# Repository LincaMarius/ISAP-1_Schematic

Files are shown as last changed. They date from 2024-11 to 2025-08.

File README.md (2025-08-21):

# ISAP-1 Computer Schematic
The ISAP-1 computer is the improved version of the SAP-1 computer made by me.

ISAP Computer stands for Improved Simple as Possible Computer

This is the stage of choosing the electronic components used to make the ISAP-1 computer and designing the Schematic.

By: Lincă Marius Gheorghe

https://github.com/LincaMarius

## About the project, brief description
The goal of this project is to create a more efficient version of the SAP (Simple As Possible) computer, but with minimal changes so that the instruction format remains the same.

This project is part of a project made by me:
https://github.com/LincaMarius/ISAP-Computer

where I optimized the SAP-1 computer

## ISAP-1 TTL Computer version 0.1
Version 0.1 of the ISAP-1 computer is based on the original SAP-1 computer schematic.

The structure of the SAP-1 computer and by implication the ISAP-1 computer is:

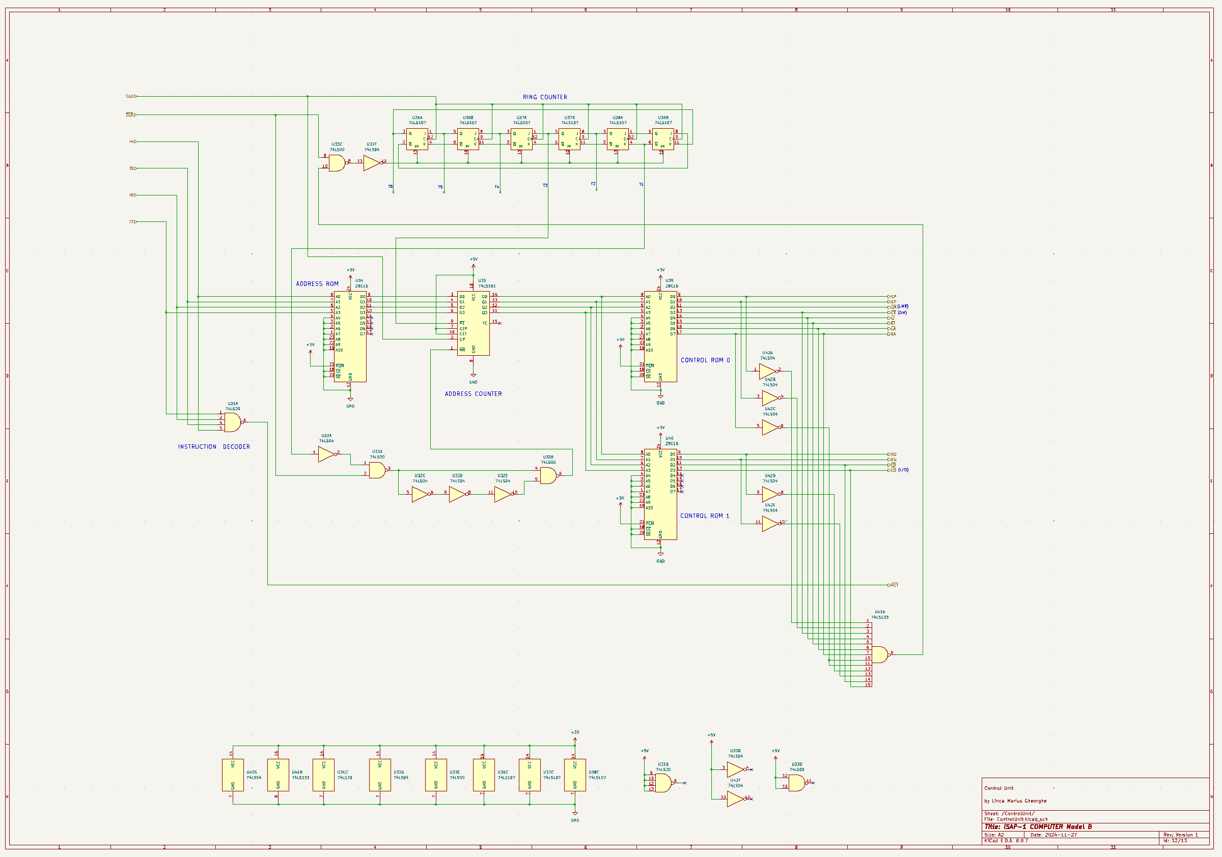
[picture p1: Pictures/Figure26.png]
Figure 26


I want to make the ISAP-1 computer in modular form. So I modified the Structural Diagram like this:

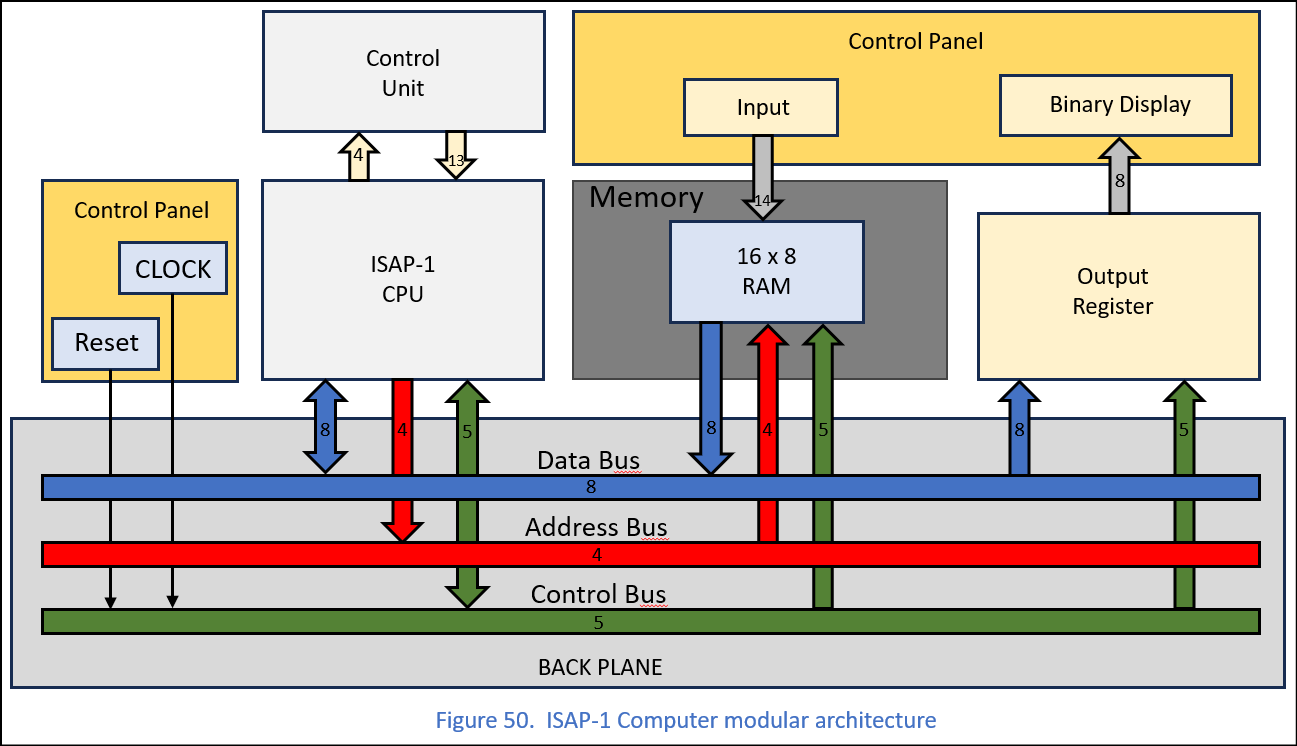
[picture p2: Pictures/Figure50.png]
Figure 50


It turns out that we will have the following modules:
- Reset and Clock
- ISAP-1 CPU
- Control Unit
- RAM Memory
- Output Display
- Back Plane

The SAP-1 computer was designed using 7400 series TTL chips in the LS (Low-Power Schottky) variant. Since version 0.1 of the ISAP-1 computer will be an almost identical copy of the SAP-1 computer, I will still use TTL technology.

I will keep the chip numbering order according to the original schematic of the SAP-1 computer.

### Central Processing Unit Schematic
The first module designed is the Central Processing Unit module.

The original block diagram of the Central Processing Unit of the SAP-1 computer and implicitly of the ISAP-1 computer is:

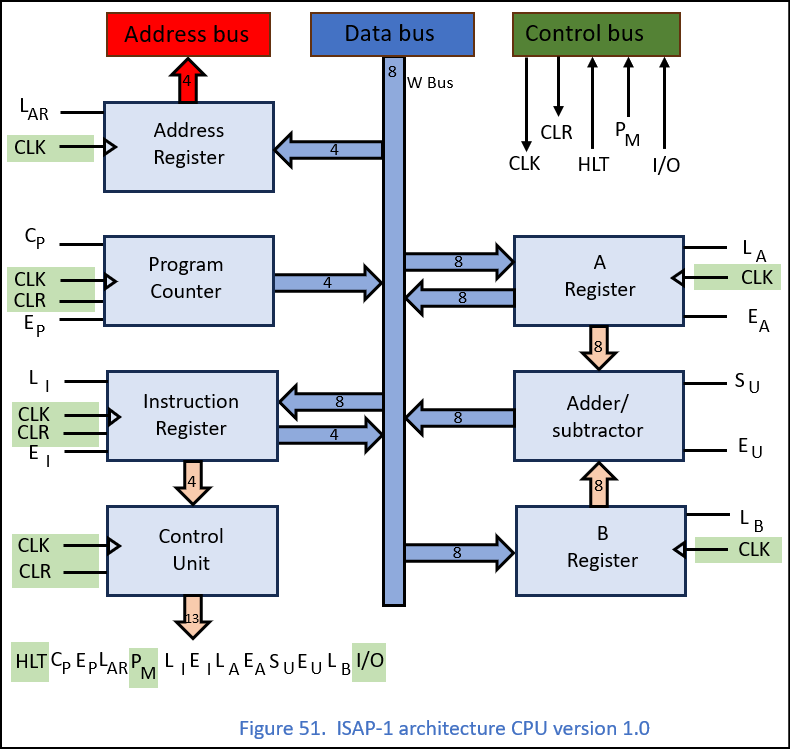
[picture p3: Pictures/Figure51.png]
Figure 51


Initially, I used Altium Designer to design the Schematic and PCB.

But, so that this schematic can be viewed and possibly edited by anyone, I put the version edited with KiCAD on GitHub, because this program is free and can be freely used by anyone.

The implemented schematic will be almost identical to the original one of the SAP-1 Computer.

In the original schematic the chips are labeled C1 to C48. To eliminate confusion with the capacitor notation I have used the chip notation U1 to U49 as is used in modern days.

First I will implement the Central Processing Unit which has the following schematic:

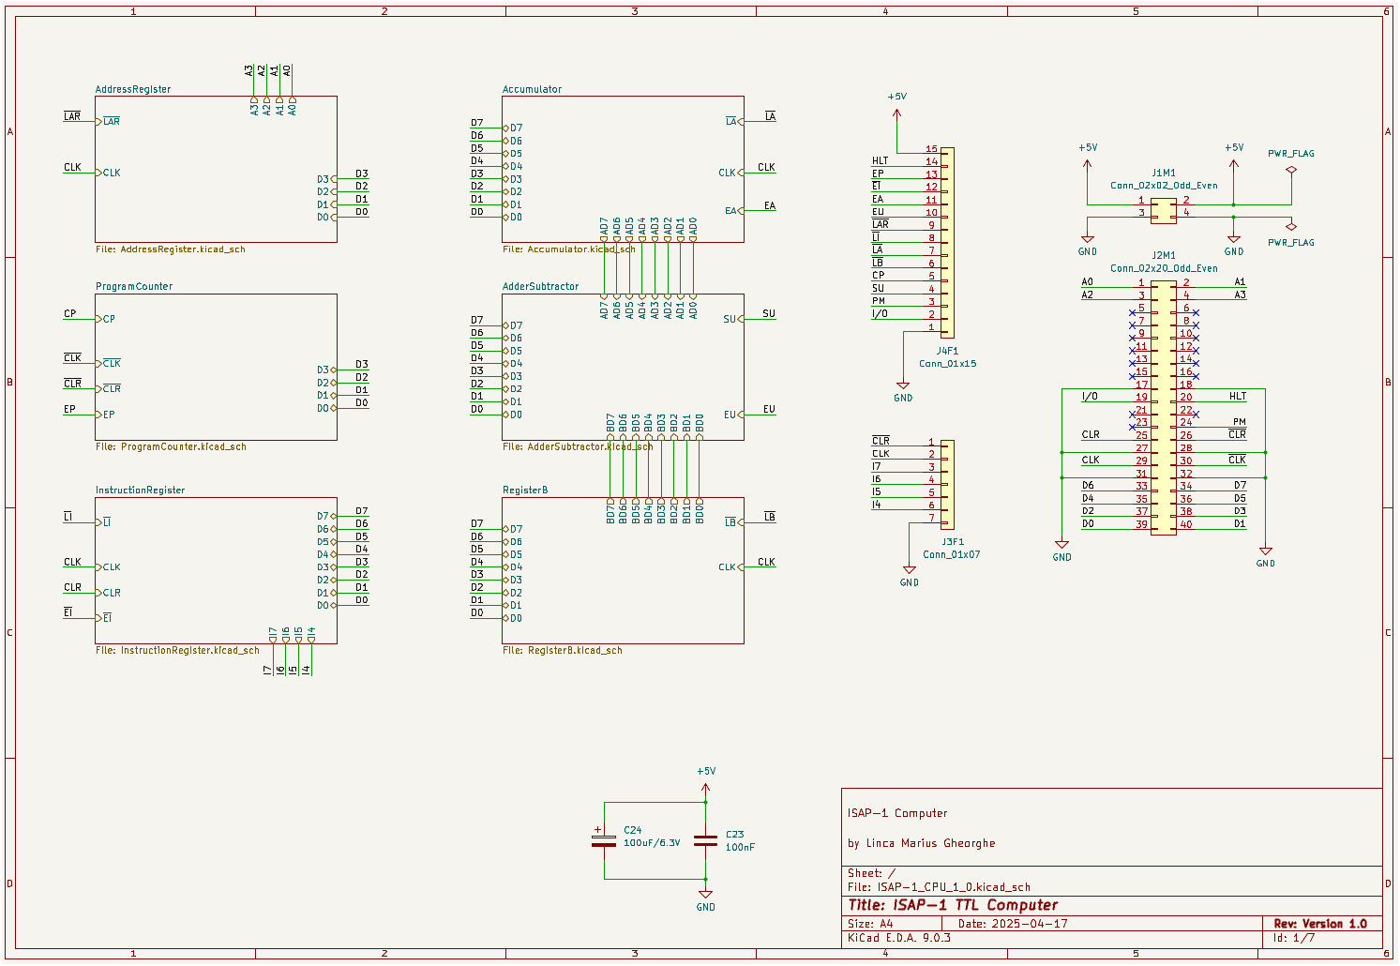
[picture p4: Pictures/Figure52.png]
Figure 52


You can see all the functional blocks in the diagram in figure 51. In addition I added decoupling capacitors for the power supply circuit. We also have the J1M connectors for connecting to the supply voltage given by the Back Plane, the J2M connector for connecting to the three system buses located on the Back Plane. The J3F and J4F connectors are used to allow the Control Block module to be attached to the CPU module.

#### Program Counter Schematic
In the original schematic, the authors used 4 Flip-Flops connected in such a way that they form a Binary Counter. For implementation, two 74LS107 were used for this purpose.

Counting is done when the CP control signal is active and the falling edge of the clock signal appears.

This action occurs for any instruction during [ microstep T2 ](https://github.com/LincaMarius/ISAP-1_Instruction_Set/blob/main/Pictures/Figure3.png).

The Program Counter has its output connected to the Bus, therefore it must be Tri-State. A 74LS126 chip is used for this purpose

The output is active only when the EP control signal is high.

This action occurs for any instruction during [ microstep T1 ](https://github.com/LincaMarius/ISAP-1_Instruction_Set/blob/main/Pictures/Figure3.png).

The Schematic does has no changes from the original one.

The original schematic has no decoupling capacitors for the chips. For the computer's operating speed of 1kHz this may not matter.

I added a 100nF decoupling capacitor for each chip used in order to eliminate high-frequency noise propagation along the power supply path.

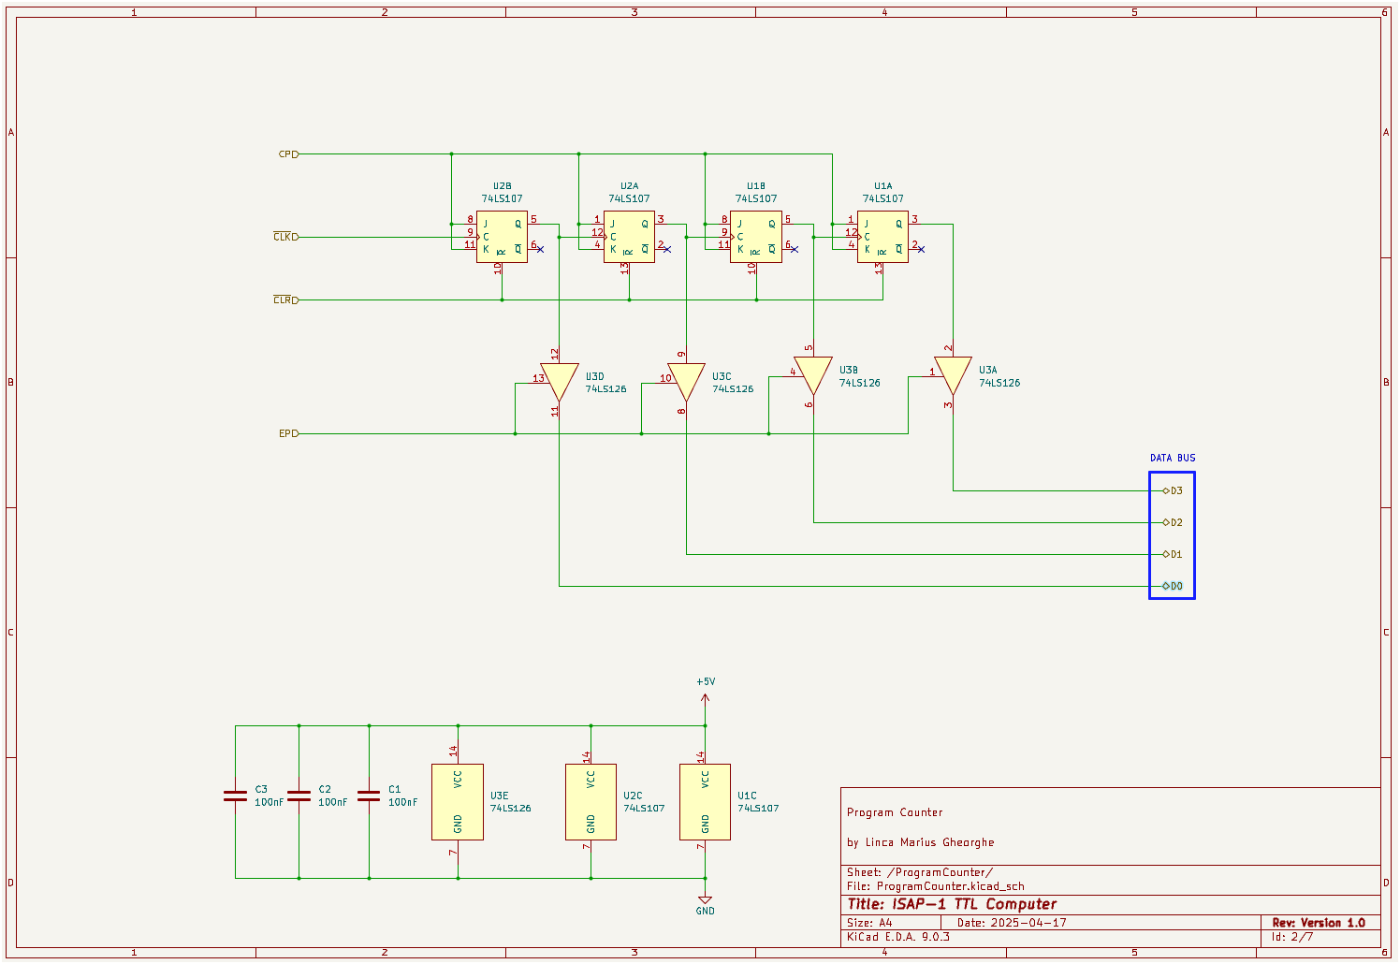
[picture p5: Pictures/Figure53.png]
Figure 53


#### Address Register Schematic
In the original schematic, the authors used a 4-bit register using the 74LS173 chip which has a permanently active output.

Note that the connection of the inputs to the data bus is in reverse order in the original SAP-1 computer schematic, D0 is connected to pin 11, D1 is connected to pin 12, D2 is connected to pin 13 and D4 is connected to pin 14.

The outputs are also connected in the reverse order. The operation of the SAP-1 computer is not affected by this order because the correspondence between inputs and outputs is maintained.

The current schematic has no changes from the original schematic.

I added a 100nF decoupling capacitor to the chip used in order to eliminate high-frequency noise propagation on the power supply path.

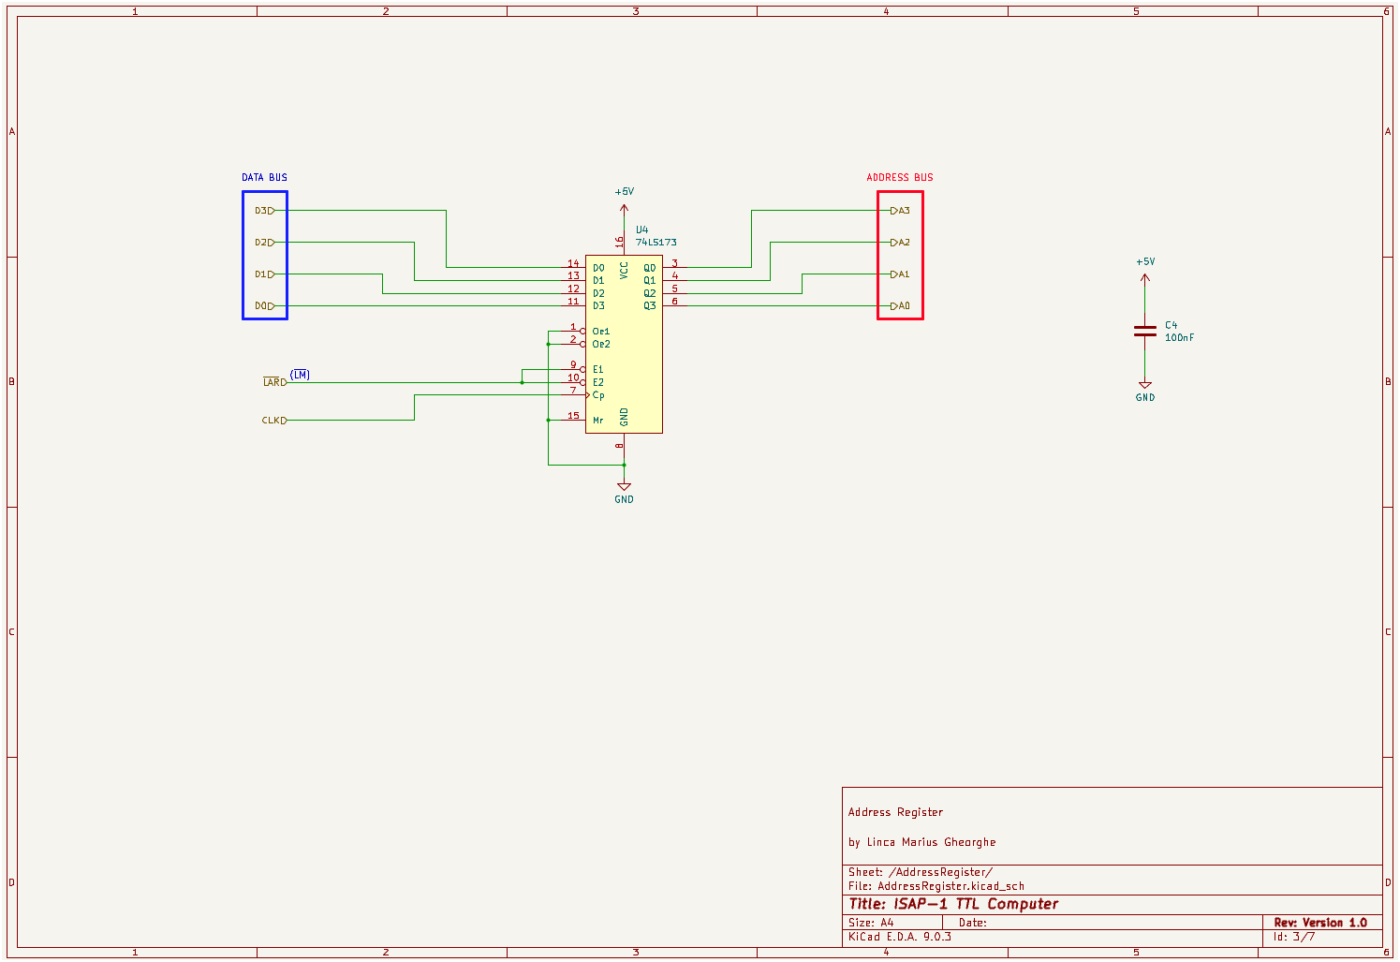
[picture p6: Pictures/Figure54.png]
Figure 54


#### Instruction Register Schematic
The Instruction Register is made using two integrated circuits of the 74LS173 type which is a 4-bit register.

The first chip marked U8 in the diagram stores the upper nibble which represents the binary code of the instruction being executed.

The second chip marked in the diagram U9 stores the lower nibble which represents the parameter for the instruction being executed.

According to the datasheet for the 74LS173 chip, pin 14 is D0 and the corresponding output Q0 is pin 3, pin 13 is D1 and the corresponding output Q1 is pin 4, pin 12 is D2 and the corresponding output Q2 is pin 4, and pin 11 is D3 and the corresponding output Q3 is pin 6.

But in the SAP-1 computer schematic, pin 14 which is D0 and pin 3 which is Q0 are connected to bit 3 of the W Bus, pin 13 which is D1 and pin 4 which is Q1 are connected to bit 2 of the W Bus, pin 12 which is D2 and pin 5 which is Q2 are connected to bit 1 of the W Bus and pin 11 which is D3 and pin 6 which is Q3 are connected to bit 0 of the W Bus.

So, the order of inputs and outputs is reversed. Since the inputs and outputs are also reversed accordingly, the operation of the SAP-1 computer is normal.

The schematic does not present any changes from the original.

I added a 100nF decoupling capacitor for each chip used in order to eliminate high-frequency noise propagation along the power supply path.

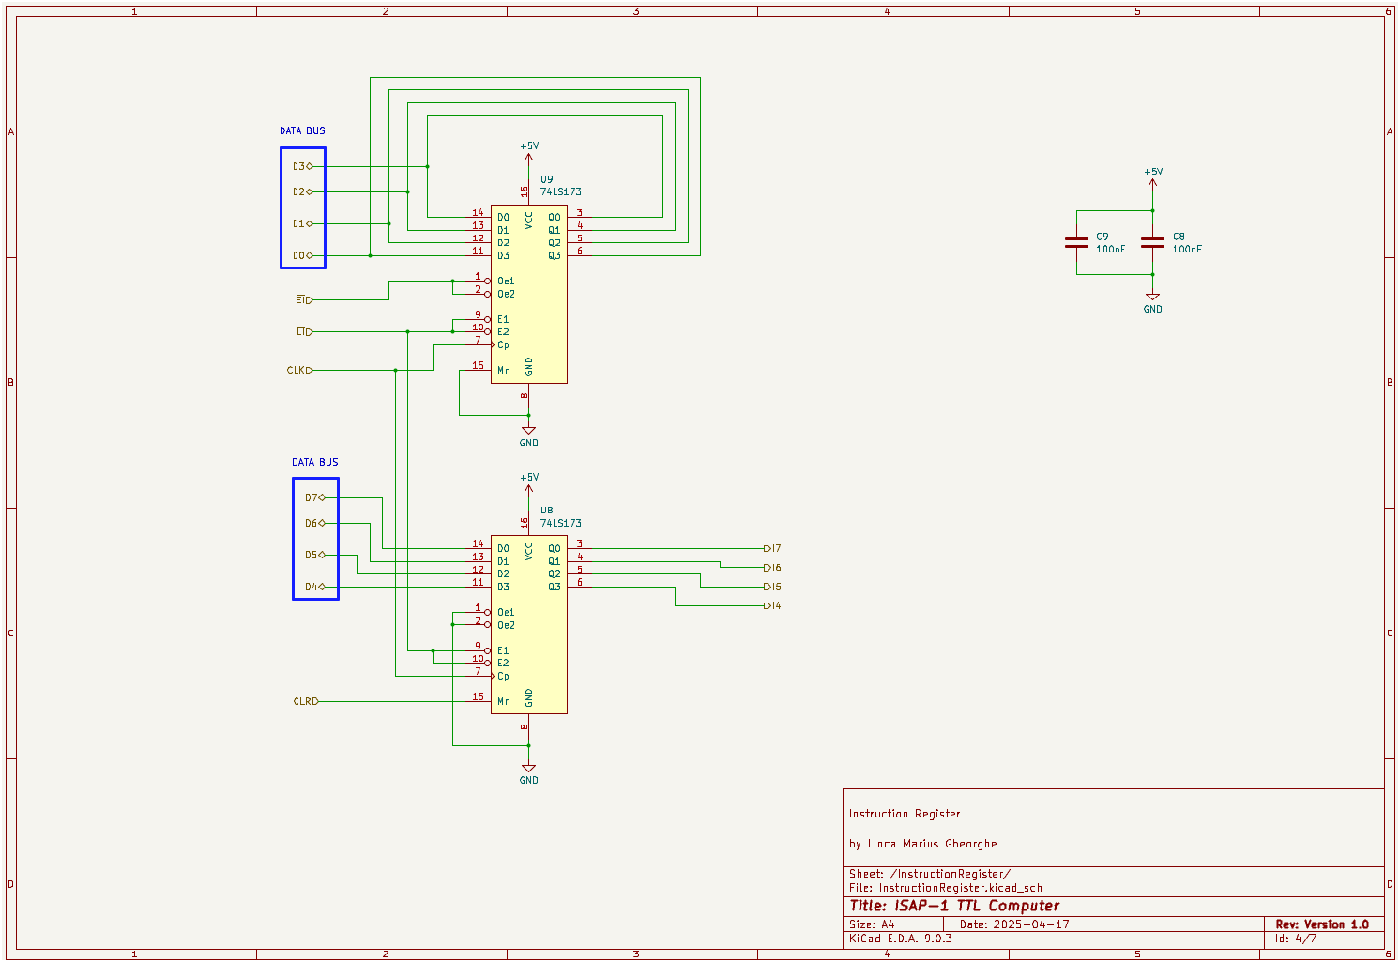
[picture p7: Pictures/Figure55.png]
Figure 55


#### Accumulator Register Schematic
The Accumulator register is made using two 4-bit 74LS173 type registers marked U10 and U11 in the diagram (in the original diagram they are marked C10 and C11).

Pin 1 and pin 2 are connected to ground which causes the outputs to be permanently active. Thus, the contents of the Accumulator Register are permanently transmitted to the ALU via signals AD0 to AD7.

The contents of the Accumulator Register are put on the bus when the EA control signal is active, which activates the 8 Tri-State drivers. The Tri-State drivers are implemented using two 74LS126 chips, each containing 4 Tri-State drivers.

As in the previous cases, the order of inputs and outputs is reversed from the order of the bits on the W bus. Since the inputs and outputs are also reversed accordingly, the operation of the SAP-1 computer is normal.

The schematic has no changes from the original.

I added a 100nF decoupling capacitor for each chip used in order to eliminate high-frequency noise propagation along the power supply path.

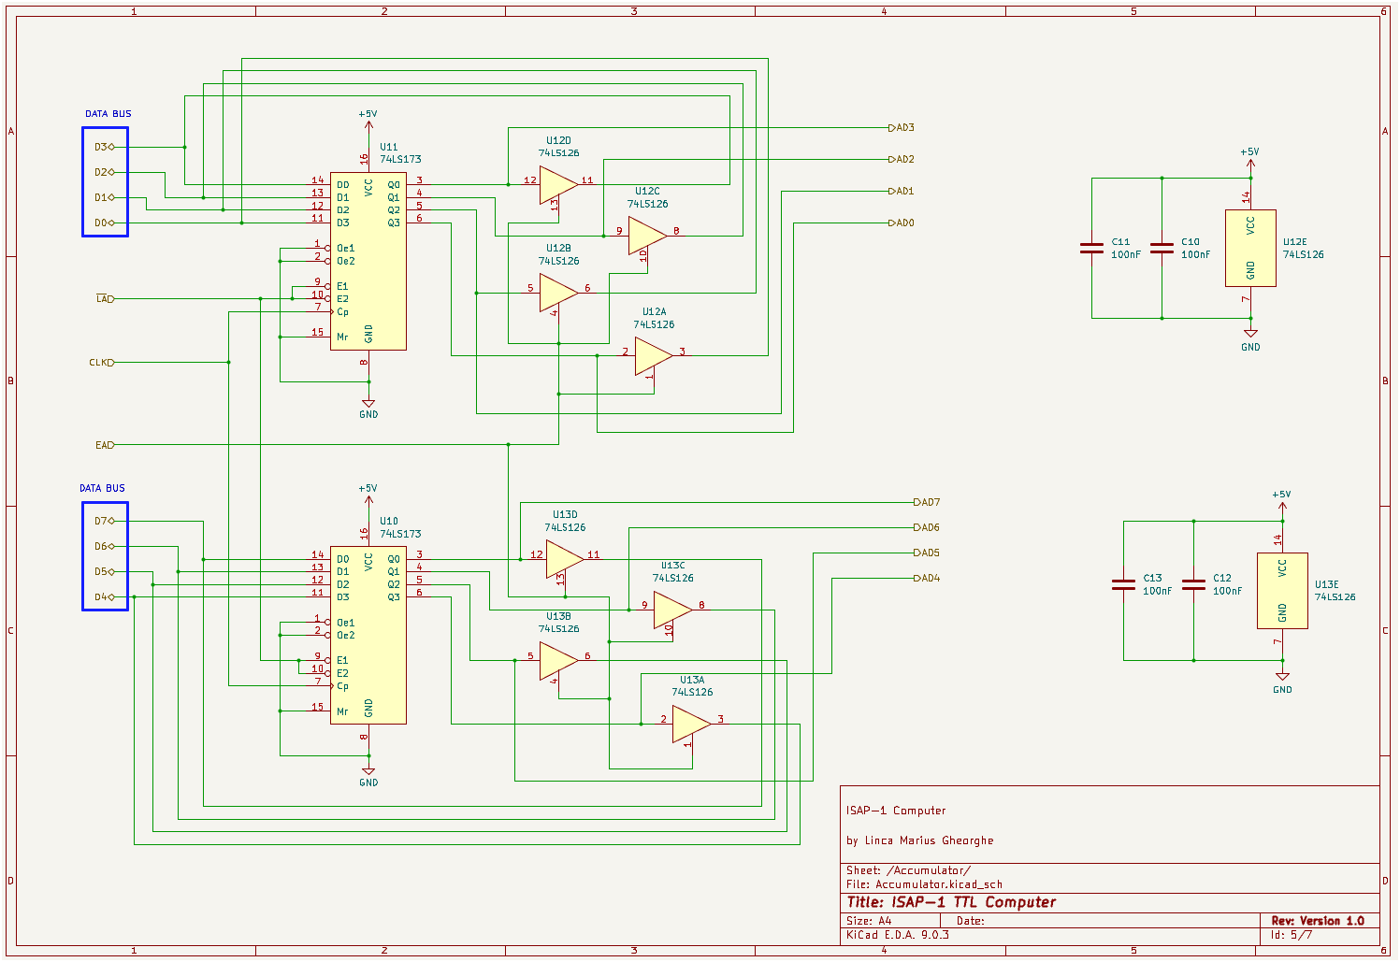
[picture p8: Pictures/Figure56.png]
Figure 56


#### Adder / Subtractor Schematic
The SAP-1 computer has no Logic Unit, it can only perform the Addition and Subtraction operations.

The main element of the Arithmetic Unit is the 74LS83 chip which is a 4-bit Full Adder, so two such chips are used.

The Subtract Operation is performed by 2's Complementing the operand B. For this purpose, 8 x XOR Gates are used. Each 74LS86 chip has 4 gates, so 2 chips are used.

The result is transmitted on the Bus via 8 three-state buffers when the EU control signal is active. These buffers are of the 74LS126 type. Each chip has 4 buffers, so 2 chips are required.

The schematic has no changes from the original.

I added a 100nF decoupling capacitor for each chip used in order to eliminate high-frequency noise propagation along the power supply path.

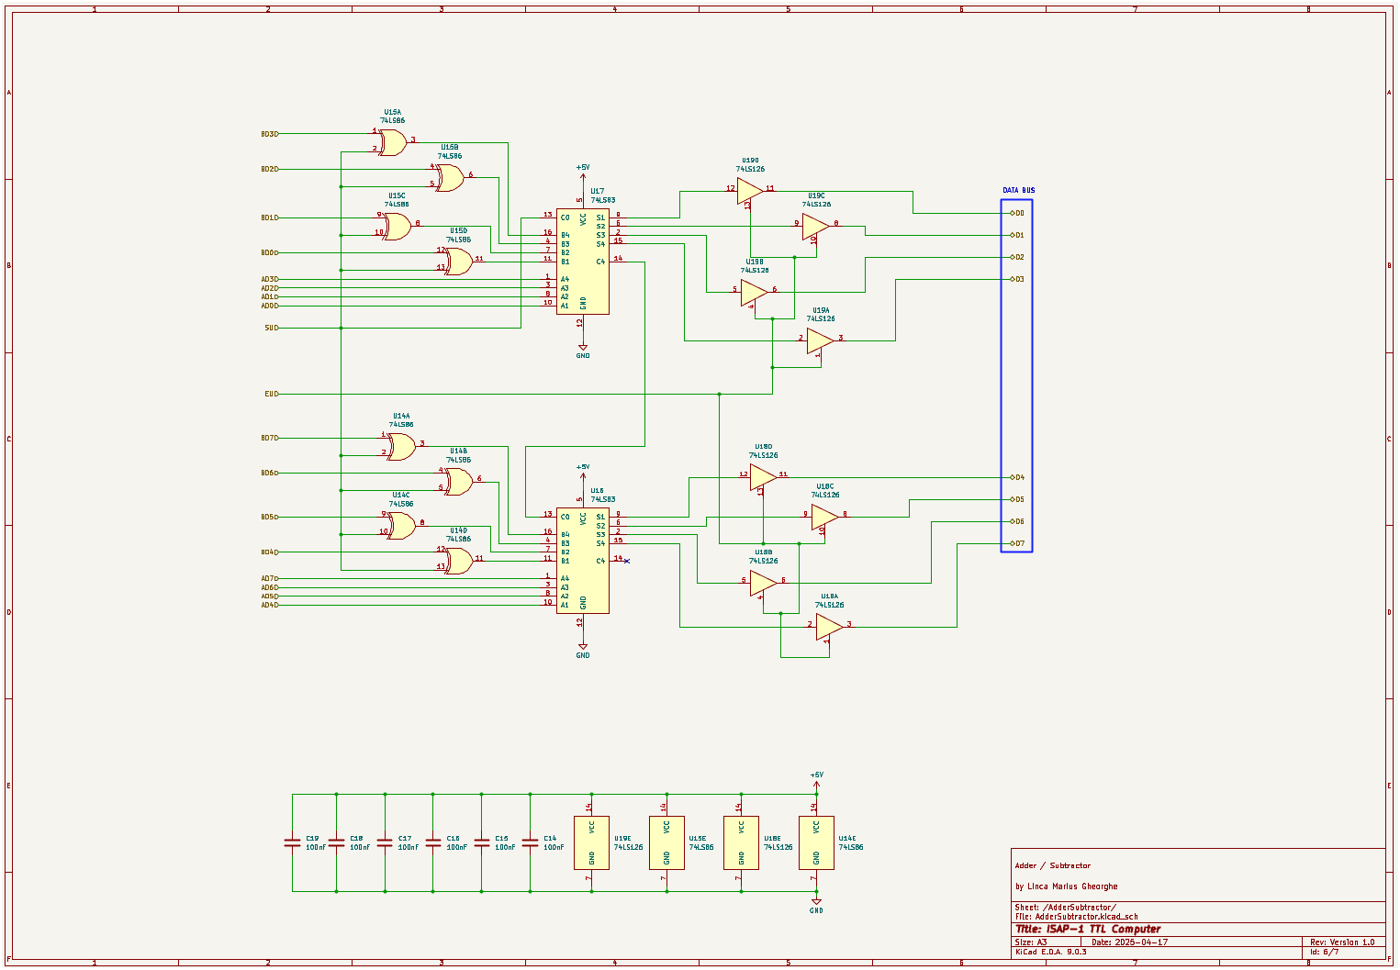
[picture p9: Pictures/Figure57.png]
Figure 57


#### Register B Schematic
Register B acts as a temporary storage register, where the operand B required by the Adder to perform the Addition operation is loaded.

In the original schematic, two 4-bit 74LS173 type registers labeled C20 and C21 are used.

When the LB control signal is low and the rising edge of the clock signal occurs, the data present on the Bus is loaded into the registers.

The output is connected to input B of the Adder and is permanently enabled by connecting pins 1 and 2 to ground.

The schematic has no changes from the original.

I added a 100nF decoupling capacitor for each chip used in order to eliminate high-frequency noise propagation along the power supply path.

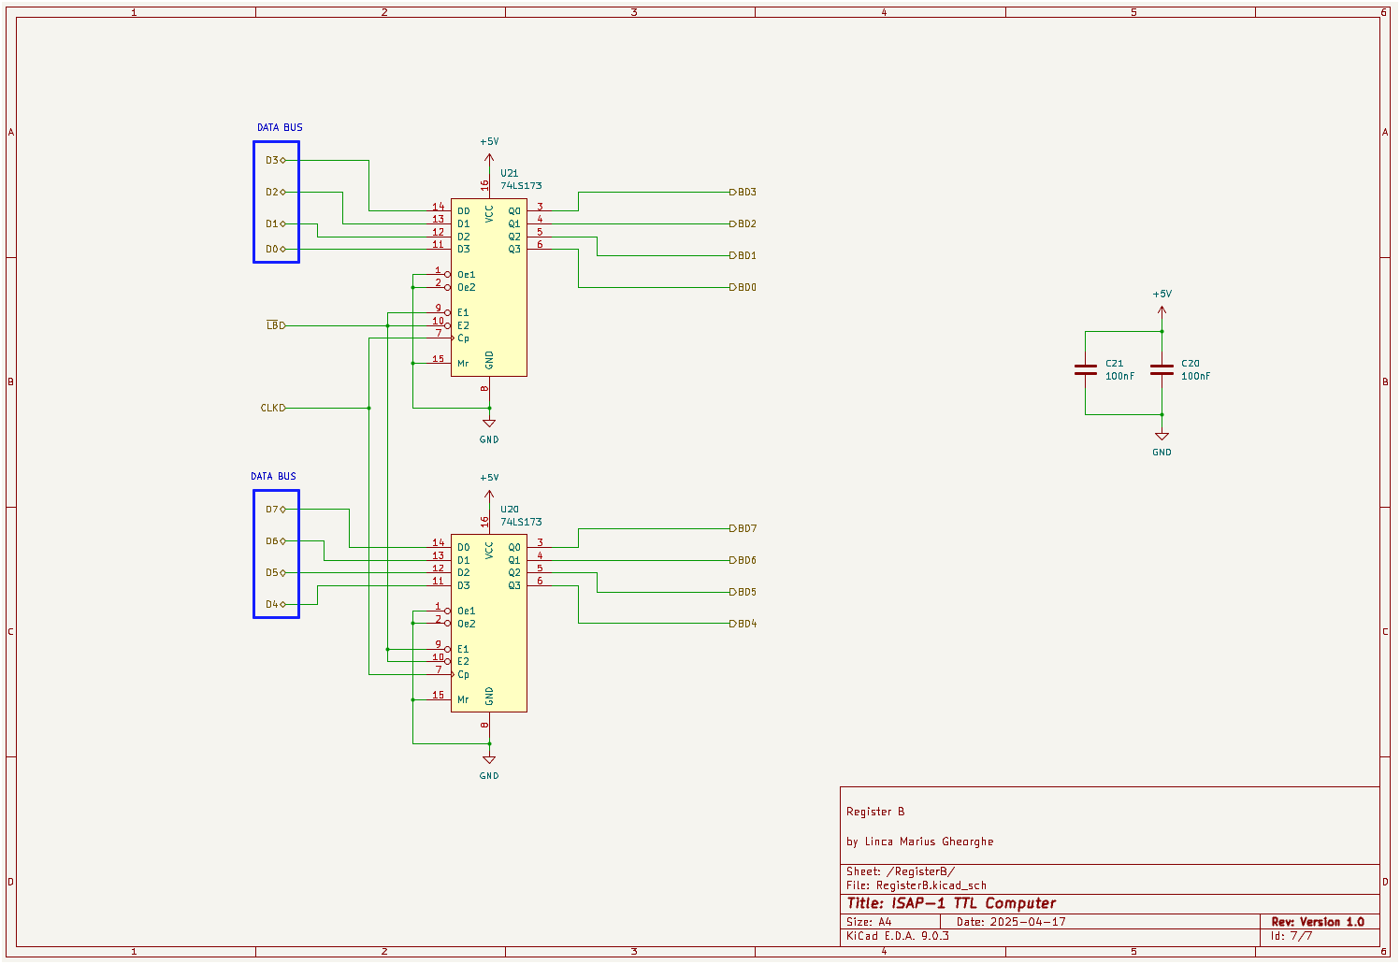
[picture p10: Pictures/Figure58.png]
Figure 58


The archived project for ISAP-1 TTL Computer version 0.1 is here: \
https://github.com/LincaMarius/ISAP-1_Schematic/blob/main/KiCAD/ ISAP-1_TTL_CPU_1_0.zip

### Control Unit Schematic
The Control Unit's role is to direct the flow of data between the various Blocks of the Computer to ensure its operation and achieve the expected results.

It consists of three elements: the Instruction Decoder, the Ring Counter and the Control Matrix as can be seen in figure 14:

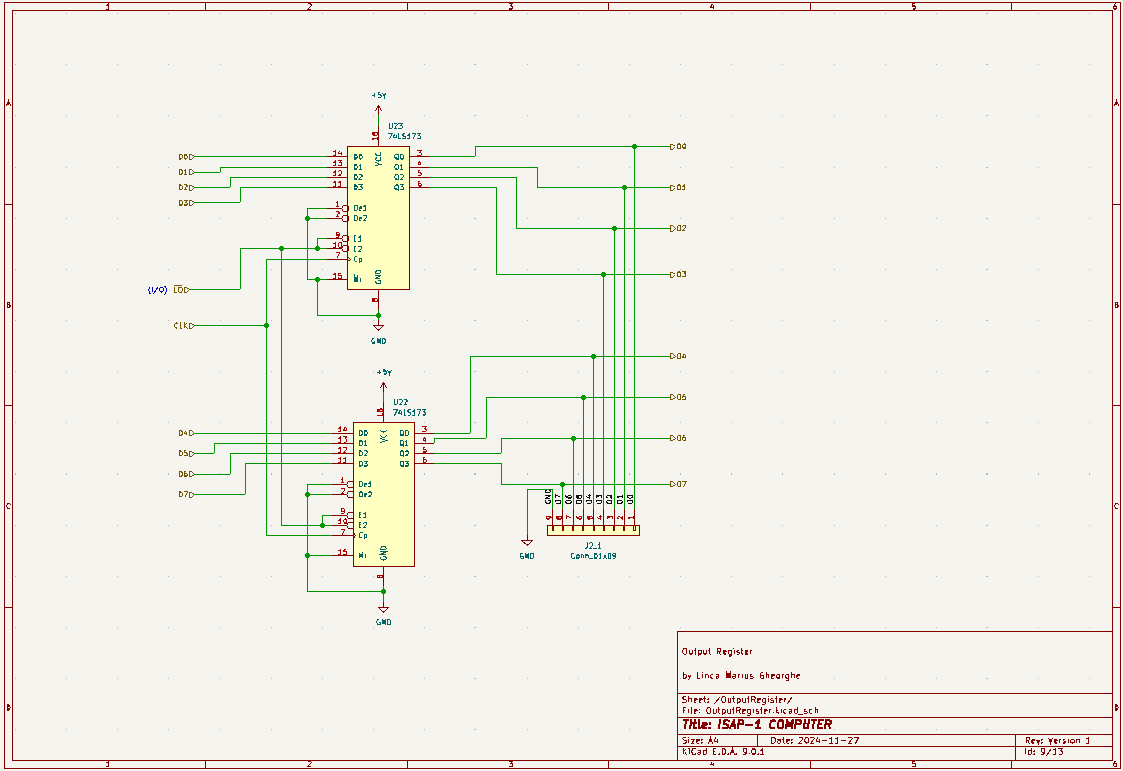
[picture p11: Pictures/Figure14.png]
Figure 14


### Output Device – Binary Display
In the SAP-1 computer the output device is called the Output Register and is present in the Block Diagram at the bottom right of the drawing.

The Binary Display is made with 8 LEDs connected directly to the output of the Output Register.

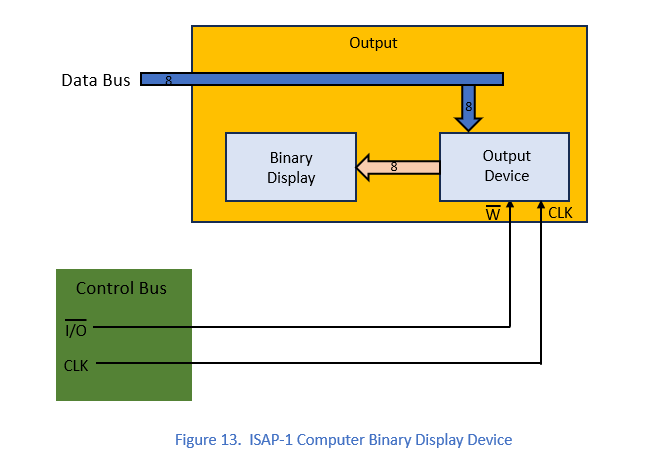
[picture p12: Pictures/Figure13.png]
Figure 13


### Output Device Schematic
In the original schematic, two 4-bit 74LS173 registers are used, denoted C22 and C23.

When the I/O control signal (the original LO) is low and the rising edge of the clock signal appears, the data present on the Bus is loaded into the registers.

The output is permanently active because pins 1 and 2 are connected to ground. The outputs are labeled O0 to O7.

I added the connectors marked J2_1 and J2_2 for connection to the Base PCB in case the Binary Display PCB separates from the computer PCB.

The schematic does not present any other changes compared to the original one.

Figure 14

### Binary Display Schematic
The Binary Display consists of eight LEDs connected to eight current limiting resistors of 1k ohm each.

The current is limited by resistors for a red LED to the value of (Voh – Vled) / (R + Rint) = (2.4V – 1.8V) / (1000 + 100) = 0.5 / 1100 = 0.5mA (theoretical).

I added the connectors marked J2_1 and J2_2 for connection to the Base PCB in case the Binary Display PCB separates from the computer PCB.

The schematic does not present any other changes compared to the original one.

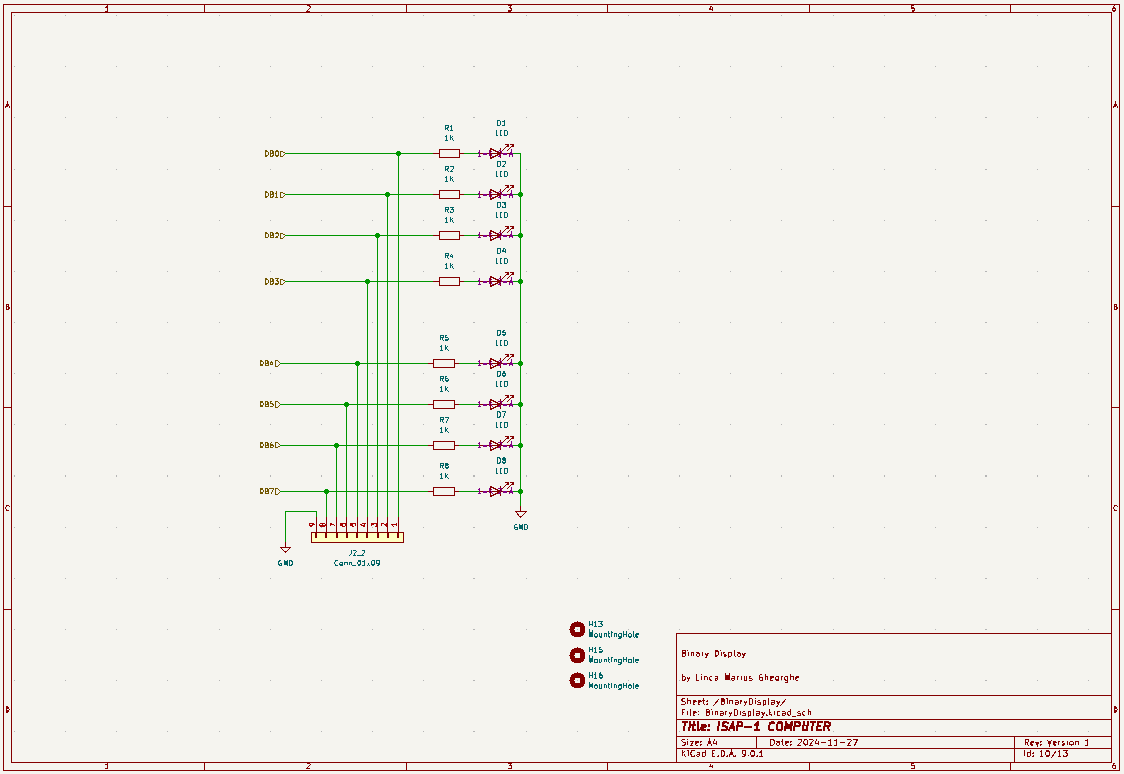
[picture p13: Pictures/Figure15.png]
Figure 15


### Front Panel Schematic
The Front Panel provides the user interface. Contains the Reset circuit, Manual/Automatic mode selector, Step button, main clock.

I added two connectors marked J5_1 and J5_2 for connection to the Base PCB in case the Front Panel PCB is separated and used separately from the ISAP-1 computer PCB.

The switches can be mounted on this PCB or mounted on a Front Panel and connected via wires.

The schematic does not present any other changes compared to the original one.

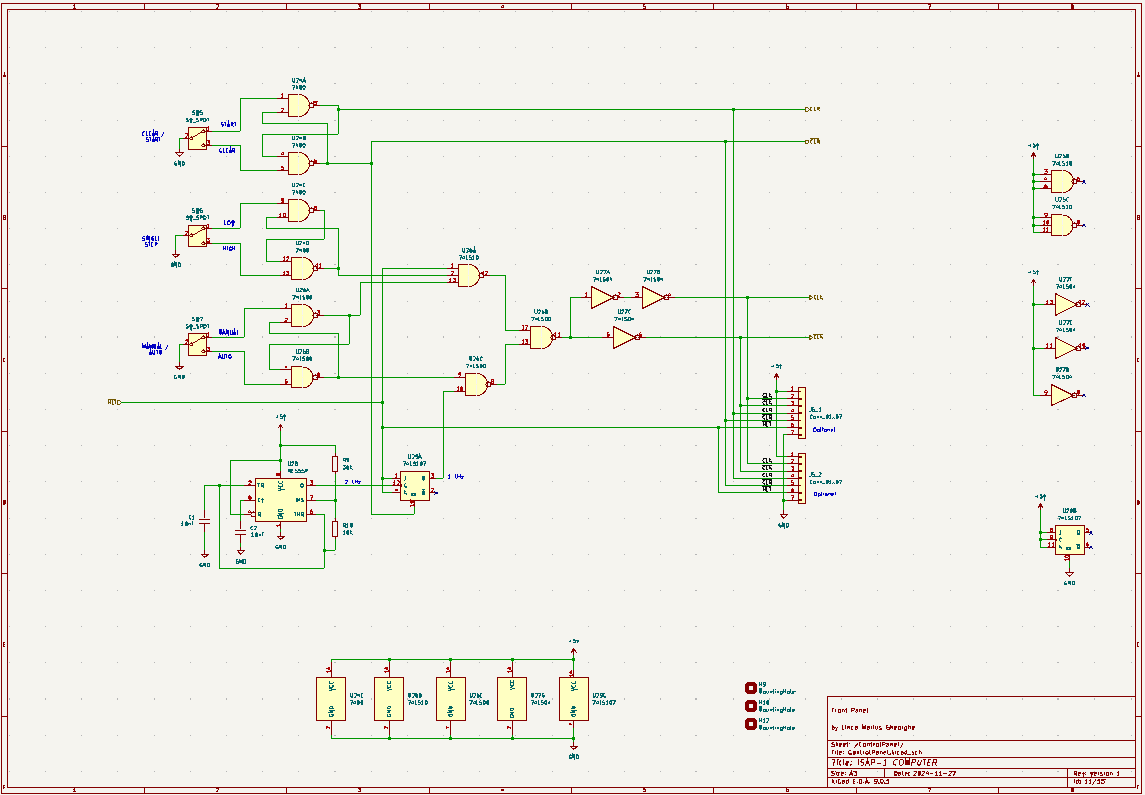
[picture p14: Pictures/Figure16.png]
Figure 16


The switches used to set the Memory in Programming mode must also be placed on the Front Panel.

The switches can be mounted on this module or mounted on a Front Panel and connected via wires.

### Control Unit Schematic
The Control Unit's role is to direct the flow of data between the various Blocks of the Computer to ensure its operation and achieve the expected results.

It consists of three elements: the Instruction Decoder, the Ring Counter and the Control Matrix as can be seen in figure 17:

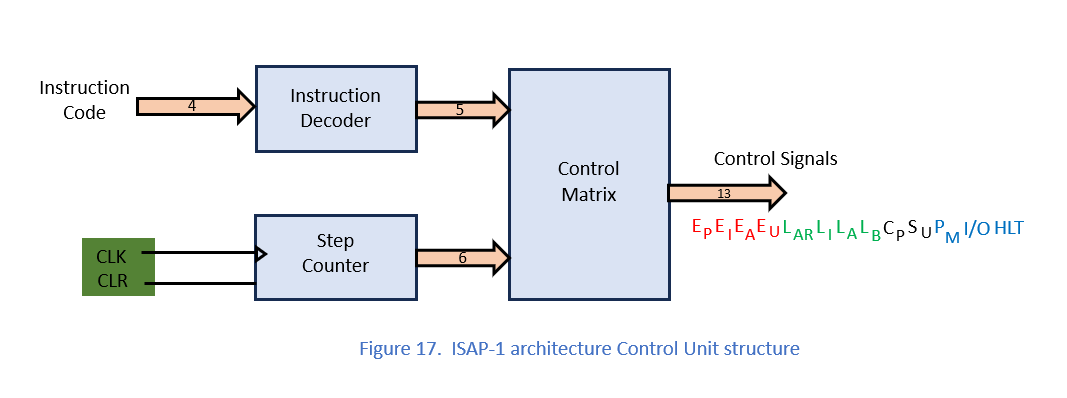
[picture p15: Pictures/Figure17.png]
Figure 17


The schematic does not present any other changes compared to the original one.

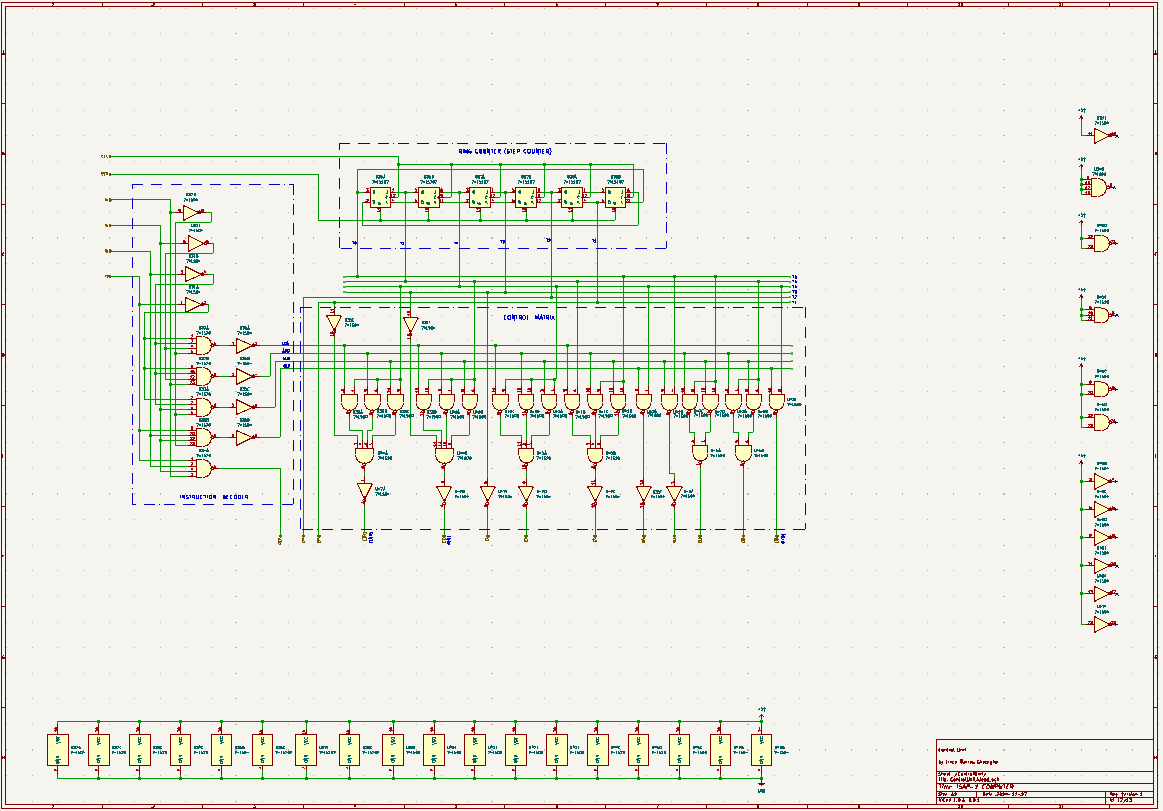
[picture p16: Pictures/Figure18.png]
Figure 18


### Power Supply Schematic 
The power supply's role is to provide the 5 Volt supply voltage and support the computer's power consumption.

This power supply is powered directly from the Mains and consists of a step-down transformer followed by a full bridge rectifier and an integrated regulator of 5 Volts.

The transformer according to the Bill of Materials is of the F-25X type and has a primary voltage of 115 Volts, but in Europe a transformer with a primary voltage of 230 Volts is required.

The secondary voltage according to the Materials List on page 502 in the original book is 12.6 Volts. Nowadays we can buy standard transformers with a secondary voltage of 12 Volts.

The secondary current is a maximum of 1.5 Amps according to the same description.

The nominal power of the transformer for a current consumption of maximum 1.5 Amps is 12V x 1.5A = 18 VA.

The maximum voltage on capacitor C68 is: Vmax = Vsec * 1.41 – 2 * Vd = 12 * 1.414 – 2 * 0.8 = 16.97 – 1.6 = 15.37 Volts

Therefore, capacitor C68 must have a working voltage of 25 Volts.

The voltage ripple on the filter capacitor C68 is: dU = (Iout * T) / (2 * C3)

For a mains voltage frequency of 50 Hz we have T = 1/f = 1/50 = 0.02 s

For a mains voltage frequency of 60 Hz we have T = 1/f = 1/50 = 0.017 s

Since we have a double alternating rectification the pulsation frequency is doubled, so the period is halved

Thus the ripple period is: T = 0.01s for mains voltage with a frequency of 50 Hz and T = 0.0083s for mains voltage with a frequency of 60 Hz.

The voltage ripple on the filter capacitor C68 is: dU = (1.5A * 0.01s) / (2 * 0.001F) = 0.015 / 0.002 = 7.5 Volts for mains voltage with a frequency of 50 Hz.

The voltage ripple on the filter capacitor C68 is: dU = (1.5A * 0.0083s) / (2 * 0.001F) = 0.01245 / 0.002 = 6.225 Volts for mains voltage with a frequency of 60 Hz.

The minimum voltage on the filter capacitor C68 is: Vmin = Vmax – dU = 15.37V – 7.5V = 7.87 Volts for mains voltage with a frequency of 50 Hz.

The minimum voltage on the filter capacitor C68 is: Vmin = Vmax – dU = 15.37V – 6.225V = 9.145 Volts for mains voltage with a frequency of 60 Hz.

The average voltage on the filter capacitor C68 is: V = Vmax – dU/2 = 15.37V – 7.87V/2 = 15.37V – 3.935V = 11.435 Volts for mains voltage with a frequency of 50 Hz.

The average voltage on the filter capacitor C68 is: V = Vmax – dU/2 = 15.37V – 6.225V/2 = 15.37V – 3.1125V = 12.2575 Volts for mains voltage with a frequency of 60 Hz.

The maximum power dissipated by the LM340T-5 or LM7805 integrated regulator is: P = (Vin – Vout) * I = (11.435V – 5V) * 1.5A = 6.435V * 1.5A = 9.66 Watts for mains voltage with a frequency of 50 Hz.

The maximum power dissipated by the LM340T-5 or LM7805 integrated regulator is: P = (Vin – Vout) * I = (12.2575V – 5V) * 1.5A = 7.2575V * 1.5A = 10.87 Watts for mains voltage with a frequency of 60 Hz.

To dissipate this power, we have provided a radiator to cool the integrated stabilizer. Otherwise, it will go into overtemperature protection.

I added a 100nF ceramic capacitor to the input and output of the integrated voltage regulator to meet the stability requirements according to the datasheet data.

The schematic does not present any other changes compared to the original one.

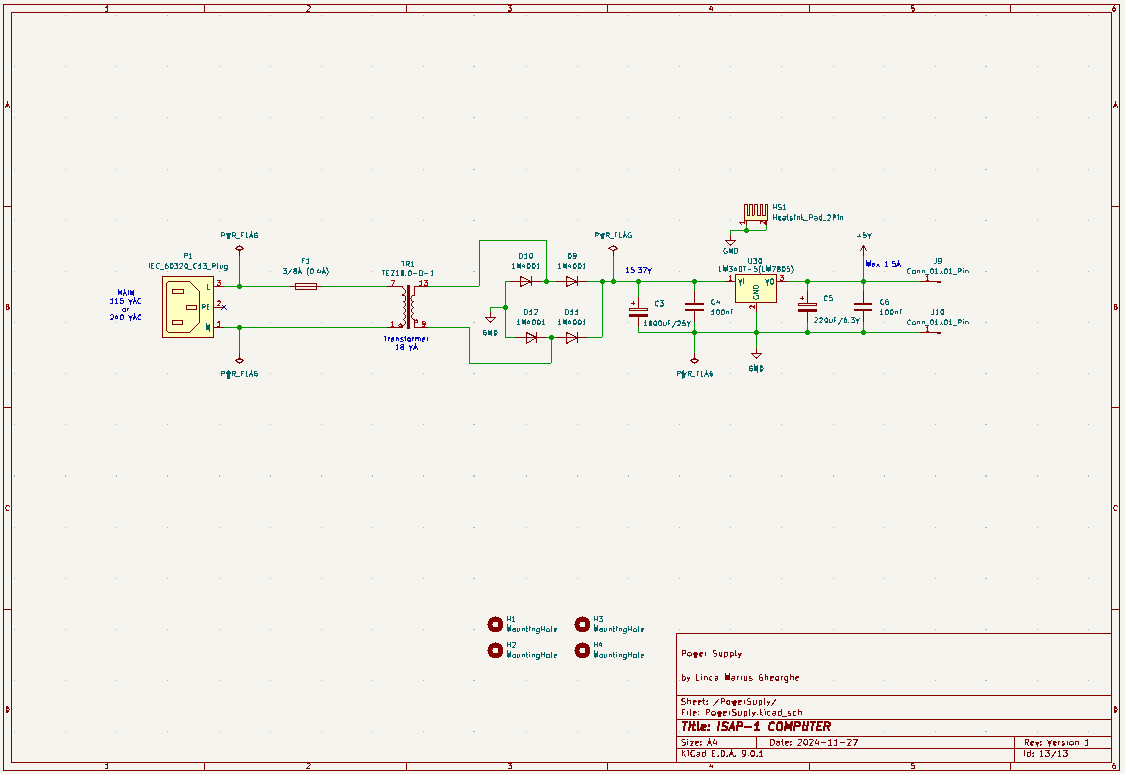
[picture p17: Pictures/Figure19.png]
Figure 19


### ISAP-1 TTL SBC assembly
To power the computer with 5 volts, I included a Barrel Jack.

The schematic does not present any other changes compared to the original one.

An overview of the PCB for the Single Board Computer variant of the ISAP-1 Computer is shown in the following figure:

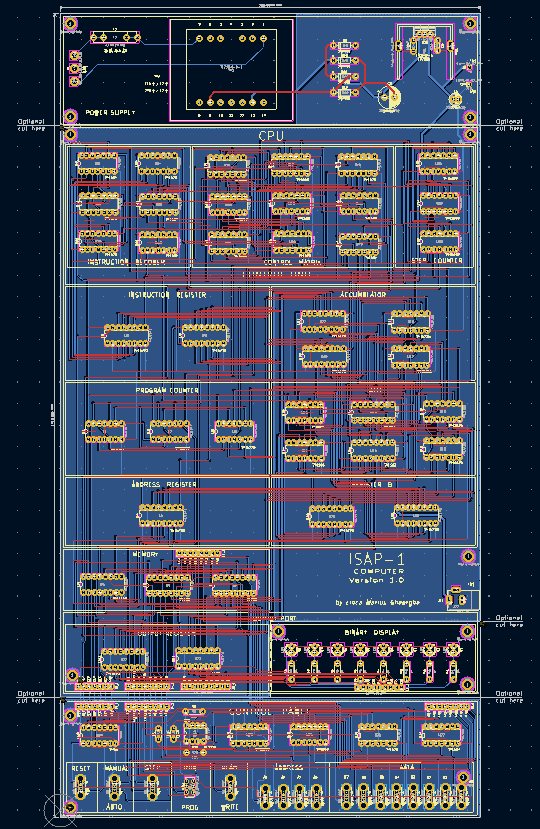
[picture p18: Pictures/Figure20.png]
Figure 20


An overview for the ISAP-1 TTL SBC Computer is shown in the following figure:

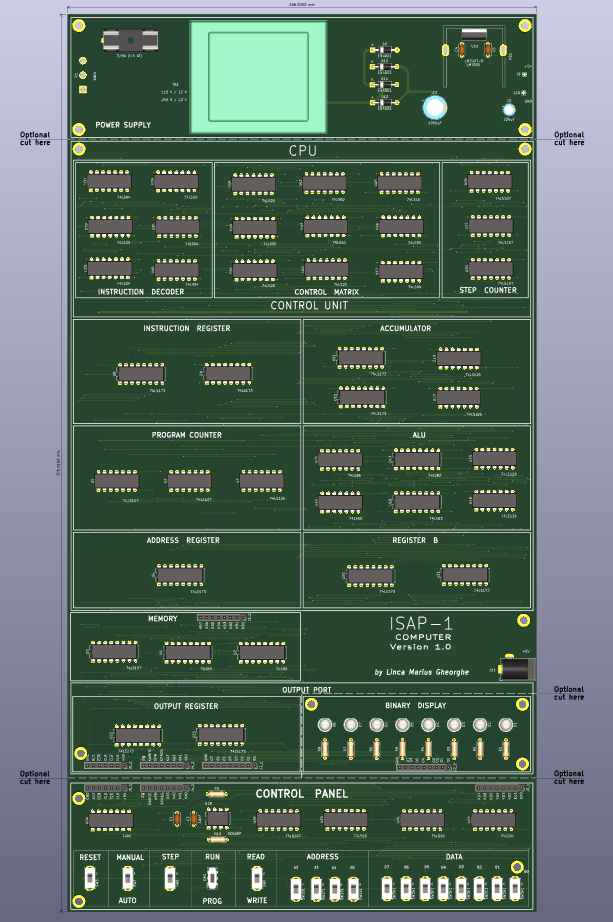
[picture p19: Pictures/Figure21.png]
Figure 21


The ISAP-1 computer project made in KiCAD is here: \
https://github.com/LincaMarius/ISAP-1_Schematic/tree/main/KiCAD/ISAP1_TTL_SBC_ver1_0.zip

*A total of 48 chips were used to implement this version of the ISAP-1 computer.*

## ISAP-1 Model A Version 1.1
In Version 1.1, an improvement is made to the ISAP-1 computer by implementing the Variable Machine Cycle.

The Instruction Set remains unchanged but the Control Block implementation changes.

In the book on page 163 the authors present a method of improving the SAP-1 Computer by implementing the Variable Machine Cycle.

The schematic is shown in Figure 10-17 and consists of 5 inverters and a 12-input NAND gate that generates the #NOP signal when the Control Block output has the NOP instruction encoded in Hexadecimal as 3E3h and a two-input AND gate that resets the Ring Counter when the #NOP or #CLR signal is low. 

We can note that the SAP-1 Computer schematic is not modified to implement this functionality, only two logic gates are added.

### Control Block Update
Version 1.1 of the ISAP-1 computer presents the modification of the Control Block as described by the authors, which implements Variable Length Microcode.

The schematic is modified by adding 2 gates and 5 inverters, but it is not necessary to redesign the computer.

The starting point is the Control Block diagram of version 1.0 shown in figure 15.

The scheme presented in the book to be implemented is intended for a control matrix made with ROM memory.

Because in the current version we use logic gates to implement the control matrix, we have greater freedom to select the signals we are interested in.

The signals CP, PE, EA, SI and EU must be inverted.

The CP signal is T2 and must be inverted.

The EP signal is T1, so the inverted EP is the inverted T1. This is available at the output of the inverter U35E.

The EA signal is the output of gate U42A inverted by U35F, so if EA is inverted once more it is the same signal as that available before the double inversion, i.e. the signal from the output of gate U42A can be used directly without inversion.

The SU signal is the output of gate U42B inverted by U48A, so if SU is inverted once more it is the same signal as that available before the double inversion, i.e. the signal from the output of gate U42B can be used directly without inversion.

The EU signal is the output of gate U42B and must be inverted.

In conclusion, only the CP and EU signals need to be inverted.

All of these signals act as inputs to a 12-input NAND gate.

For implementation, a 12-input NAND gate of the 74S134 type, a 13-input NAND gate of the 74ALS133 type can be used.

Another variant is using:
- one 8-input NAND part of the 74LS30 type, one 4-input NAND part of the 74LS20 type and one 2-input OR part of the 74LS32 type
- three 4-input NAND parts of the 74LS20 type, one 3-input NOR part of the 74LS27 type and one 74LS04 type inverter
- four 3-input NAND parts of the 74LS10 type, one 4-input NOR part of the 74LS29 type and one 74LS04 type inverter
- or six 2-input NAND parts of the 74LS00 type, three 3-input NOR parts of the 74LS27 type and one 74LS04 type inverter

I implemented the new version using the available logic gates that were not used by the authors of the book, so I added only one chip.

I used the U48B inverter and the U48C inverter to invert the CP and EU signals.

I used the 74LS133 chip which is a 13-input NAND gate.

For the reset signal control, instead of adding a new 74LS08 chip to use a single AND logic gate, I used an available two-input 74LS00 NAND gate marked U43D and inverted its output signal with the U48D inverter.

The Control Block schematic of the ISAP-1 Model A Version 1.1 computer is shown in the following figure:

Figure 20

This is what the completed PCB looks like for ISAP-1 Model A Version 1.1

Figure 21

An overview of the PCB is shown in the following figure

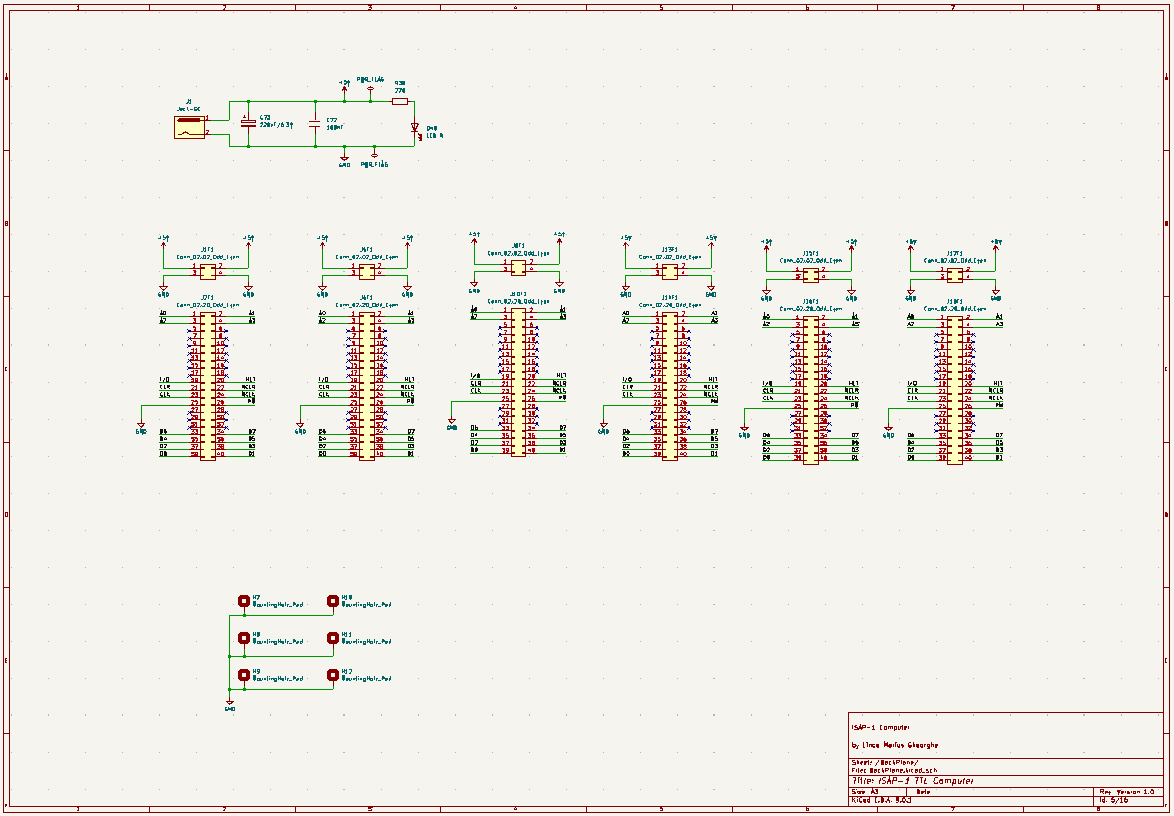
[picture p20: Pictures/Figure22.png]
Figure 22


The ISAP-1 Model A Version 1.1 computer project made in KiCAD is here: \
https://github.com/LincaMarius/ISAP-1_Schematic/blob/main/KiCAD/ISAP-1_modelA_ver1_1.zip

*A total of 49 chips were used to implement this version of the ISAP-1 computer. One more than in the previous implementation.*

## ISAP-1 Model B version 1.0
Revision B of the ISAP-1 computer presents the modification of the Control Block as described by the authors, whereby the hard-wired logic is replaced with programmed logic.

In previous implementations, 18 chips were used in the Control Block.

One solution for implementation at the time the card was published in 1975 was to use the 74S188 (32 x 8 PROM open-collector), 74S288 (32 x 8 PROM tree-state), 74S387 (256 x 4 PROM open-collector), 74S287 (256 x 4 PROM tree-state), 74S470 (256 x 8 PROM open-collector), 74S471 (256 x 8 PROM tree-state), 74S473 (512 x 8 PROM open-collector), 74S472 (512 x 8 PROM tree-state), 74S475 (512 x 8 PROM open-collector), 74S474 (512 x 8 PROM tree-state), 74S451 (1024 x 8 PROM open-collector), 74S450 (1024 x 8 tree-state PROM), 74S479 (1024 x 8 open-collector PROM), 74S478 (1024 x 8 tree-state PROM), 74S3708 (1024 x 8 open-collector PROM), 74S2708 (1024 x 8 tree-state PROM), 74S477 (1024 x 4 open-collector PROM), 74S476 (1024 x 4 tree-state PROM).

But these chips are no longer manufactured and even if we could find one we would not be able to program it because it requires a programmer built specifically for this purpose. These PROMs are programmable only once and cannot be reprogrammed. They use tungsten fuses to store information and require a programming current of 150mA.

A modern solution is the use of PROM, EPROM, EPROM-OTP, EEPROM, FLASH memories

For me the best solution is to use an EEPROM or FLASH memory because they allow the information to be rewritten many times which leads to the possibility of improving the final product over time.

In the current implementation scheme of revision B in the Control Block, 10 chips were used

The schematic uses 8k EPROMs, but any type of ROM of any capacity can be used with minor modifications.

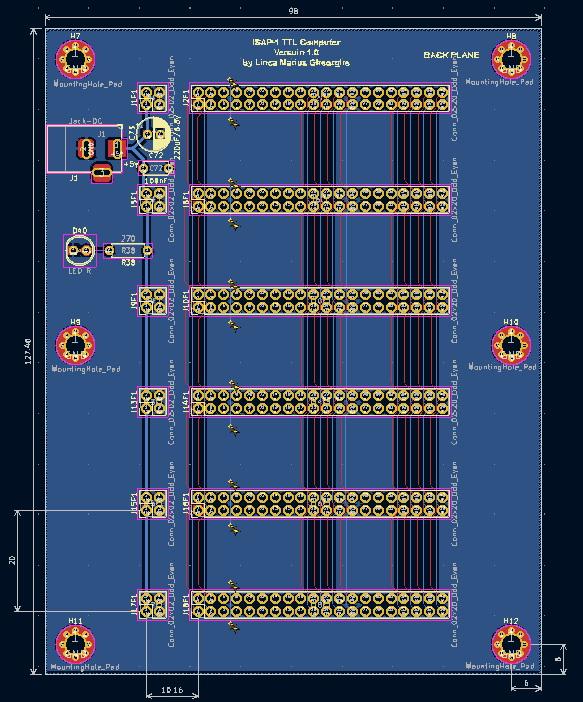
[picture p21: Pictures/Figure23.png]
Figure 23


This is what the completed PCB looks like for ISAP-1 Model B Version 1.0

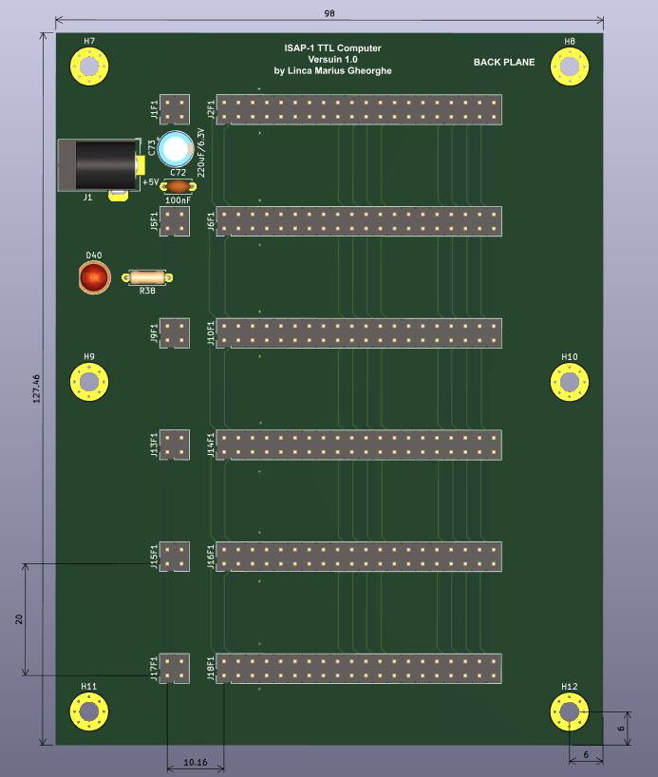
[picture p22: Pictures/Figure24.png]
Figure 24


An overview of the PCB is shown in the following figure

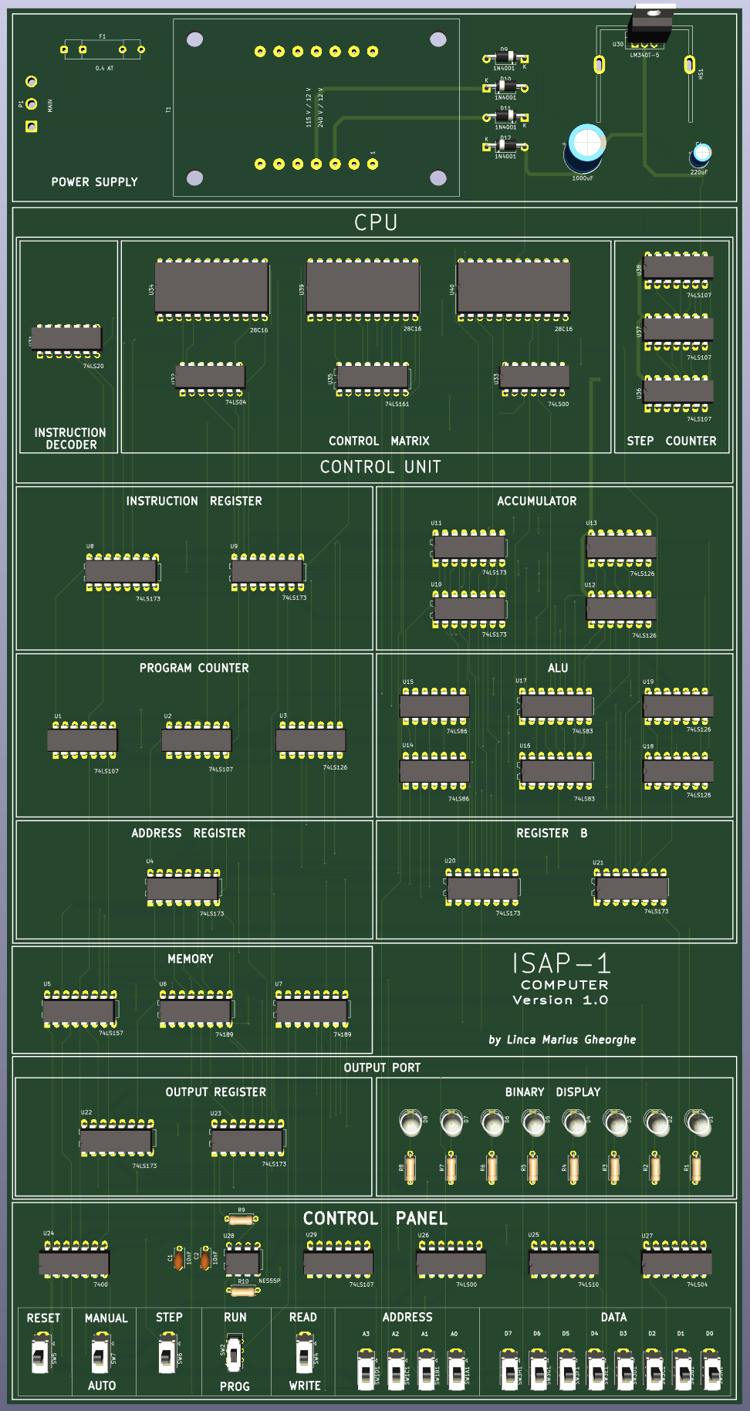
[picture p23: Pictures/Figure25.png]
Figure 25


The ISAP-1 Computer Model B version 1.0 project made in KiCAD is here: \
https://github.com/LincaMarius/ISAP-1_Schematic/blob/main/KiCAD/ISAP-1_modelB_ver1_0.zip

A total of 40 chips were used to build the ISAP-1 Model B Version 1.0 computer. Compared to the ISAP-1 Model A Version 1.0 where 49 were used, we have a reduction in the number of chips by 9 pieces while maintaining the same functionality of the computer.

## ISAP-1 Model B Version 1.1
Revision B of the ISAP-1 computer presents the modification of the Control Block as described by the authors, whereby the hard-wired logic is replaced with programmed logic.

In Version 1.1, an improvement is made to the ISAP-1 computer by implementing the Variable Machine Cycle.

The Instruction Set remains unchanged but the Control Block implementation changes.

In the book on page 163 the authors present a method of improving the SAP-1 Computer by implementing the Variable Machine Cycle.

The schematic is shown in Figure 10-17 and consists of 5 inverters and a 12-input NAND gate that generates the #NOP signal when the Control Block output has the NOP instruction encoded in Hexadecimal as 3E3h and a two-input AND gate that resets the Ring Counter when the #NOP or #CLR signal is low. 

The starting point is the Control Block diagram of version 1.0 shown in figure 23.

The scheme presented in the book that needs to be implemented is for a control matrix made with ROM memory with a capacity of 16 x 12 bits. So we only have 12 outputs that are used for control.

The signals CP, PE, EA, SI and EU must be inverted.

All of these signals act as inputs to a 12-input NAND gate.

For implementation, a 12-input NAND gate of the 74S134 type, a 13-input NAND gate of the 74ALS133 type can be used.

I implemented the new version using available logic gates that were not used by the authors of the book, so I added two chips. I used an unused 74LS00 NAND gate and an inverter to make the AND gate in the Ring Counter Reset circuit.

I used the 74LS133 chip which is a 13-input NAND gate.

In the current implementation scheme of revision B in the Control Block, 12 chips were used

The Control Block schematic of the ISAP-1 Model B Version 1.1 Computer is shown in the following figure:

Figure 26

This is what the completed PCB looks like for ISAP-1 Model B Version 1.1

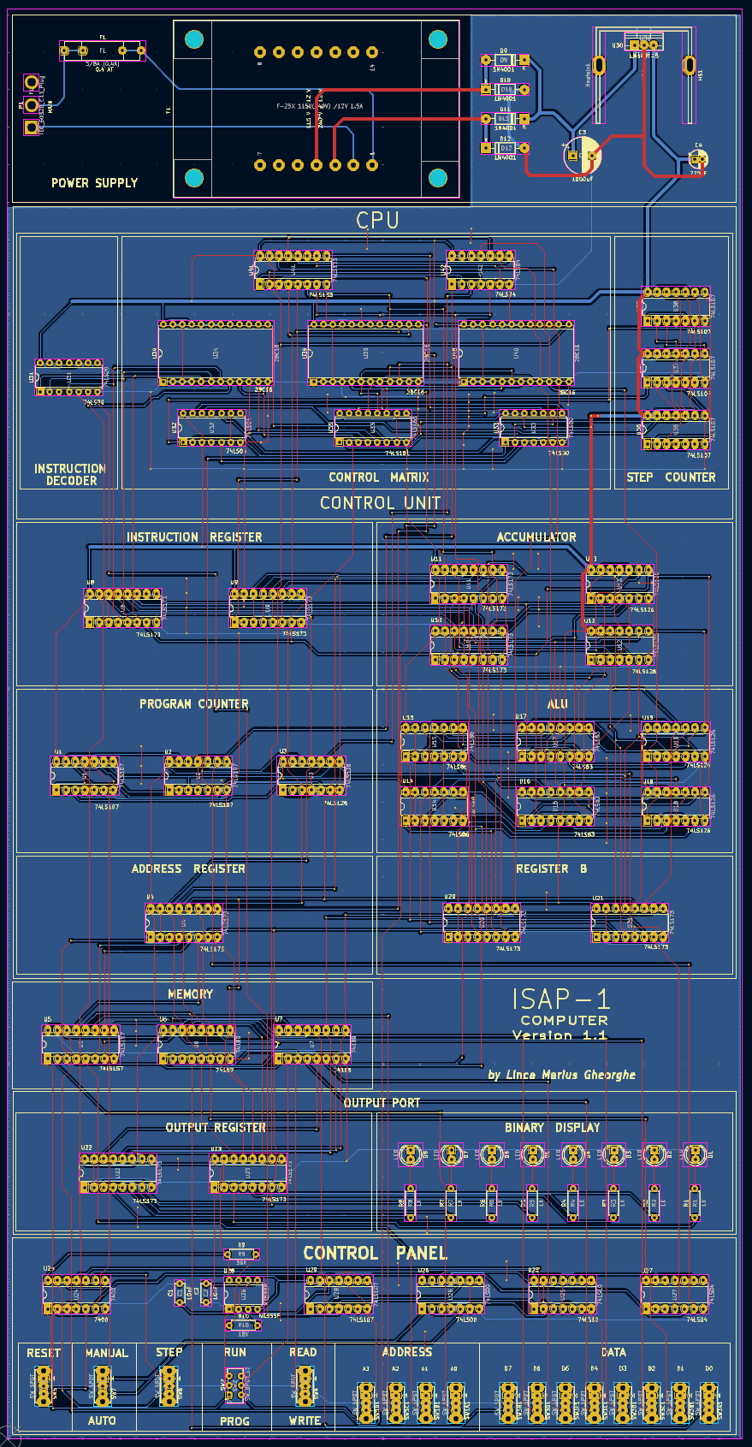
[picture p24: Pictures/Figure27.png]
Figure 27


An overview of the PCB is shown in the following figure

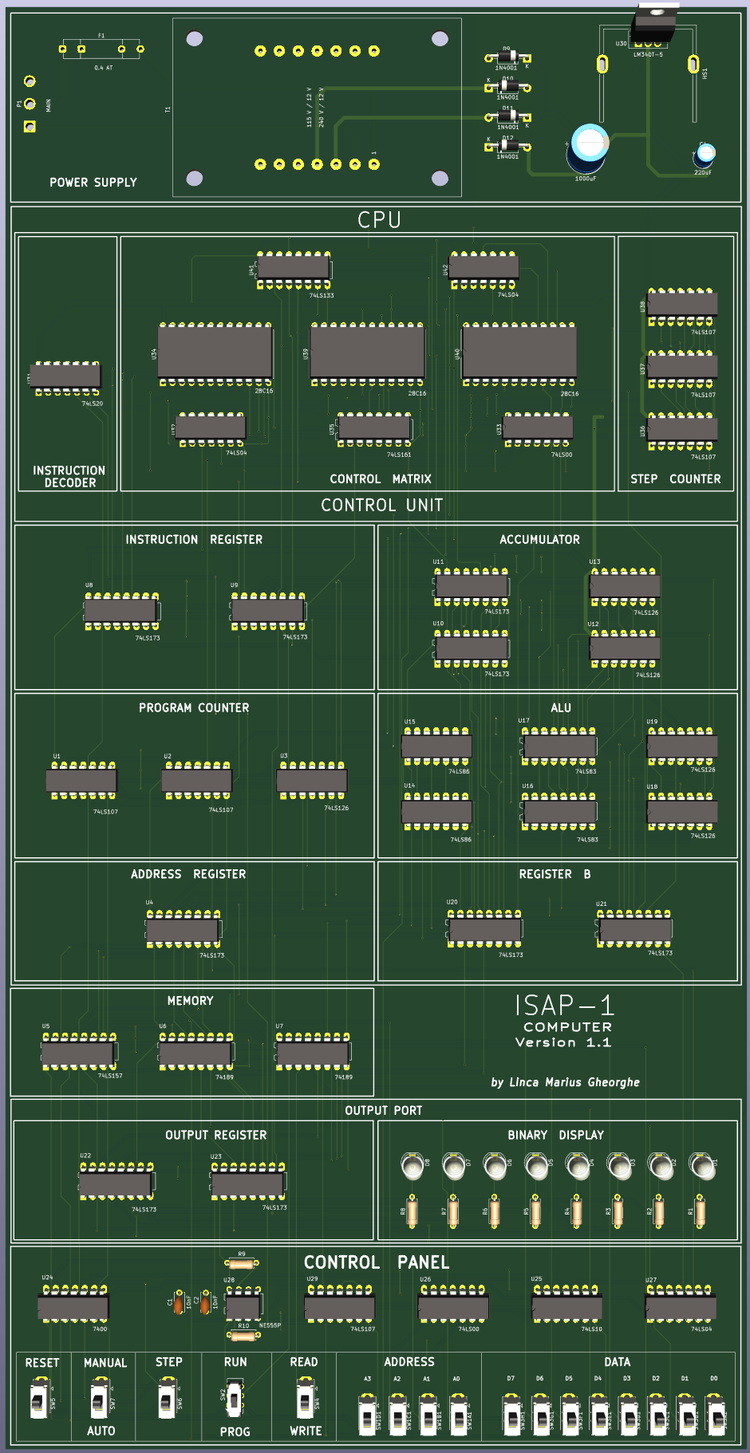
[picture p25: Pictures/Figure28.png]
Figure 28


The ISAP-1 Model B Version 1.1 computer project made in KiCAD is here: \
https://github.com/LincaMarius/ISAP-1_Schematic/blob/main/KiCAD/ISAP-1_modelB_ver1_1.zip

A total of 42 chips were used to build the ISAP-1 Model B Version 1.1 computer. Compared to the ISAP-1 Model A Version 1.0 where 49 were used, we have a reduction in the number of chips by 7 pieces while maintaining the same functionality of the computer.

## ISAP-1 Model B Version 1.2
In this version I will modify the ISAP-1 Computer by changing it from a Single Board Computer to a modular version.

The functionality of the Computer does not change and the Instruction Set does not change.

Since the SAP-1 Computer does not have decoupling capacitors provided in the original schematic, I will make improvements to the electronic schematic by adding decoupling capacitors for each chip used.

Since the SAP-1 Computer was originally designed in 1975, the power supply uses a mains transformer and a Linear Voltage Regulator. This technology is specific to that time period.

Nowadays, building such a power supply is more expensive compared to modern switching power supplies that are easily available. The purchase price of just the mains transformer is comparable to the purchase price of a modern 5 Volt power supply.

Therefore, I will remove the original power supply from the Project and the Computer will be powered using an external 5 Volt source. This will reduce the overall size and weight of the Computer.

### Program Counter
The schematic and functionality are unchanged from the original. I added decoupling capacitors with a value of 100 nF for each chip used.

For example, for 74LS107 the High to Low switching time is normally 15 ns. This time is desired as small as possible to have a high working speed of the Computer. So if we consider the transition as half a period of a signal we obtain a maximum period of 30 ns. This corresponds to a frequency of 33 MHz. At these frequencies the wires on the PCB behave as inductances and will increase the switching time. To eliminate this phenomenon we put decoupling capacitors as close as possible to the power pins of the chip.

The new schematic for the Program Counter Block is:

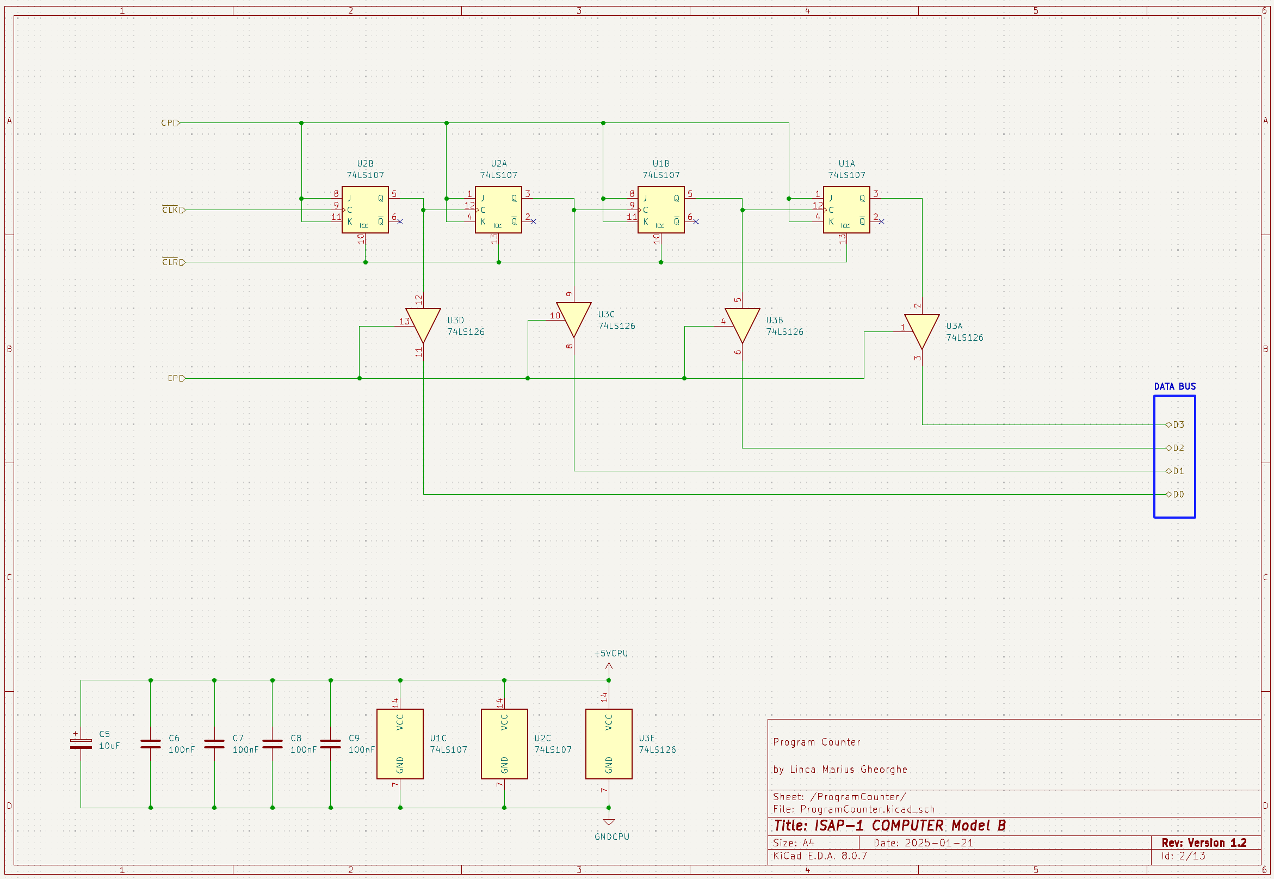
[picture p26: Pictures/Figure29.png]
Figure 29


### Address Register
The schematic and functionality are unchanged from the original. I added a decoupling capacitor with a value of 100 nF for the chip used.

The new Address Register schematic is:

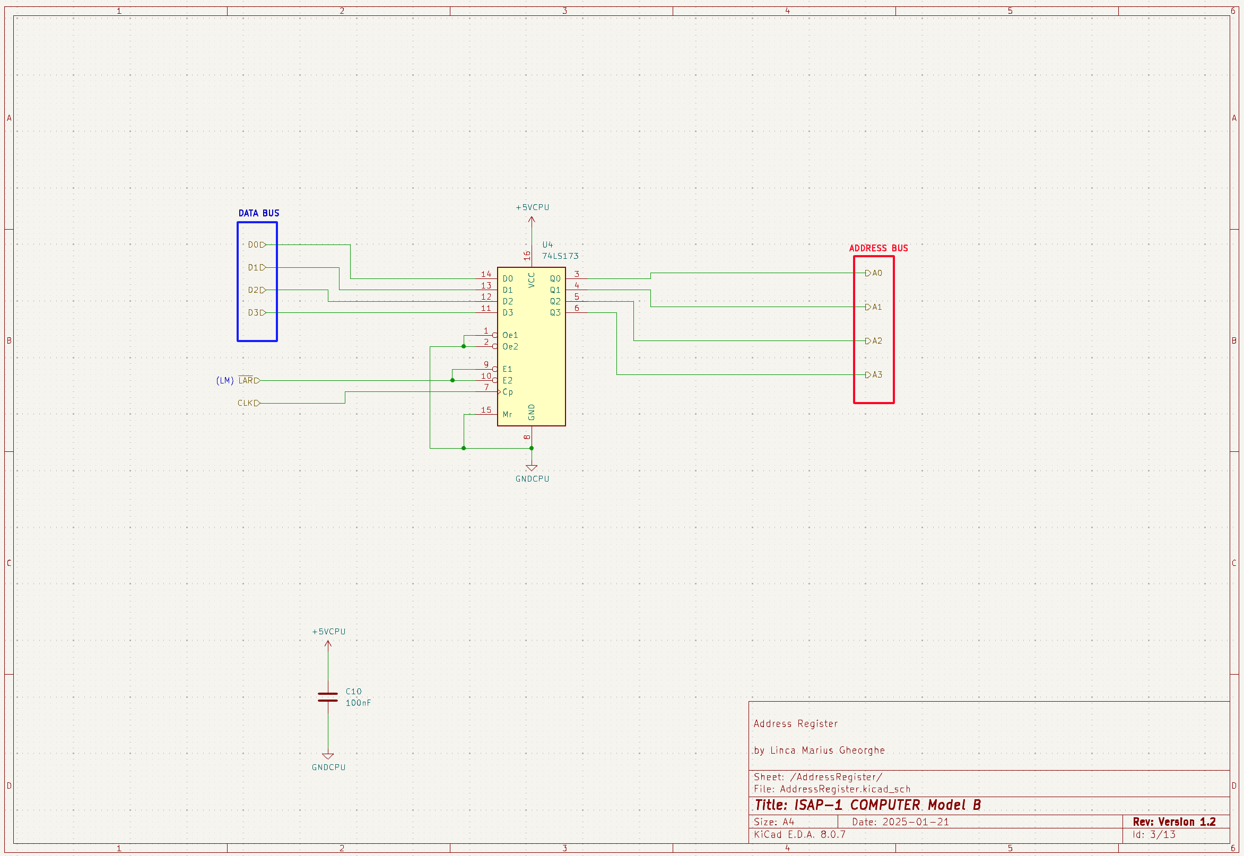
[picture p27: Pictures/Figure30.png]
Figure 30


### Instruction Register
The schematic and functionality are unchanged from the original. I added decoupling capacitors with a value of 100 nF for each chip used.

I also added a 10 uF filter capacitor to filter out low frequency noise that may appear on the power supply circuit.

The new schematic for the Instruction Register is:

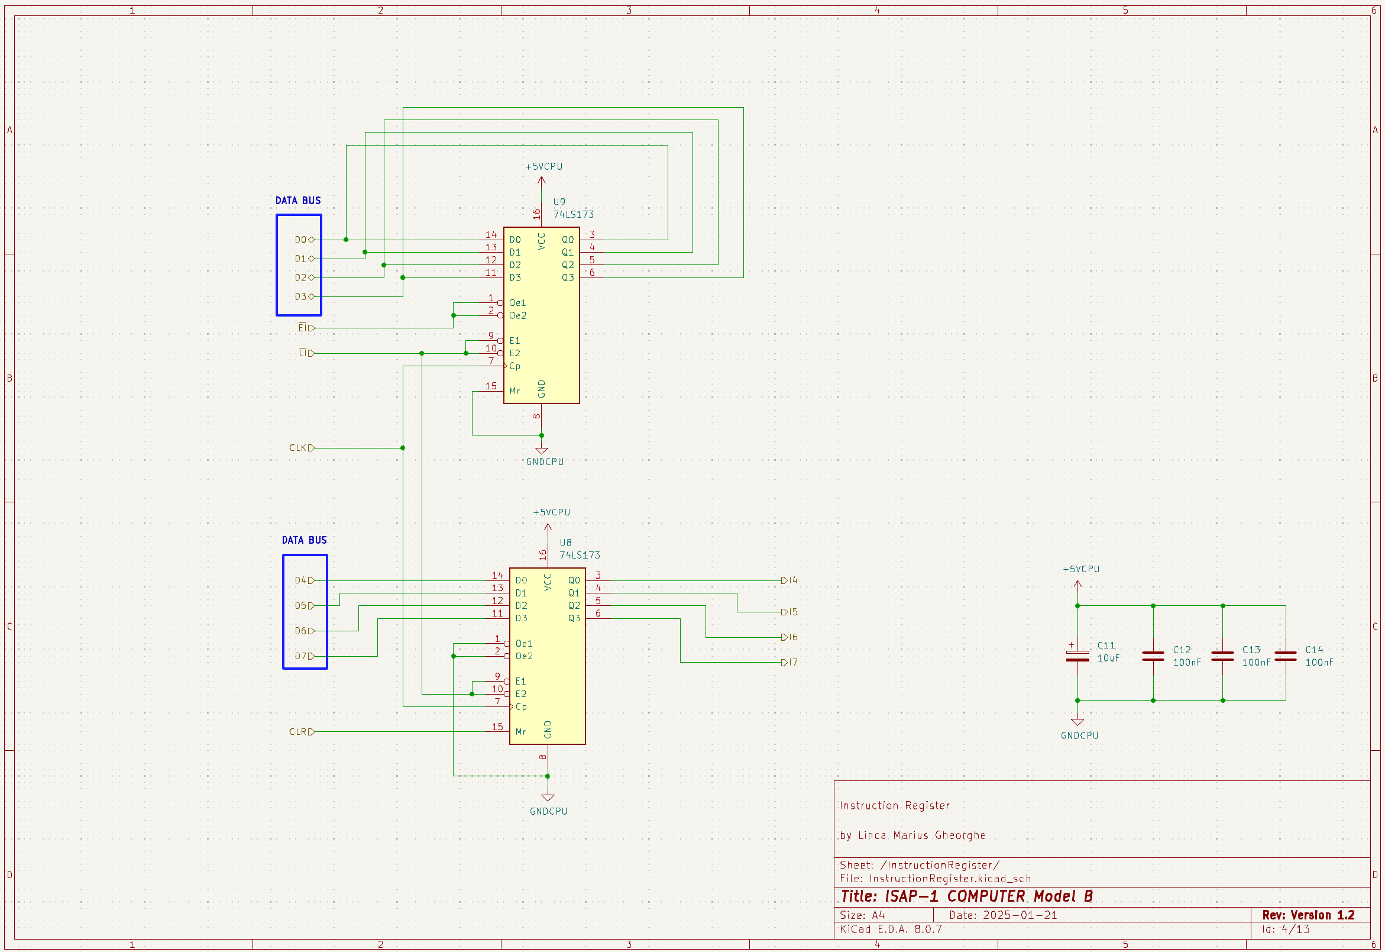
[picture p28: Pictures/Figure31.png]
Figure 31


### Accumulator Register
The schematic and functionality are unchanged from the original. I added decoupling capacitors with a value of 100 nF for each chip used.

I also added a 10 uF filter capacitor to filter out low frequency noise that may appear on the power supply circuit.

The new schematic for the Accumulator Register is:

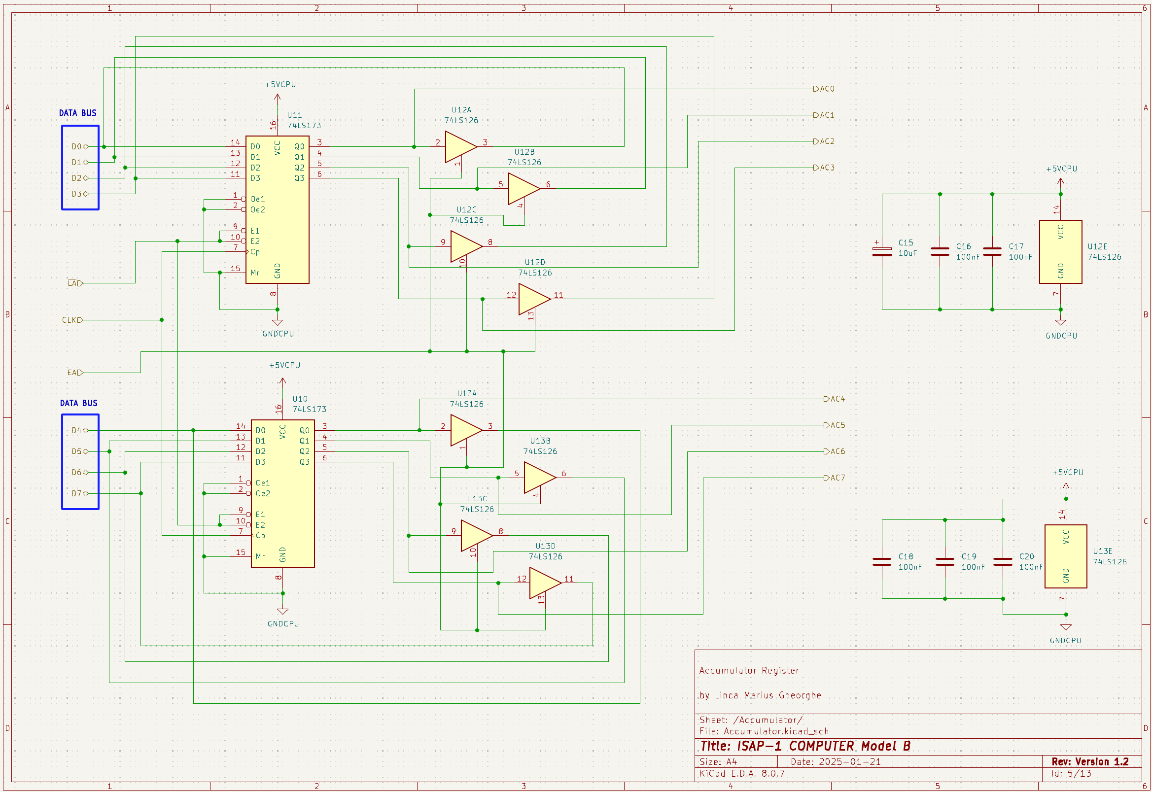
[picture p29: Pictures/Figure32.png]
Figure 32


### Arithmetic Unit
The schematic and functionality are unchanged from the original. I added decoupling capacitors with a value of 100 nF for each chip used.

I also added a 100 uF filter capacitor to filter out low frequency noise that may appear on the power supply circuit.

The new schematic for the Arithmetic Unit is:

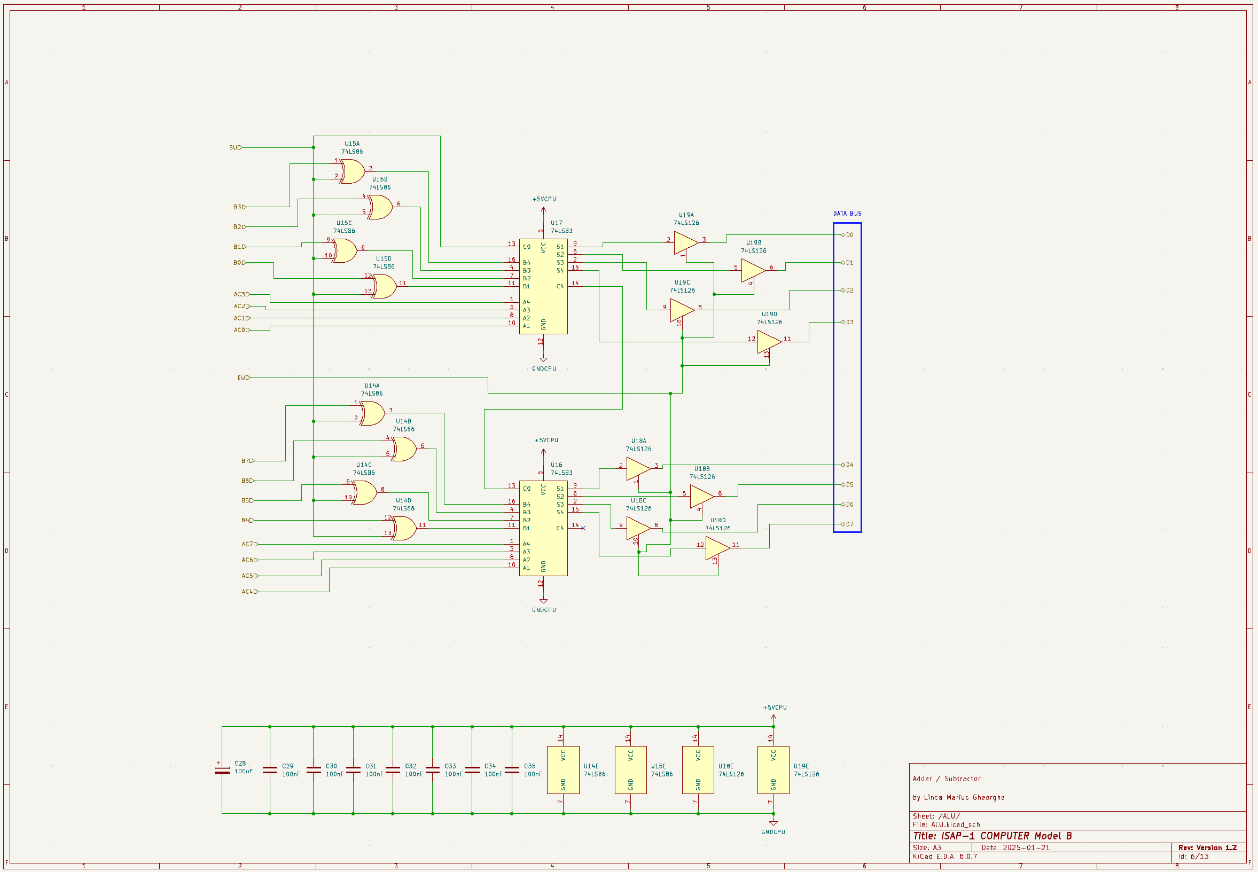
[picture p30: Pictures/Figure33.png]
Figure 33


### Register B
The schematic and functionality are unchanged from the original. I added decoupling capacitors with a value of 100 nF for each chip used.

I also added a 10 uF filter capacitor to filter out low frequency noise that may appear on the power supply circuit.

The new schematic for Register B is:

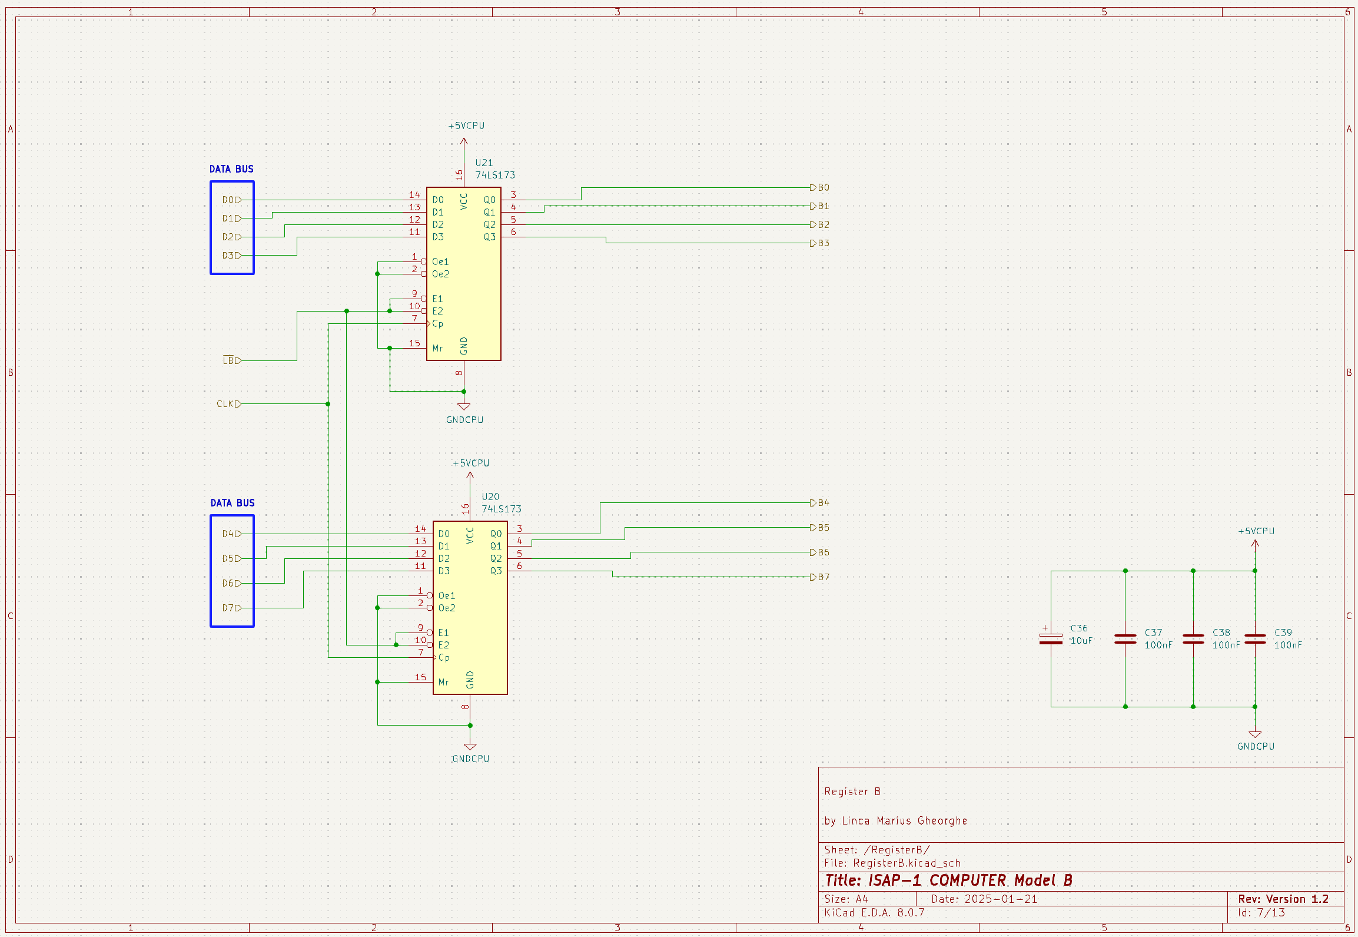
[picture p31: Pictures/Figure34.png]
Figure 34


All these Modules are part of the Central Processing Unit of the ISAP-1 Model B Version 1.2 Computer

This is what the completed PCB looks like for the Central Processing Unit of ISAP-1 Computer Model B Version 1.2

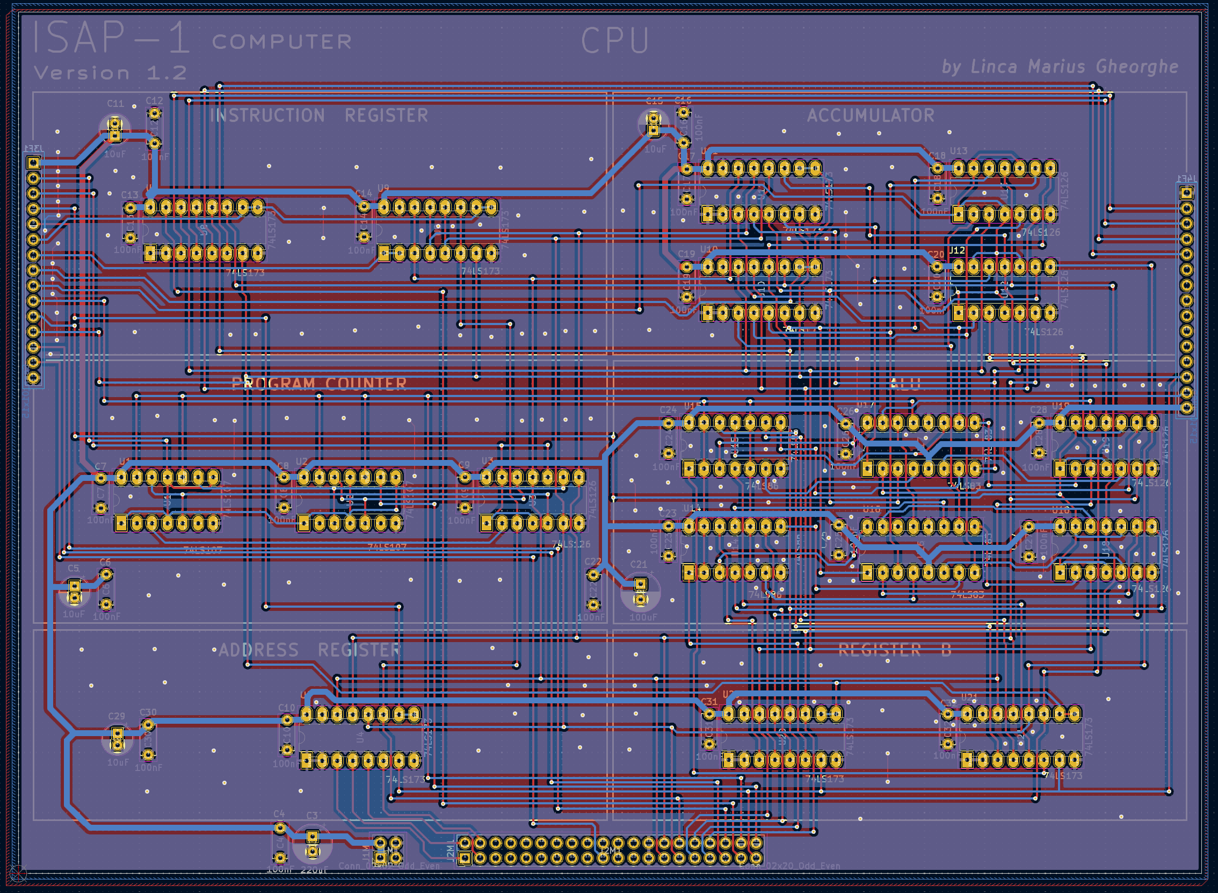
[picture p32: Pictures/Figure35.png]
Figure 35


An overview of the completed PCB for the ISAP-1 Model B Version 1.2 Central Processing Unit is as follows

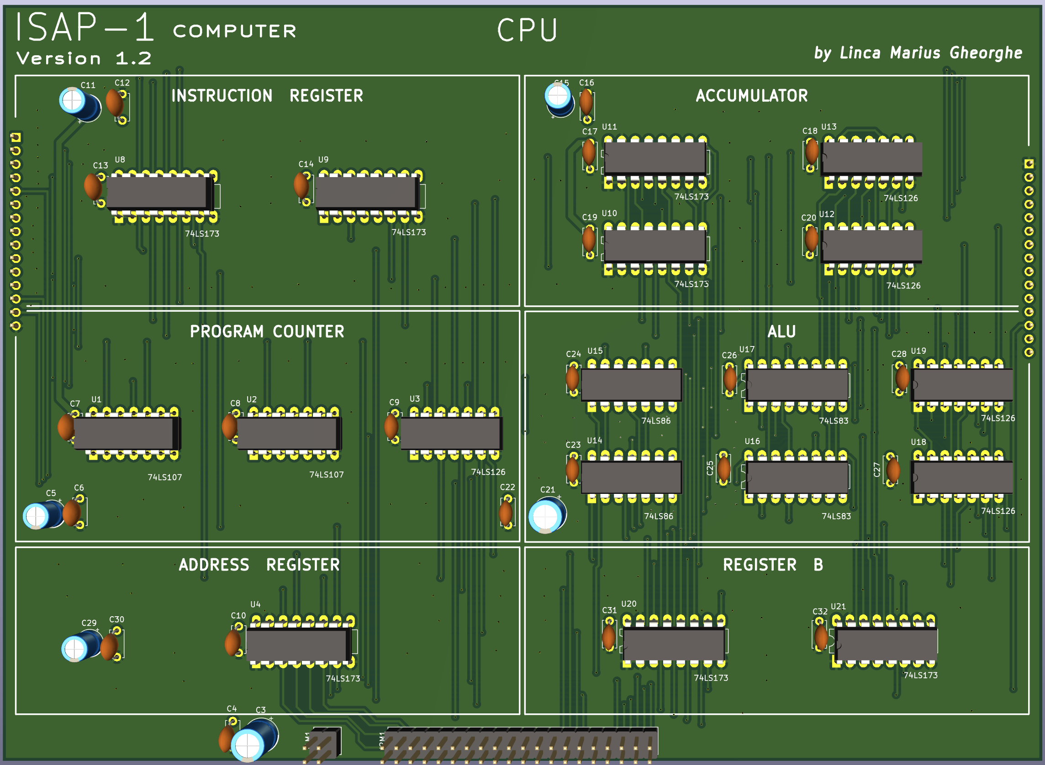
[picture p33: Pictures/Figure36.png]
Figure 36


At the bottom of the PCB we have the 4-pin J1 connector for 5V power supply and the 40-pin J2 connector for connection to the Bus.

To reduce the size of the CPU module I decided to make the Control Block as an independent Module that will attach to the CPU Module like an extension.

The connection between the CPU Module and the Control Unit Module is made through two 15-pin connectors each marked J3 and J4.

By physically separating the Control Unit into an independent Module, it has the major advantage that for modifying the Instruction Set, most changes are made at the Control Block level while the rest of the modules remain unchanged.

### Control Unit
The Control Unit's role is to direct the flow of data between the various Component Blocks of the Computer to ensure its operation and achieve the expected results.

It consists of three elements: the Instruction Decoder, the Ring Counter, and the Control Matrix.

The ISAP-1 Model B computer has a Control Matrix made with ROM memories.

For the current version of the ISAP-1 Computer to be modular, the CPU portion must be made on a single PCB. Since the CPU consists of many chips, I decided to divide its construction into two separate PCBs that will sit back to back.

We will have one PCB that contains all the building blocks of the CPU part and the second PCB contains only the Control Block.

Therefore, the Control Block will be treated as an independent module within the ISAP-1 Computer.

For connection to the CPU base module, we have provided two 10-pin connectors each, marked in the diagram as J3 and J4.
These will be mounted on the back of the PCB.

The functionality does not change from the original. I added decoupling capacitors with a value of 100 nF for each chip used.

I also added a 220 uF filter capacitor to filter out low frequency noise that may appear on the power supply circuit.

The new schematic for the Control Unit is:

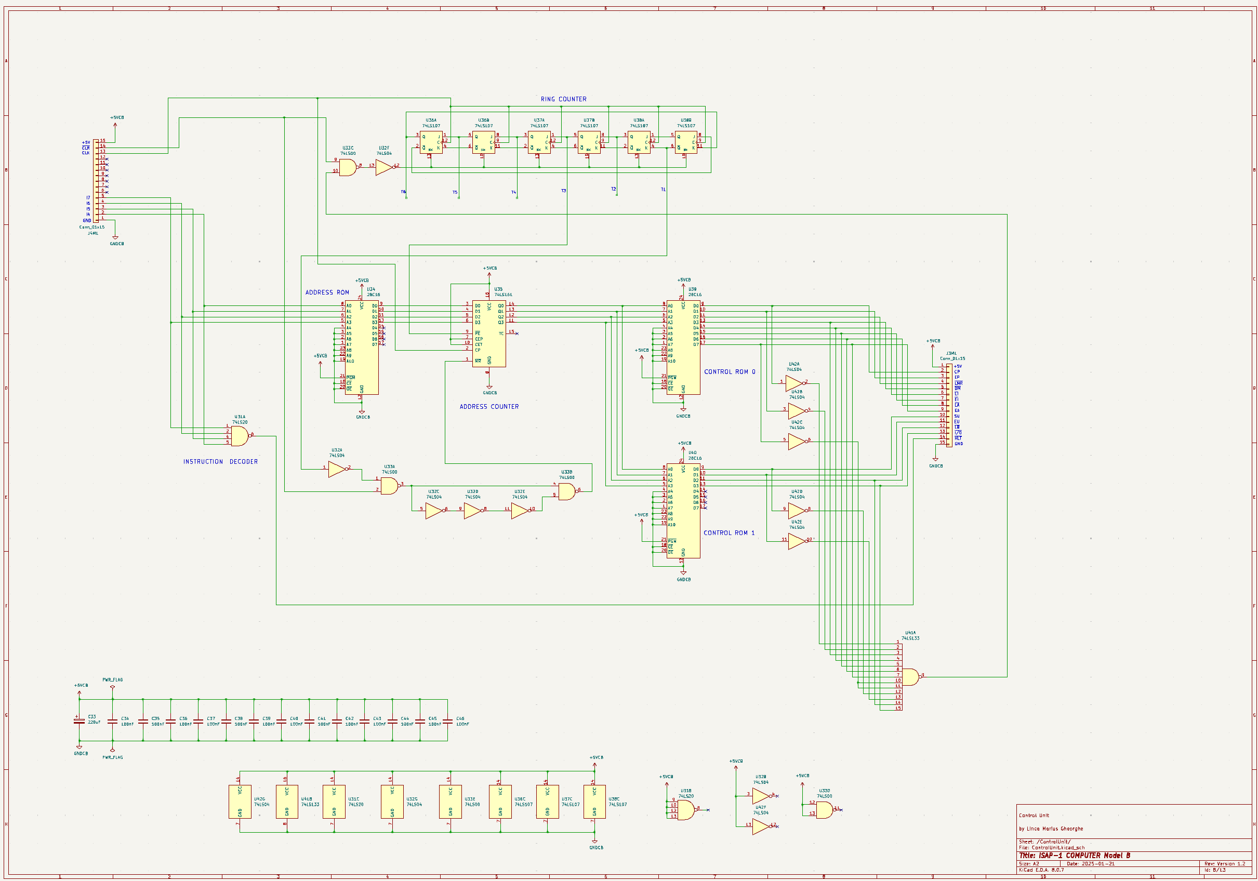
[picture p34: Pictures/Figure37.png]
Figure 37


This is the finished PCB layout for the Control Block Module of ISAP-1 Model B Computer Version 1.2

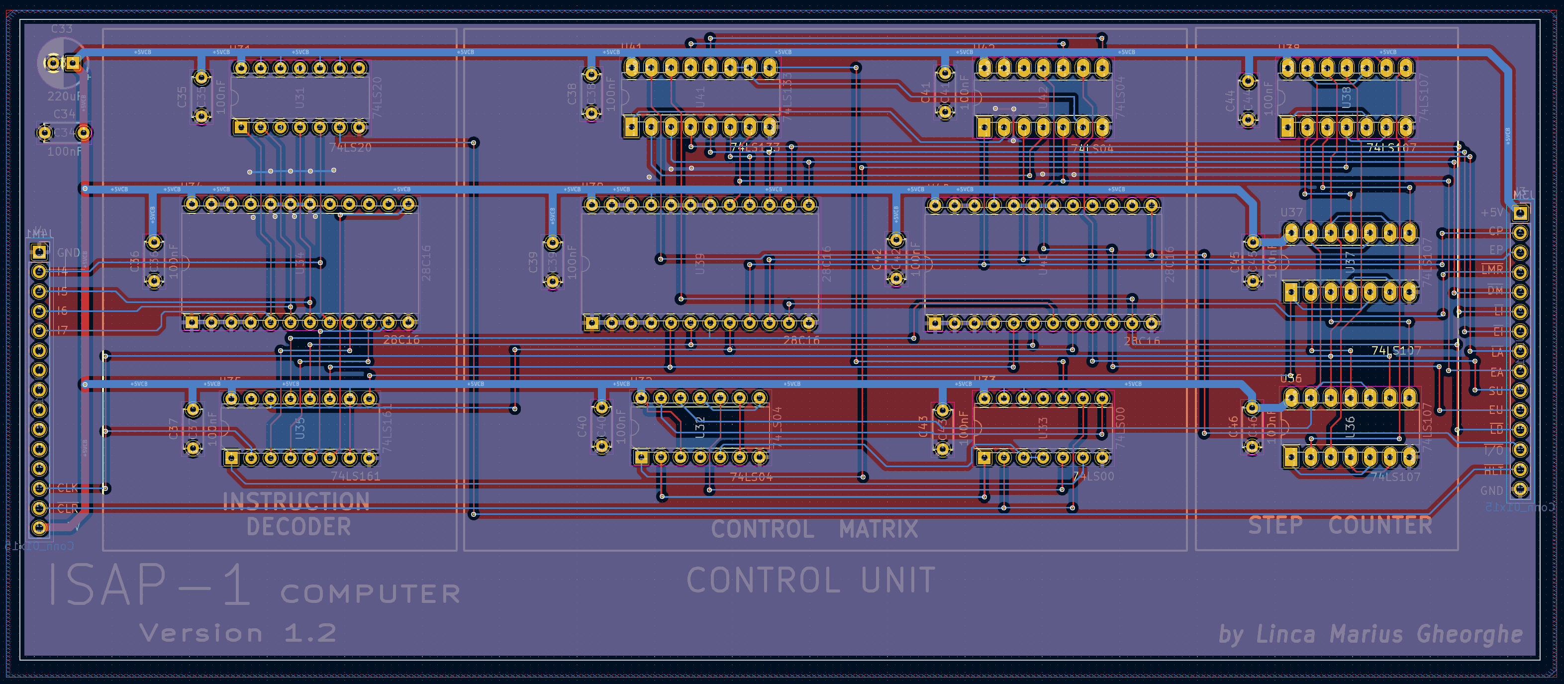
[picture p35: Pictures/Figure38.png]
Figure 38


An overview of the completed PCB for the ISAP-1 Model B Computer Control Block Module Version 1.2 is as follows

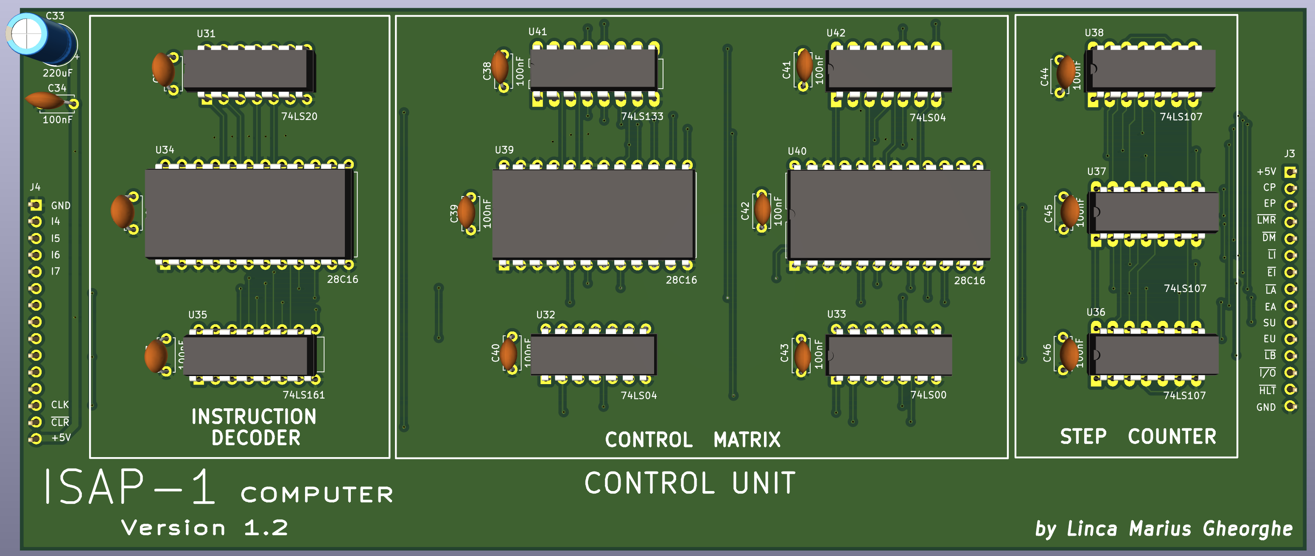
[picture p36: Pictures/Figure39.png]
Figure 39


To indicate the wrong mounting position of this module, I positioned the J3 connector on the PCB offset from the J4 connector.

If the module is mounted upside down due to the gap between the pins we will not have the alignment of the PCBs at the top. Normally the two PCBs should be at the same level at the top

### Memory Module
The modular version of the ISAP-1 Computer allows us to implement the Memory as an independent Module with its own PCB

Now all switches used for memory programming have been moved to the Front Panel Module

The functionality is unchanged from the original. I added a 100 nF decoupling capacitor for the chip used.

I also added a 10 uF filter capacitor to filter out low frequency noise that may appear on the power supply circuit.

This module communicates with the rest of the computer through the three System Buses. To connect the module to the buses, I added a connector marked J7 in the diagram.

To prevent the Module from being mounted in the wrong orientation, which would lead to its failure, we added a special power connector offset from the Bus connector by 14 mm.

The new schematic for the ISAP-1 Model B Computer Memory Module Version 1.2 is:

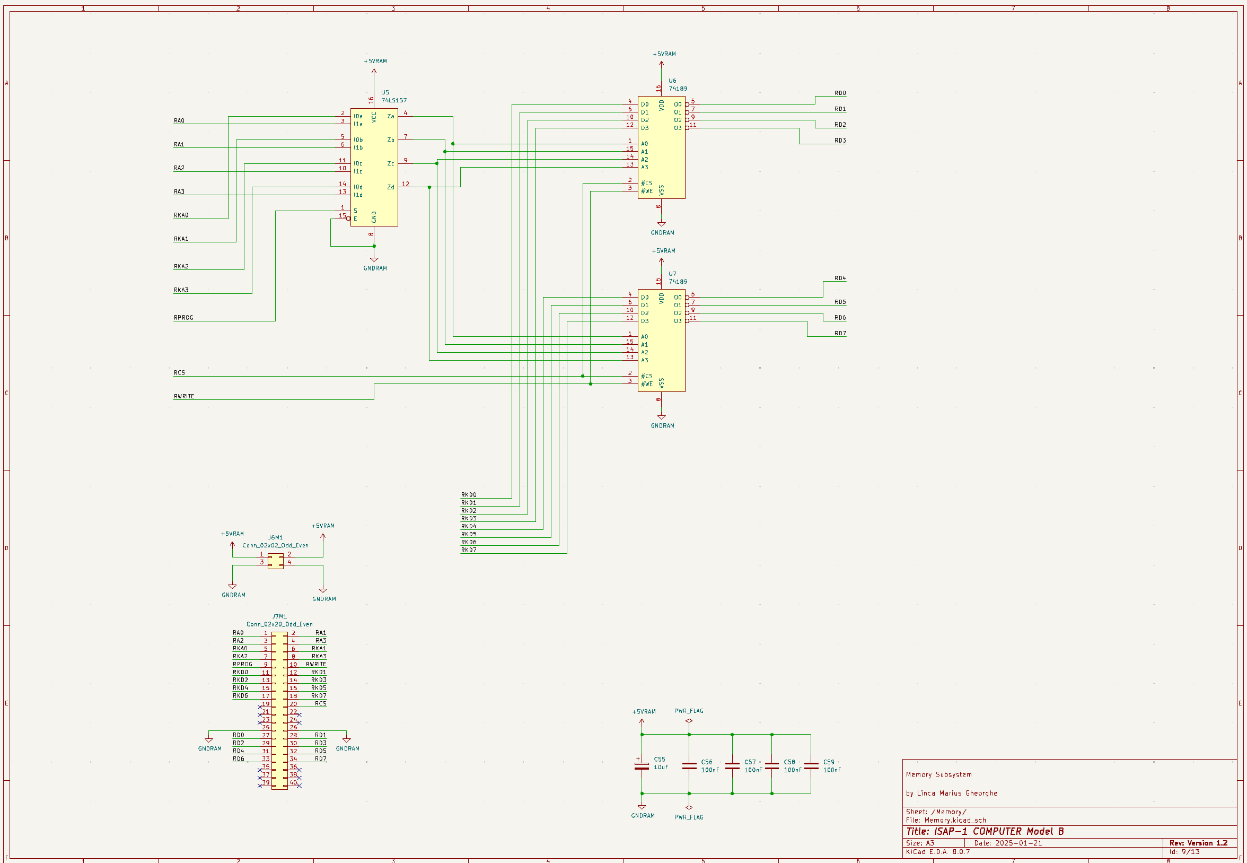
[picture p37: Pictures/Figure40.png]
Figure 40


This is the finished PCB layout for the Memory Module of ISAP-1 Model B Computer Version 1.2

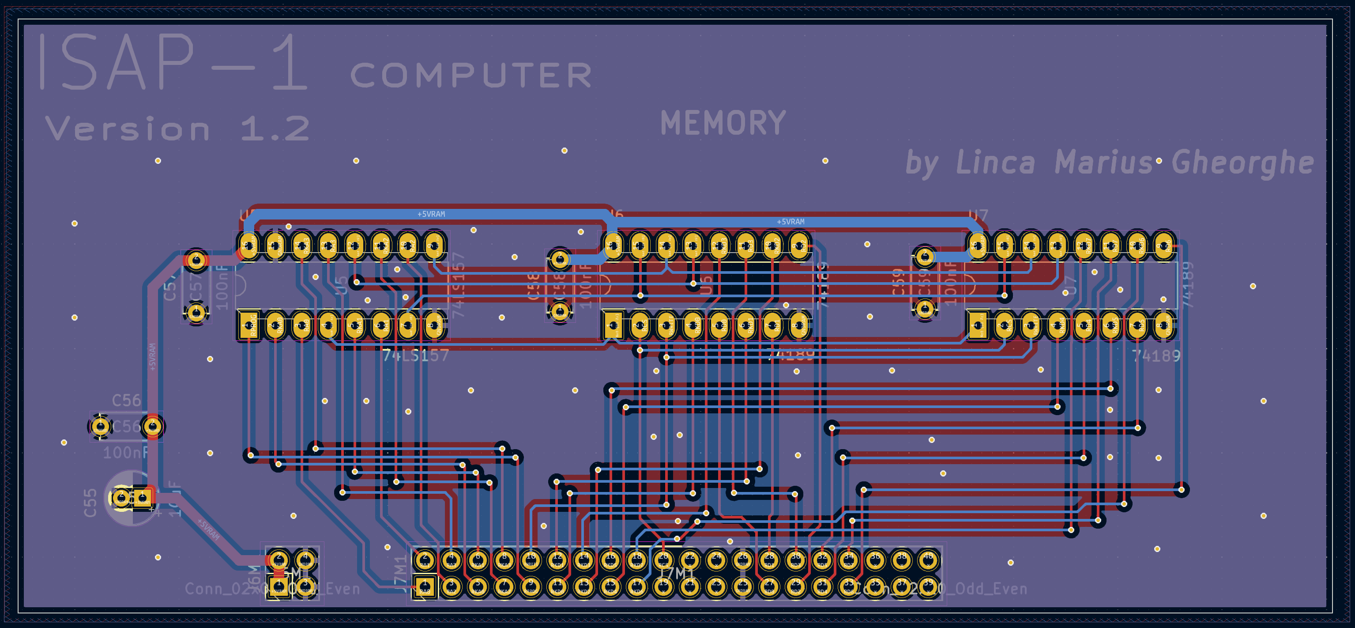
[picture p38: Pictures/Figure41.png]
Figure 41


An overview of the completed PCB for the ISAP-1 Model B Version 1.2 Computer Memory Module is as follows

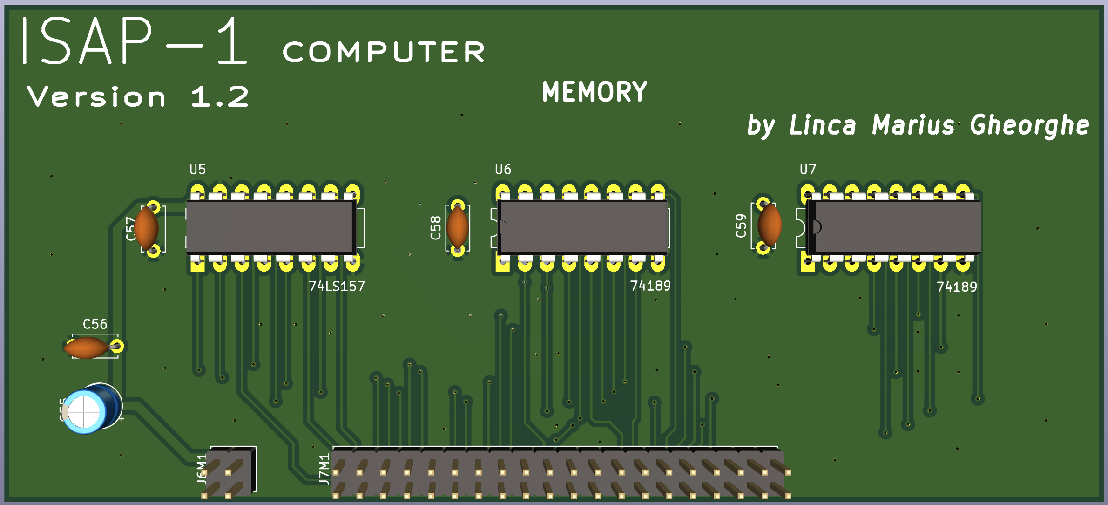
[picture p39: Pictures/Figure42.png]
Figure 42


### Output Register Module
The modular version of the ISAP-1 Computer allows us to implement the Output Register as an independent Module with its own PCB

The schematic and functionality are unchanged from the original. I added a 100 nF decoupling capacitor for the chip used.

I also added a 100 uF filter capacitor to filter out low frequency noise that may appear on the power supply circuit.

This module communicates with the rest of the computer through the three system buses. To connect the module to the buses, I added a connector marked J9 in the diagram.

To prevent the Module from being mounted in the wrong orientation, which would lead to its failure, I added a special power connector offset from the Bus connector by 14 mm, marked J8 in the diagram. The Module will stand vertically in the ISAP-1 Computer

The Binary Display is designed as a separate Module and connects to the Output Register Module via the 10-pin connector marked J10 in the schematic.

The new schematic for the Output Register Module for the ISAP-1 Model B Computer Version 1.2 is:

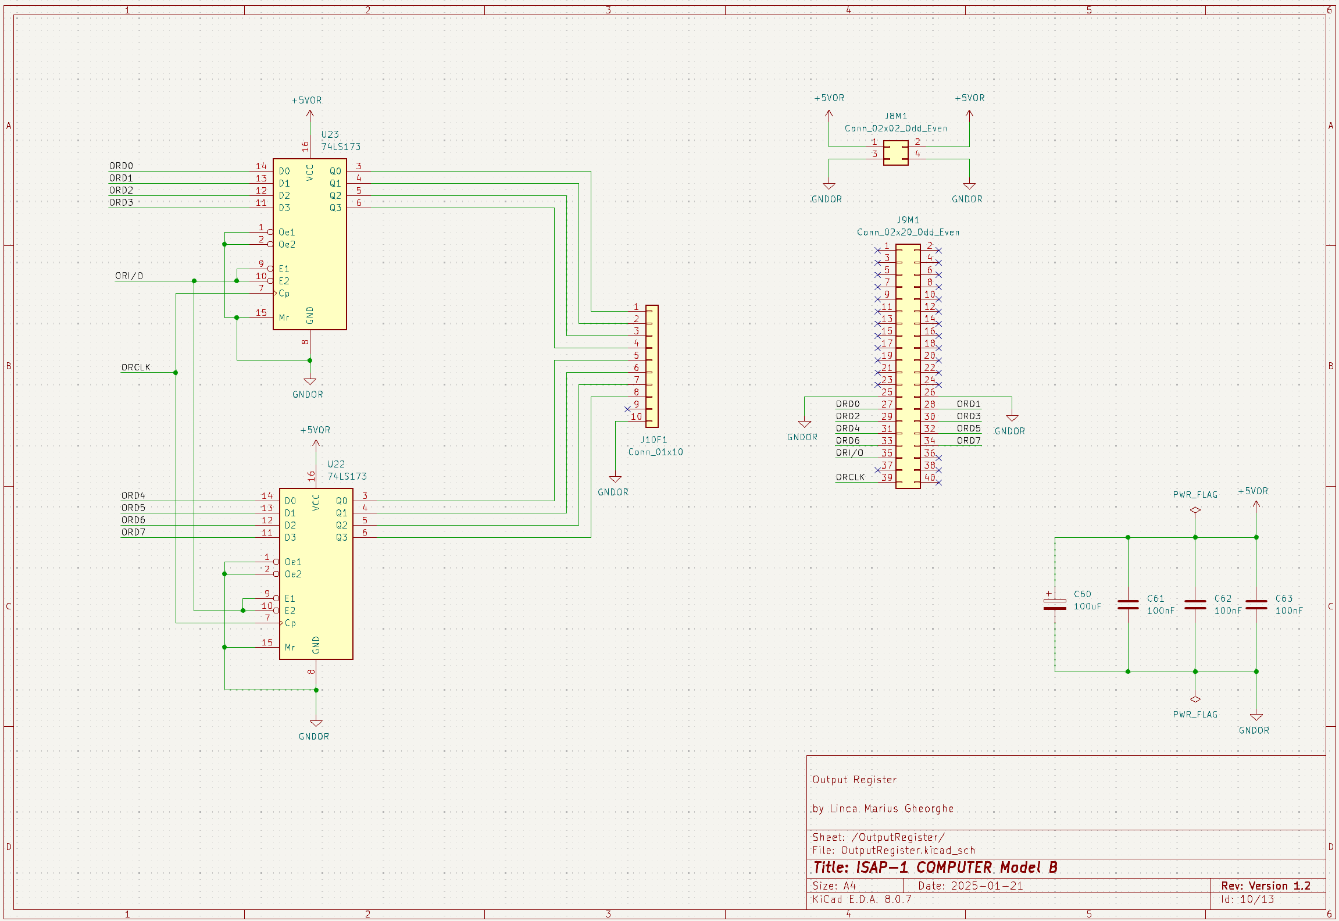
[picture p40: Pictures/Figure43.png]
Figure 43


This is the finished PCB layout for the Output Register Module of ISAP-1 Model B Computer Version 1.2

Figure 44

An overview of the completed PCB for the ISAP-1 Model B Version 1.2 Computer Output Register Module is as follows

Figure 45

### Binary Display Module
The modular version of the ISAP-1 Computer allows us to implement the Binary Display as an independent Module with its own PCB

The schematic and functionality are unchanged from the original. 

The Binary Display is designed as a separate Module and connects to the Output Register Module via the 10-pin connector marked J10 in the schematic.

The new schematic for the Binary Display Module for the ISAP-1 Model B Computer Version 1.2 is:

Figure 46

This is the finished PCB layout for the Binary Display Module of ISAP-1 Model B Computer Version 1.2

Figure 47

An overview of the completed PCB for the ISAP-1 Model B Version 1.2 Binary Computer Display Module is as follows

Figure 48

### Front Panel Module
The modular version of the ISAP-1 Computer allows us to implement the Front Panel as an independent Module with its own PCB

The schematic and functionality are unchanged from the original. I added a 100 nF decoupling capacitor for the chip used.

I also added a 22 uF filter capacitor to filter out low frequency noise that may appear on the power supply circuit.

This module communicates with the rest of the computer through the three system buses. To connect the module to the buses, I added a connector marked J12 in the diagram.

To prevent the Module from being mounted in the wrong orientation, which would lead to its failure, I added a special power connector offset from the Bus connector by 14 mm, marked J11 in the diagram. The Module will stand vertically in the ISAP-1 Computer

I designed this module to be positioned in position 1 on the BackPlane. This module will sit horizontally when attached to the BackPlane.

The new schematic for the Front Panel Module for the ISAP-1 Model B Computer Version 1.2 is:

Figure 49

This is the finished PCB layout for the Front Panel Module of ISAP-1 Model B Computer Version 1.2

Figure 50

An overview of the completed PCB for the ISAP-1 Model B Computer Front Panel Module Version 1.2 is as follows

Figure 51

### Backplane Module
The modular version of the ISAP-1 Computer allows us to implement the Backplane as an independent Module with its own PCB

This module is an addition to the original scheme and is intended to ensure the modularity of the Computer.

I also added a 100 uF filter capacitor to filter out low frequency noise that may appear on the power supply circuit.

The LED marked D9 signals the presence of supply voltage. The current limiting resistor is calculated as follows:

R11 = (Vcc – VF) / I_Led = (5V – 1.8V) / 15mA = 3.2V / 0.015A =  213 Ohms

The closest standard value is 220 Ohm. VF = 1.8V was used to drive a red LED.

The communication of all modules is done through the three buses (Address Bus, Data Bus and Command Bus) for which 7 40-pin connectors are provided, which are associated with 7 4-pin connectors for the 5 Volt power supply.

To prevent the Modules from being mounted in the wrong orientation, which would lead to their failure, I added this power connector offset from the Bus connector.

The new schematic for the Backplane Module for the ISAP-1 Model B Computer Version 1.2 is:

Figure 52

This is the finished PCB layout for the Backplane Module of ISAP-1 Model B Computer Version 1.2

Figure 53

An overview of the completed PCB for the ISAP-1 Model B Computer Backplane Module Version 1.2 is as follows

Figure 54

The ISAP-1 Model B Version 1.2 computer project made in KiCAD is here: \
https://github.com/LincaMarius/ISAP-1_Schematic/blob/main/KiCAD/ISAP-1_modelB_ver1_2.zip

A total of 41 chips were used to build the ISAP-1 Model B Version 1.2 Computer. Compared to the ISAP-1 Model A Version 1.1 where 42 were used, we have a reduction in the number of chips by 1 pieces while maintaining the same functionality of the computer.

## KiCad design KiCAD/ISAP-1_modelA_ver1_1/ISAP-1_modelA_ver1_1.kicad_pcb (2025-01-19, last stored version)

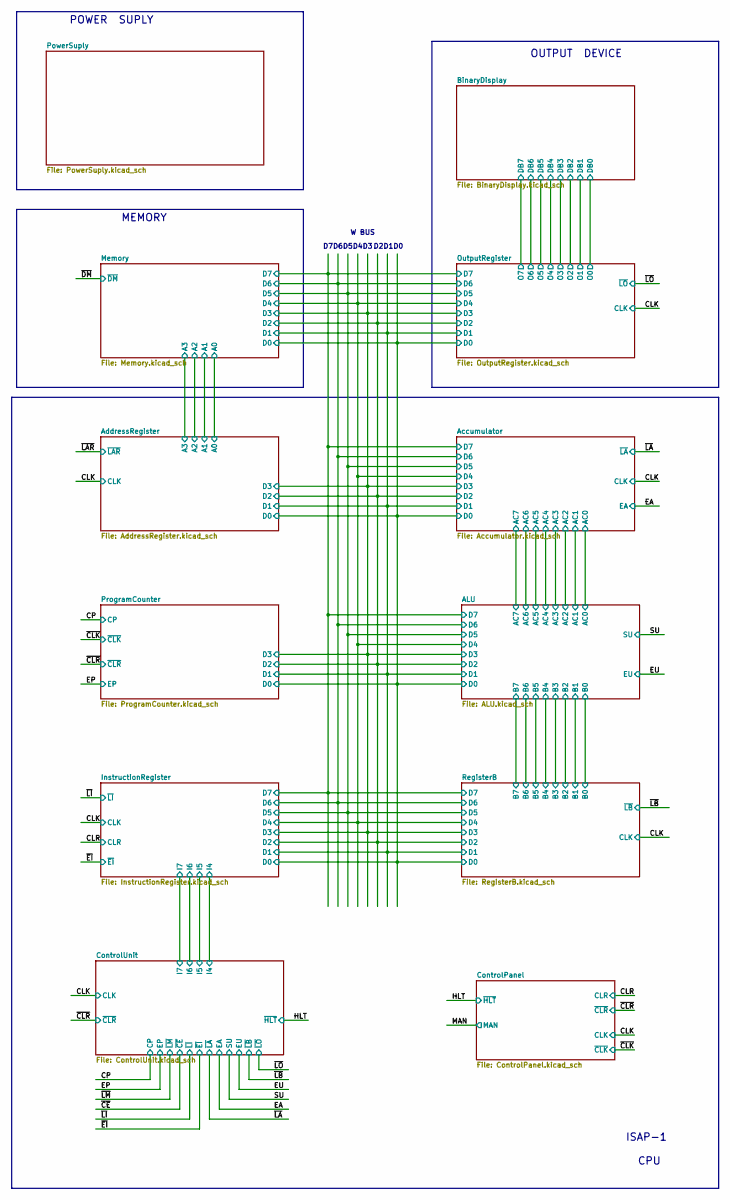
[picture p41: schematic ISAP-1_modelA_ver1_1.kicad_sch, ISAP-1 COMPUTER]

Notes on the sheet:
POWER SUPLY
ISAP-1 CPU
W BUS
MEMORY
OUTPUT DEVICE

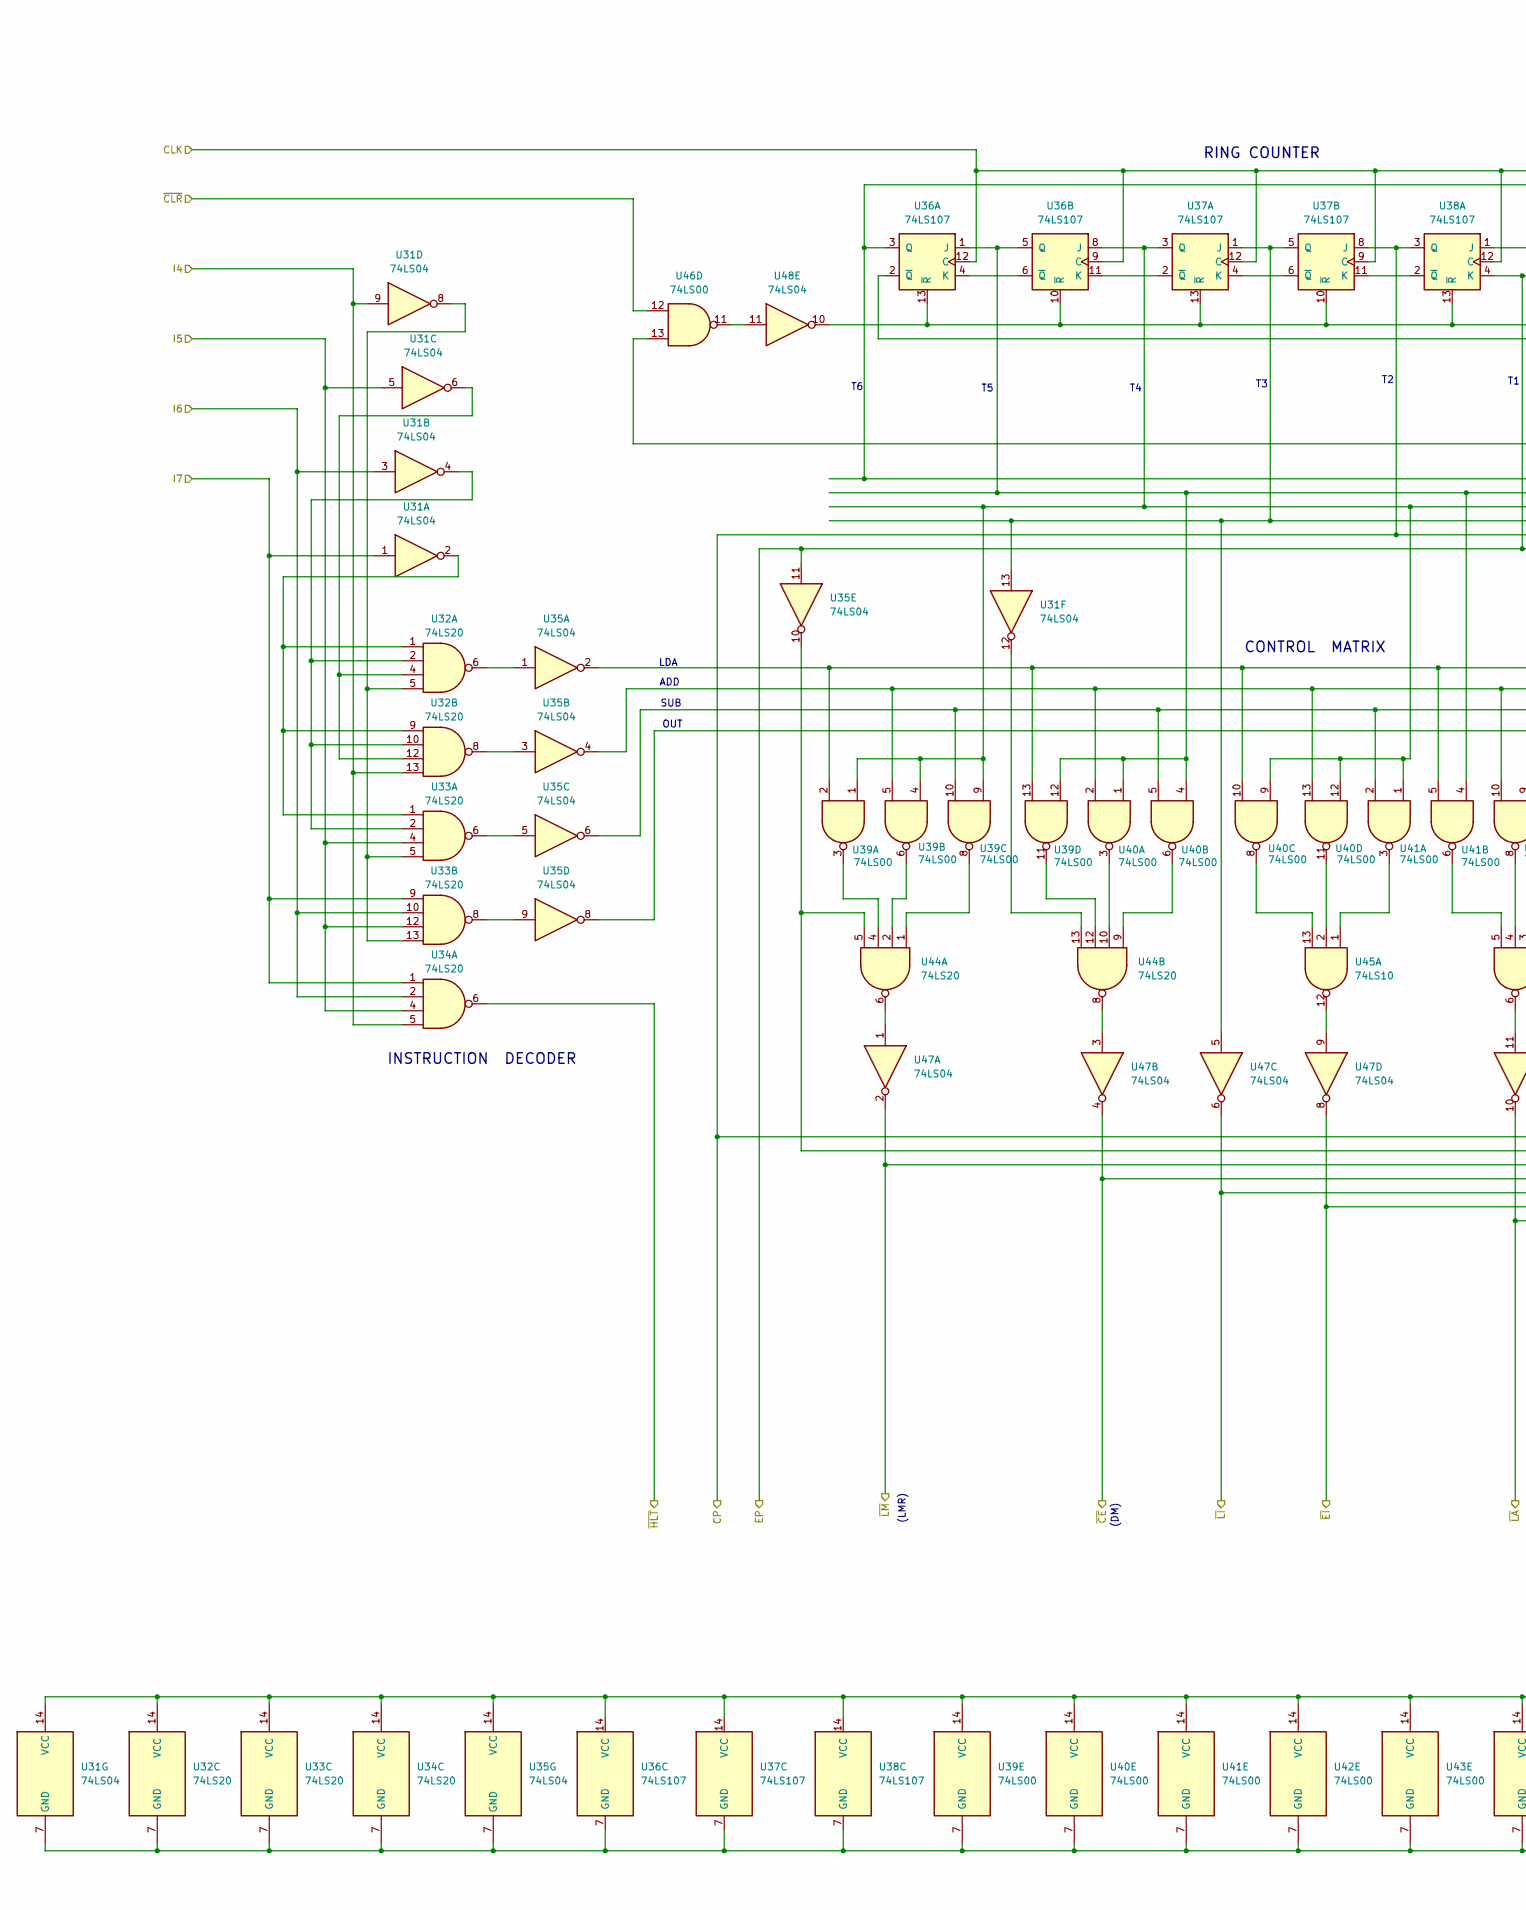
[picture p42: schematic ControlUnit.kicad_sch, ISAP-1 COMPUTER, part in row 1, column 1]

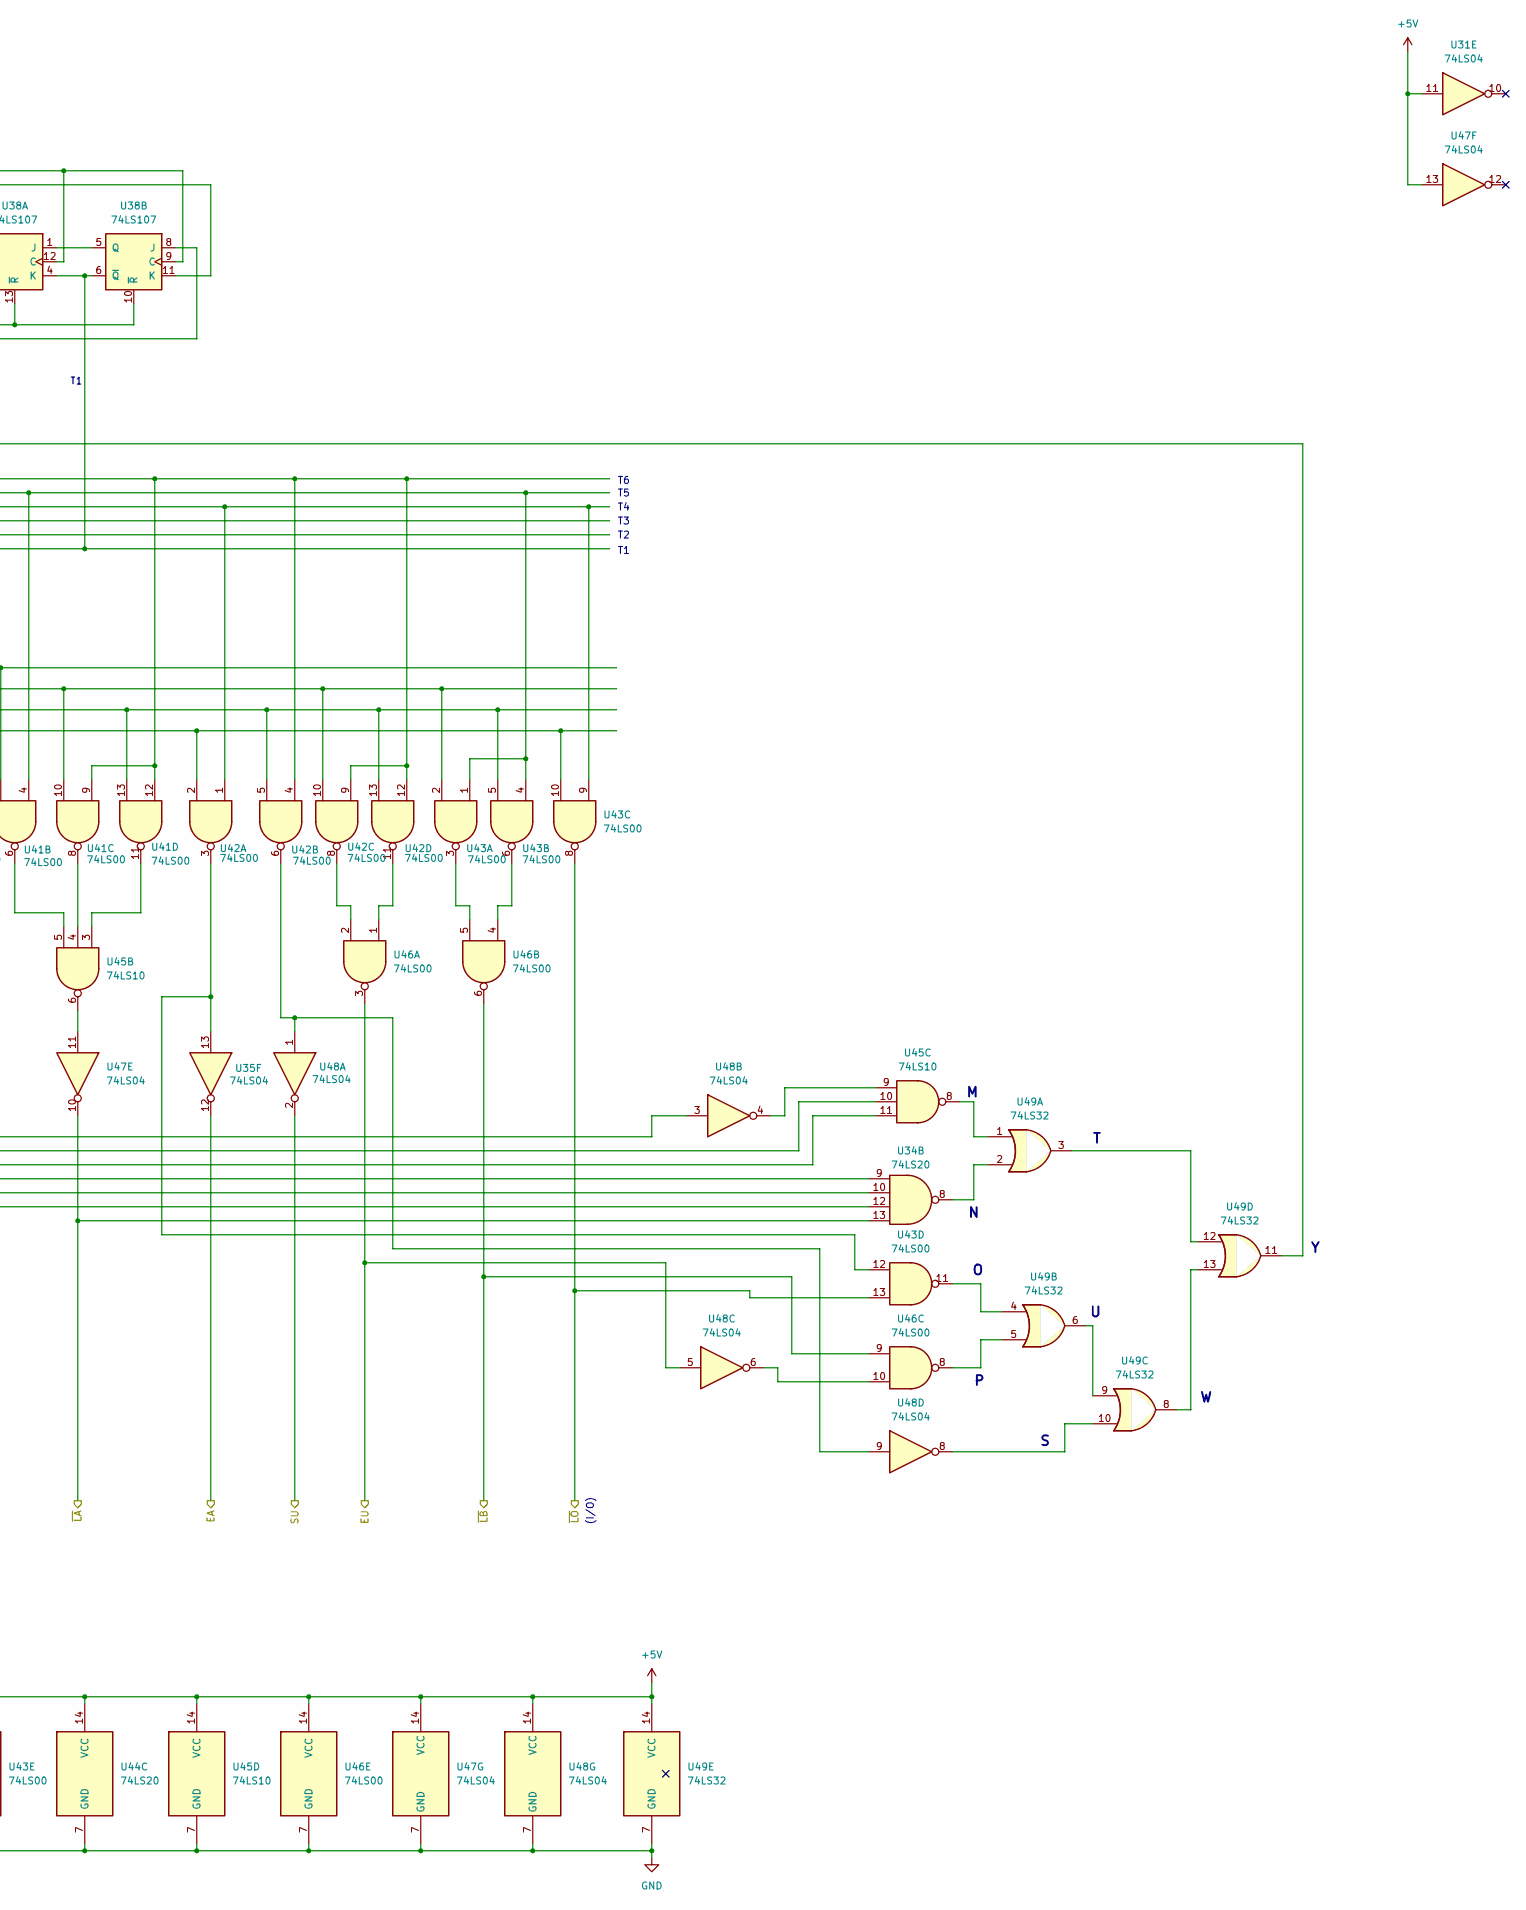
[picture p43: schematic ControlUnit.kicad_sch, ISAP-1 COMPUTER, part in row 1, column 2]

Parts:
U31, U35, U47, U48: 74LS04; DIP-14_W7.62mm_LongPads
U32, U33, U34, U44: 74LS20; DIP-14_W7.62mm_LongPads
U36, U37, U38: 74LS107; DIP-14_W7.62mm_LongPads
U39, U40, U41, U42, U43, U46: 74LS00; DIP-14_W7.62mm_LongPads
U45: 74LS10; DIP-14_W7.62mm_LongPads
U49: 74LS32; DIP-14_W7.62mm

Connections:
+5V: U31.11, U31.14 (VCC), U32.14 (VCC), U33.14 (VCC), U34.14 (VCC), U35.14 (VCC), U36.14 (VCC), U37.14 (VCC), U38.14 (VCC), U39.14 (VCC), U40.14 (VCC), U41.14 (VCC), U42.14 (VCC), U43.14 (VCC), U44.14 (VCC), U45.14 (VCC), U46.14 (VCC), U47.13, U47.14 (VCC), U48.14 (VCC), U49.14 (VCC); also elsewhere on the board
/CLK: U36.9 (C), U36.12 (C), U37.9 (C), U37.12 (C), U38.9 (C), U38.12 (C); also elsewhere on the board
/CP: U37.8 (J), U38.3 (Q), U48.3; also elsewhere on the board
/ControlUnit/I4: U31.9, U32.13, U34.5; also elsewhere on the board
/ControlUnit/I5: U31.5, U33.4, U33.12, U34.4; also elsewhere on the board
/ControlUnit/I6: U31.3, U33.10, U34.2; also elsewhere on the board
/ControlUnit/I7: U31.1, U33.9, U34.1; also elsewhere on the board
/EA: U35.12; also elsewhere on the board
/EP: U35.11, U38.4 (K), U38.6 (~Q); also elsewhere on the board
/EU: U46.3, U48.5; also elsewhere on the board
/HLT: U34.6; also elsewhere on the board
/SU: U48.2; also elsewhere on the board
/~CE: U34.9, U47.4
/~CLR: U46.12; also elsewhere on the board
/~EI: U34.12, U47.8; also elsewhere on the board
/~LA: U34.13, U47.10; also elsewhere on the board
/~LB: U46.6, U46.9; also elsewhere on the board
/~LI: U34.10, U47.6; also elsewhere on the board
/~LM: U45.11, U47.2
/~LO: U43.8, U43.13; also elsewhere on the board
GND: U31.7 (GND), U32.7 (GND), U33.7 (GND), U34.7 (GND), U35.7 (GND), U36.7 (GND), U37.7 (GND), U38.7 (GND), U39.7 (GND), U40.7 (GND), U41.7 (GND), U42.7 (GND), U43.7 (GND), U44.7 (GND), U45.7 (GND), U46.7 (GND), U47.7 (GND), U48.7 (GND), U49.7 (GND); also elsewhere on the board
unnamed: U31.2, U32.1, U32.9, U33.1
unnamed: U31.4, U32.2, U32.10, U33.2
unnamed: U31.6, U32.4, U32.12
unnamed: U31.8, U32.5, U33.5, U33.13
unnamed: U31.12, U44.13
unnamed: U32.6, U35.1
unnamed: U32.8, U35.3
unnamed: U33.6, U35.5
unnamed: U33.8, U35.9
unnamed: U34.8, U49.2
unnamed: U35.2, U39.2, U39.13, U40.10, U41.5
unnamed: U35.4, U39.5, U40.2, U40.13, U41.10, U42.10, U43.2
unnamed: U35.6, U39.10, U40.5, U41.2, U41.13, U42.5, U42.13, U43.5
unnamed: U35.8, U42.2, U43.10
unnamed: U35.10, U44.5, U45.10
unnamed: U35.13, U42.3, U43.12
unnamed: U36.1 (J), U36.5 (Q), U39.12, U40.1, U40.4, U41.4, U43.1, U43.4
unnamed: U36.4 (K), U36.6 (~Q)
unnamed: U36.3 (Q), U38.11 (K), U41.9, U41.12, U42.4, U42.9, U42.12
unnamed: U36.2 (~Q), U38.8 (J)
unnamed: U36.10 (~R), U36.13 (~R), U37.10 (~R), U37.13 (~R), U38.10 (~R), U38.13 (~R), U48.10
unnamed: U36.8 (J), U37.3 (Q), U39.1, U39.4, U39.9, U40.9, U40.12, U41.1, U42.1, U43.9
unnamed: U36.11 (K), U37.2 (~Q)
unnamed: U31.13, U37.1 (J), U37.5 (Q), U47.5
unnamed: U37.4 (K), U37.6 (~Q)
unnamed: U37.11 (K), U38.2 (~Q)
unnamed: U38.1 (J), U38.5 (Q)
unnamed: U39.3, U44.4
unnamed: U39.6, U44.2
unnamed: U39.8, U44.1
unnamed: U39.11, U44.12
unnamed: U40.3, U44.10
unnamed: U40.6, U44.9
unnamed: U40.8, U45.13
unnamed: U40.11, U45.2
unnamed: U41.3, U45.1
unnamed: U41.6, U45.5
unnamed: U41.8, U45.4
unnamed: U41.11, U45.3
unnamed: U42.6, U48.1, U48.9
unnamed: U42.8, U46.2
unnamed: U42.11, U46.1
unnamed: U43.3, U46.5
unnamed: U43.6, U46.4
unnamed: U43.11, U49.4
unnamed: U44.6, U47.1
unnamed: U44.8, U47.3
unnamed: U45.6, U47.11
unnamed: U45.8, U49.1
unnamed: U45.9, U48.4
unnamed: U45.12, U47.9
unnamed: U46.8, U49.5
unnamed: U46.10, U48.6
unnamed: U46.11, U48.11
unnamed: U46.13, U49.11
unnamed: U48.8, U49.10
unnamed: U49.6, U49.9
unnamed: U49.3, U49.12
unnamed: U49.8, U49.13

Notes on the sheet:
(DM)
(LMR)
(I/O)
CONTROL MATRIX
INSTRUCTION DECODER
ADD
SUB
LDA
OUT
RING COUNTER

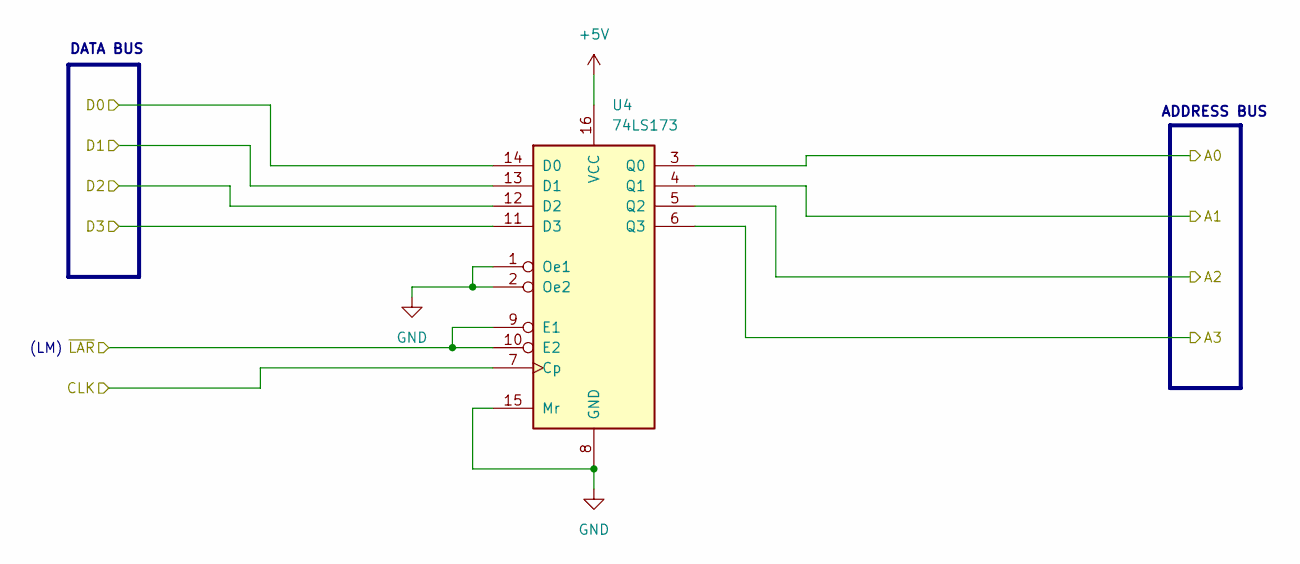
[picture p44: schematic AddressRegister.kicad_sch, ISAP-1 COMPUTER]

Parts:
U4: 74LS173; DIP-16_W7.62mm_LongPads

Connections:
+5V: U4.16 (VCC); also elsewhere on the board
/ALU/D0: U4.14 (D0); also elsewhere on the board
/ALU/D1: U4.13 (D1); also elsewhere on the board
/ALU/D2: U4.12 (D2); also elsewhere on the board
/ALU/D3: U4.11 (D3); also elsewhere on the board
/AddressRegister/A0: U4.3 (Q0); also elsewhere on the board
/AddressRegister/A1: U4.4 (Q1); also elsewhere on the board
/AddressRegister/A2: U4.5 (Q2); also elsewhere on the board
/AddressRegister/A3: U4.6 (Q3); also elsewhere on the board
/CLK: U4.7 (Cp); also elsewhere on the board
/~LAR: U4.9 (E1), U4.10 (E2)
GND: U4.1 (Oe1), U4.2 (Oe2), U4.8 (GND), U4.15 (Mr); also elsewhere on the board

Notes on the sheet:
DATA BUS
ADDRESS BUS
(LM)

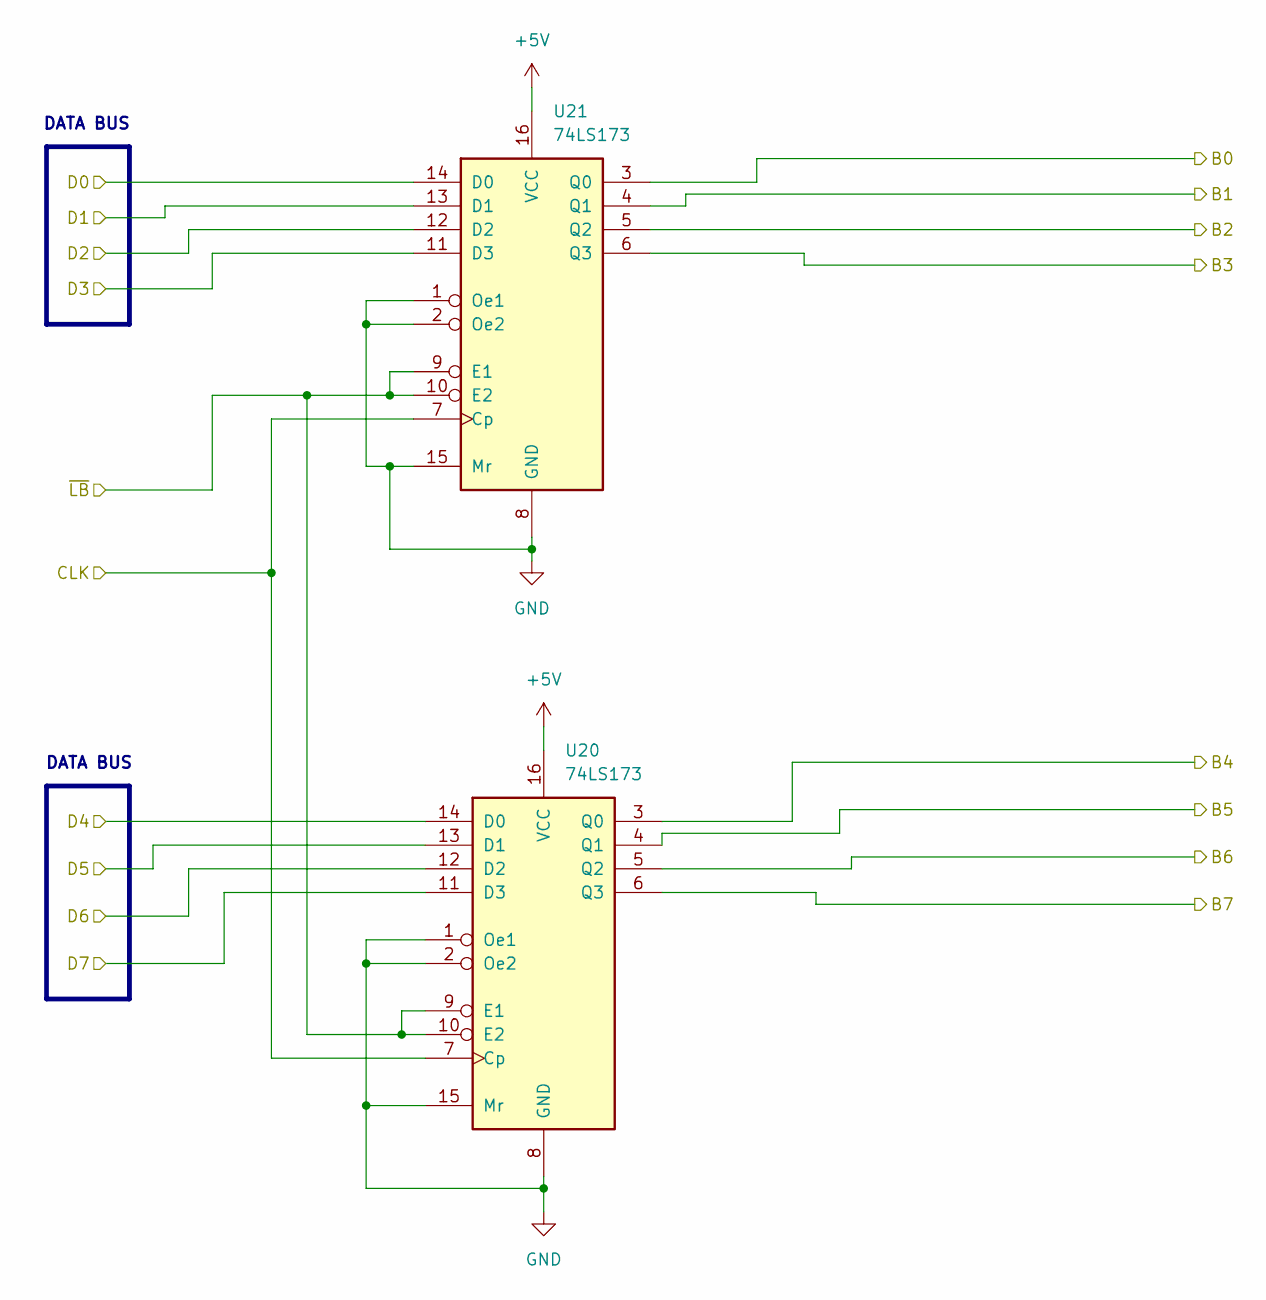
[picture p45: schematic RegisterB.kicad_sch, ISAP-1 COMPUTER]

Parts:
U20, U21: 74LS173; DIP-16_W7.62mm_LongPads

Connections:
+5V: U20.16 (VCC), U21.16 (VCC); also elsewhere on the board
/ALU/B0: U21.3 (Q0); also elsewhere on the board
/ALU/B1: U21.4 (Q1); also elsewhere on the board
/ALU/B2: U21.5 (Q2); also elsewhere on the board
/ALU/B3: U21.6 (Q3); also elsewhere on the board
/ALU/B4: U20.3 (Q0); also elsewhere on the board
/ALU/B5: U20.4 (Q1); also elsewhere on the board
/ALU/B6: U20.5 (Q2); also elsewhere on the board
/ALU/B7: U20.6 (Q3); also elsewhere on the board
/ALU/D0: U21.14 (D0); also elsewhere on the board
/ALU/D1: U21.13 (D1); also elsewhere on the board
/ALU/D2: U21.12 (D2); also elsewhere on the board
/ALU/D3: U21.11 (D3); also elsewhere on the board
/ALU/D4: U20.14 (D0); also elsewhere on the board
/ALU/D5: U20.13 (D1); also elsewhere on the board
/ALU/D6: U20.12 (D2); also elsewhere on the board
/ALU/D7: U20.11 (D3); also elsewhere on the board
/CLK: U20.7 (Cp), U21.7 (Cp); also elsewhere on the board
/~LB: U20.9 (E1), U20.10 (E2), U21.9 (E1), U21.10 (E2); also elsewhere on the board
GND: U20.1 (Oe1), U20.2 (Oe2), U20.8 (GND), U20.15 (Mr), U21.1 (Oe1), U21.2 (Oe2), U21.8 (GND), U21.15 (Mr); also elsewhere on the board

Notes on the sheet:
DATA BUS

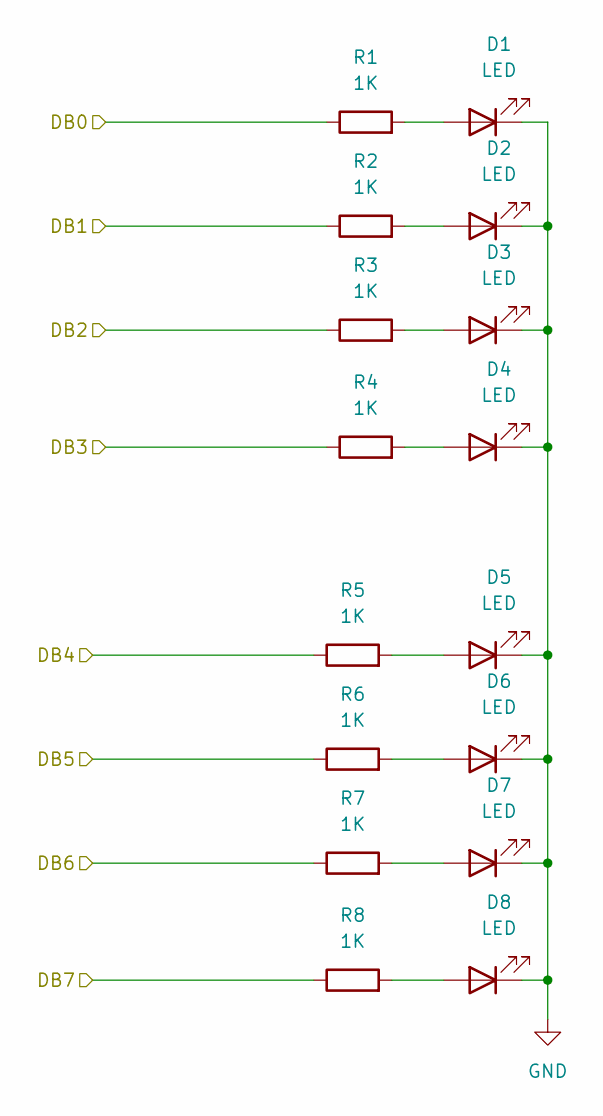
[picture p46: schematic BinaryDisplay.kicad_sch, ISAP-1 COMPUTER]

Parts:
D1, D2, D3, D4, D5, D6, D7, D8: LED; LED_D5.0mm
R1, R2, R3, R4, R5, R6, R7, R8: 1K; R_Axial_DIN0207_L6.3mm_D2.5mm_P7.62mm_Horizontal

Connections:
/BinaryDisplay/DB0: R1.1; also elsewhere on the board
/BinaryDisplay/DB1: R2.1; also elsewhere on the board
/BinaryDisplay/DB2: R3.1; also elsewhere on the board
/BinaryDisplay/DB3: R4.1; also elsewhere on the board
/BinaryDisplay/DB4: R5.1; also elsewhere on the board
/BinaryDisplay/DB5: R6.1; also elsewhere on the board
/BinaryDisplay/DB6: R7.1; also elsewhere on the board
/BinaryDisplay/DB7: R8.1; also elsewhere on the board
GND: D1.1 (K), D2.1 (K), D3.1 (K), D4.1 (K), D5.1 (K), D6.1 (K), D7.1 (K), D8.1 (K); also elsewhere on the board
unnamed: D1.2 (A), R1.2
unnamed: D2.2 (A), R2.2
unnamed: D3.2 (A), R3.2
unnamed: D4.2 (A), R4.2
unnamed: D5.2 (A), R5.2
unnamed: D6.2 (A), R6.2
unnamed: D7.2 (A), R7.2
unnamed: D8.2 (A), R8.2

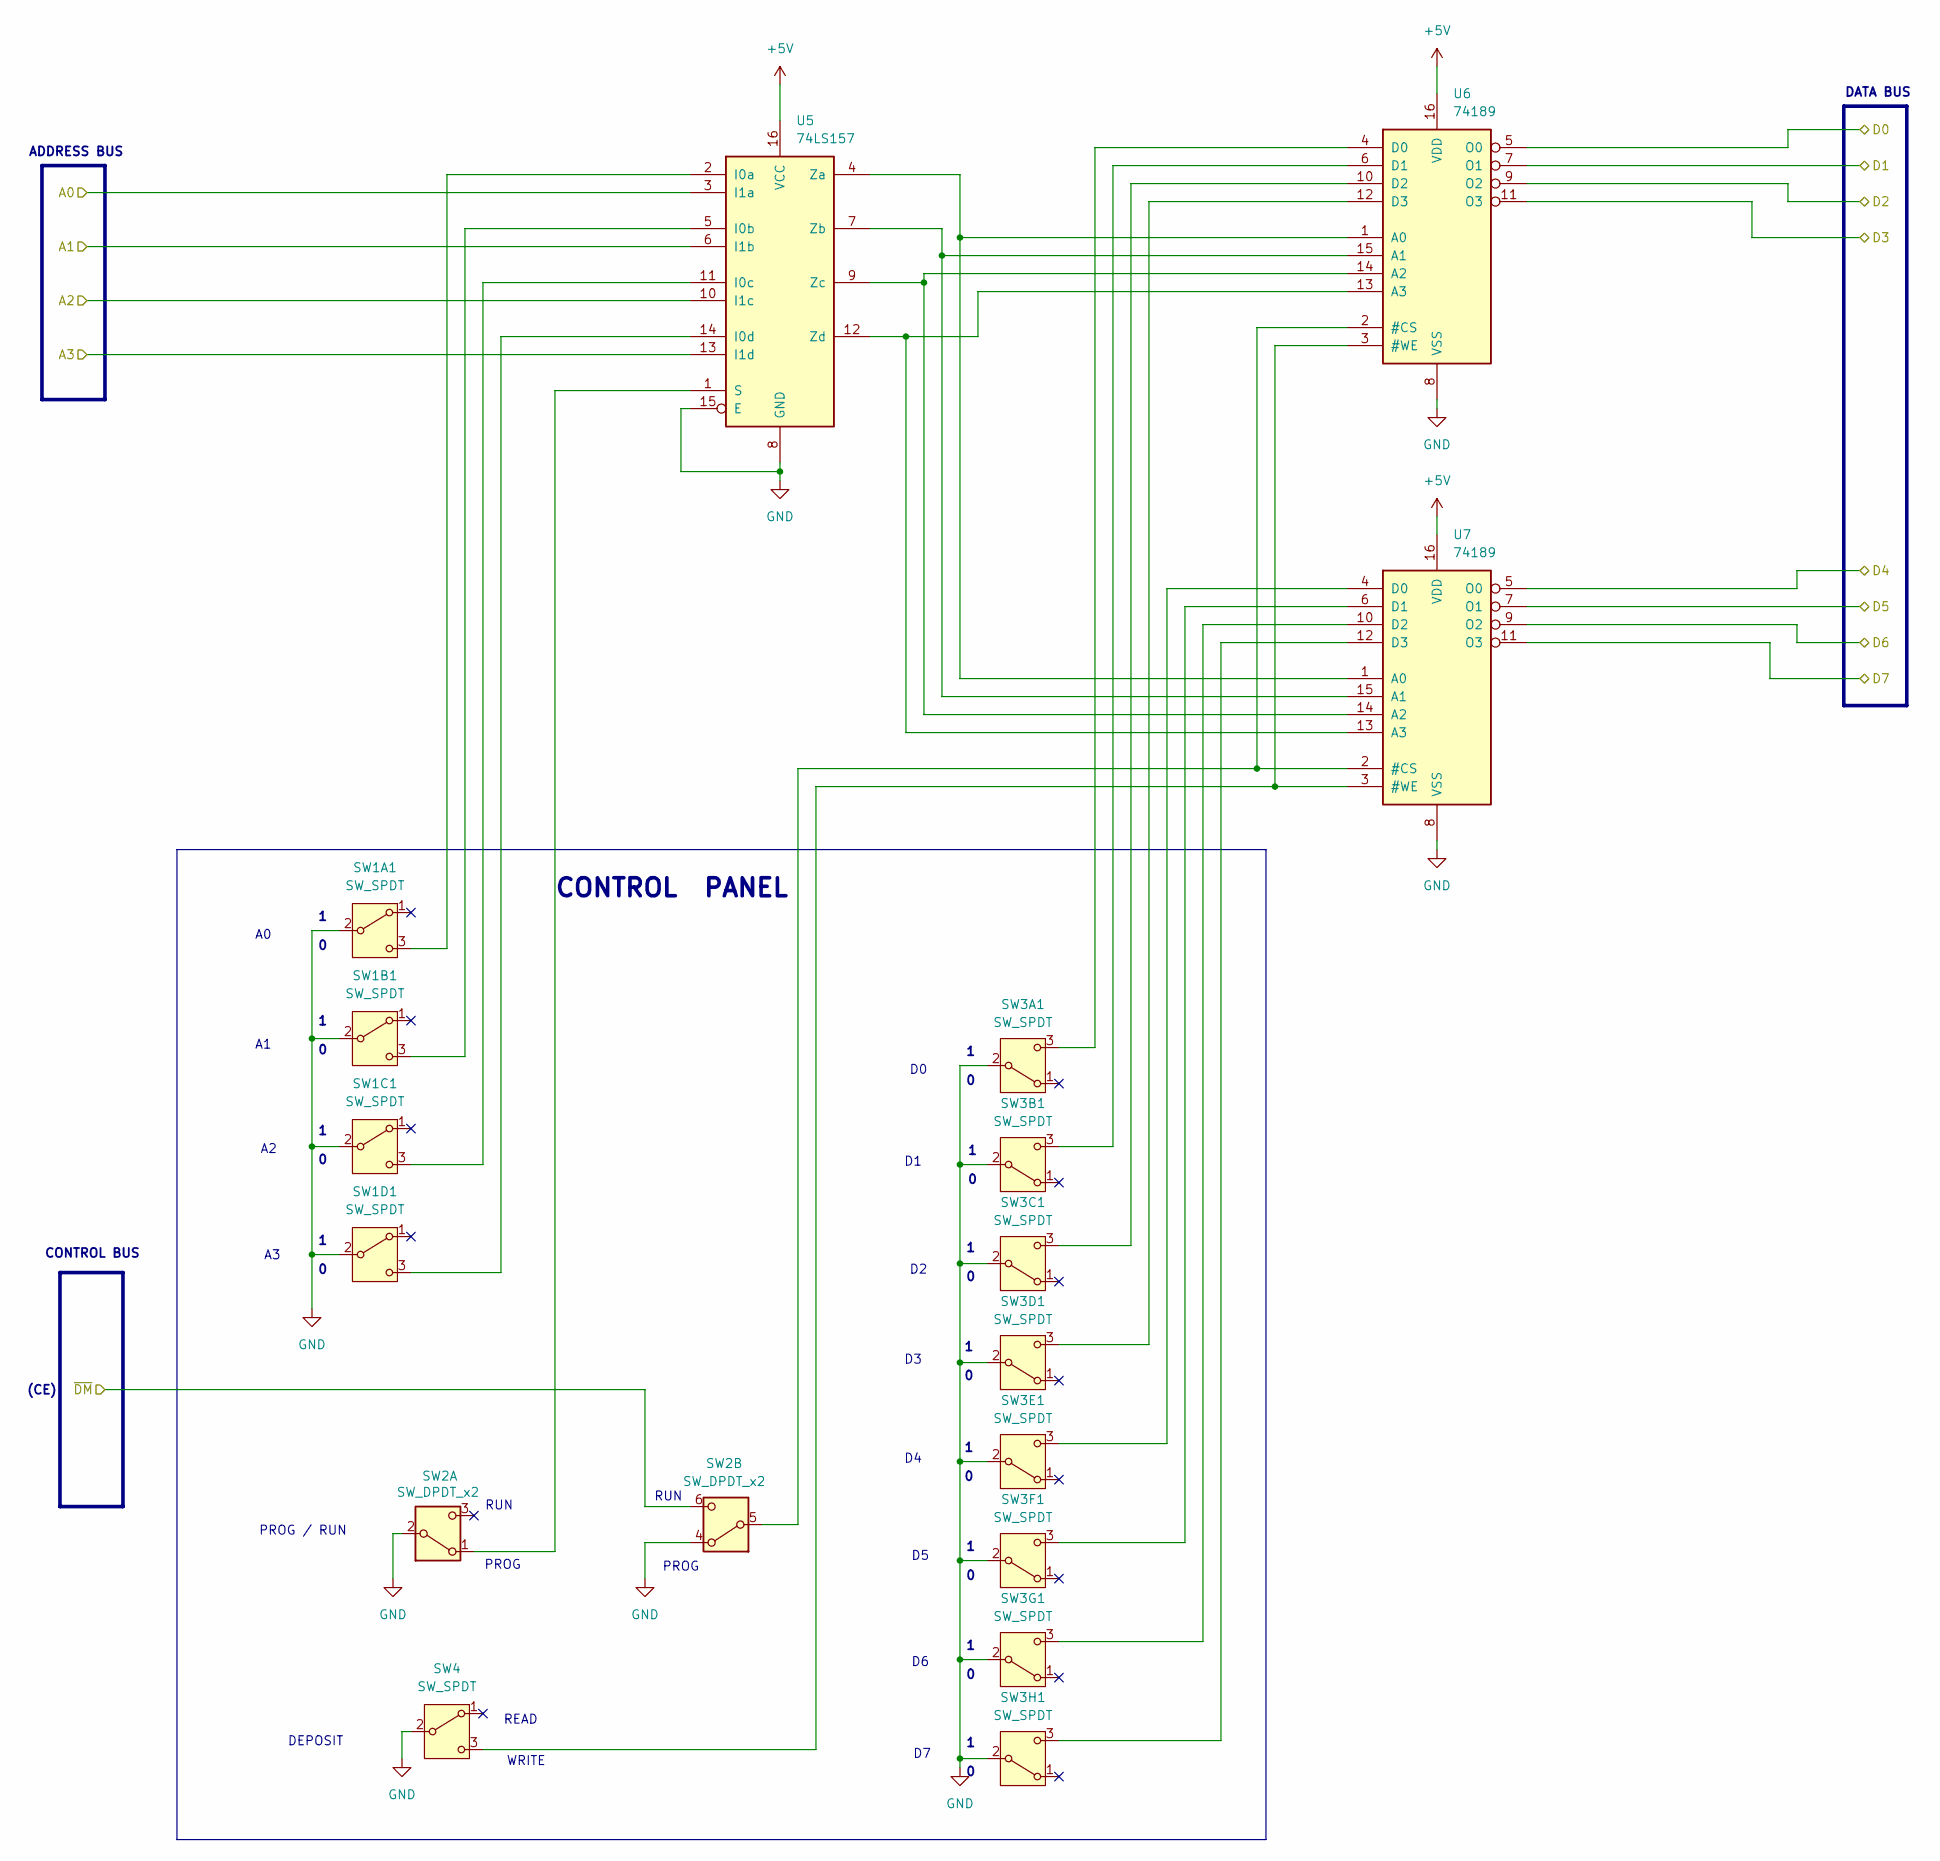
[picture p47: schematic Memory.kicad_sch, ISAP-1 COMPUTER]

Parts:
SW1A1, SW1B1, SW1C1, SW1D1, SW3A1, SW3B1, SW3C1, SW3D1, SW3E1, SW3F1, SW3G1, SW3H1, SW4: SW_SPDT; SW_Slide_SPDT_Straight_CK_OS102011MS2Q
SW2: SW_DPDT_x2; SW_CK_JS202011CQN_DPDT_Straight
U5: 74LS157; DIP-16_W7.62mm_LongPads
U6, U7: 74189; DIP-16_W7.62mm_LongPads

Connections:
+5V: U5.16 (VCC), U6.16 (VDD), U7.16 (VDD); also elsewhere on the board
/ALU/D0: U6.5 (O0); also elsewhere on the board
/ALU/D1: U6.7 (O1); also elsewhere on the board
/ALU/D2: U6.9 (O2); also elsewhere on the board
/ALU/D3: U6.11 (O3); also elsewhere on the board
/ALU/D4: U7.5 (O0); also elsewhere on the board
/ALU/D5: U7.7 (O1); also elsewhere on the board
/ALU/D6: U7.9 (O2); also elsewhere on the board
/ALU/D7: U7.11 (O3); also elsewhere on the board
/AddressRegister/A0: U5.3 (I1a); also elsewhere on the board
/AddressRegister/A1: U5.6 (I1b); also elsewhere on the board
/AddressRegister/A2: U5.10 (I1c); also elsewhere on the board
/AddressRegister/A3: U5.13 (I1d); also elsewhere on the board
/~DM: SW2.6 (C)
GND: SW1A1.2 (B), SW1B1.2 (B), SW1C1.2 (B), SW1D1.2 (B), SW2.2 (B), SW2.4 (A), SW3A1.2 (B), SW3B1.2 (B), SW3C1.2 (B), SW3D1.2 (B), SW3E1.2 (B), SW3F1.2 (B), SW3G1.2 (B), SW3H1.2 (B), SW4.2 (B), U5.8 (GND), U5.15 (E), U6.8 (VSS), U7.8 (VSS); also elsewhere on the board
unnamed: SW1A1.3 (C), U5.2 (I0a)
unnamed: SW1B1.3 (C), U5.5 (I0b)
unnamed: SW1C1.3 (C), U5.11 (I0c)
unnamed: SW1D1.3 (C), U5.14 (I0d)
unnamed: SW2.1 (A), U5.1 (S)
unnamed: SW2.5 (B), U6.2 (#CS), U7.2 (#CS)
unnamed: SW3A1.3 (C), U6.4 (D0)
unnamed: SW3B1.3 (C), U6.6 (D1)
unnamed: SW3C1.3 (C), U6.10 (D2)
unnamed: SW3D1.3 (C), U6.12 (D3)
unnamed: SW3E1.3 (C), U7.4 (D0)
unnamed: SW3F1.3 (C), U7.6 (D1)
unnamed: SW3G1.3 (C), U7.10 (D2)
unnamed: SW3H1.3 (C), U7.12 (D3)
unnamed: SW4.3 (C), U6.3 (#WE), U7.3 (#WE)
unnamed: U5.4 (Za), U6.1 (A0), U7.1 (A0)
unnamed: U5.7 (Zb), U6.15 (A1), U7.15 (A1)
unnamed: U5.9 (Zc), U6.14 (A2), U7.14 (A2)
unnamed: U5.12 (Zd), U6.13 (A3), U7.13 (A3)

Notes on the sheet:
1 0
PROG / RUN
READ
PROG
RUN
ADDRESS BUS
CONTROL PANEL
WRITE
DEPOSIT
DATA BUS
(CE)
CONTROL BUS

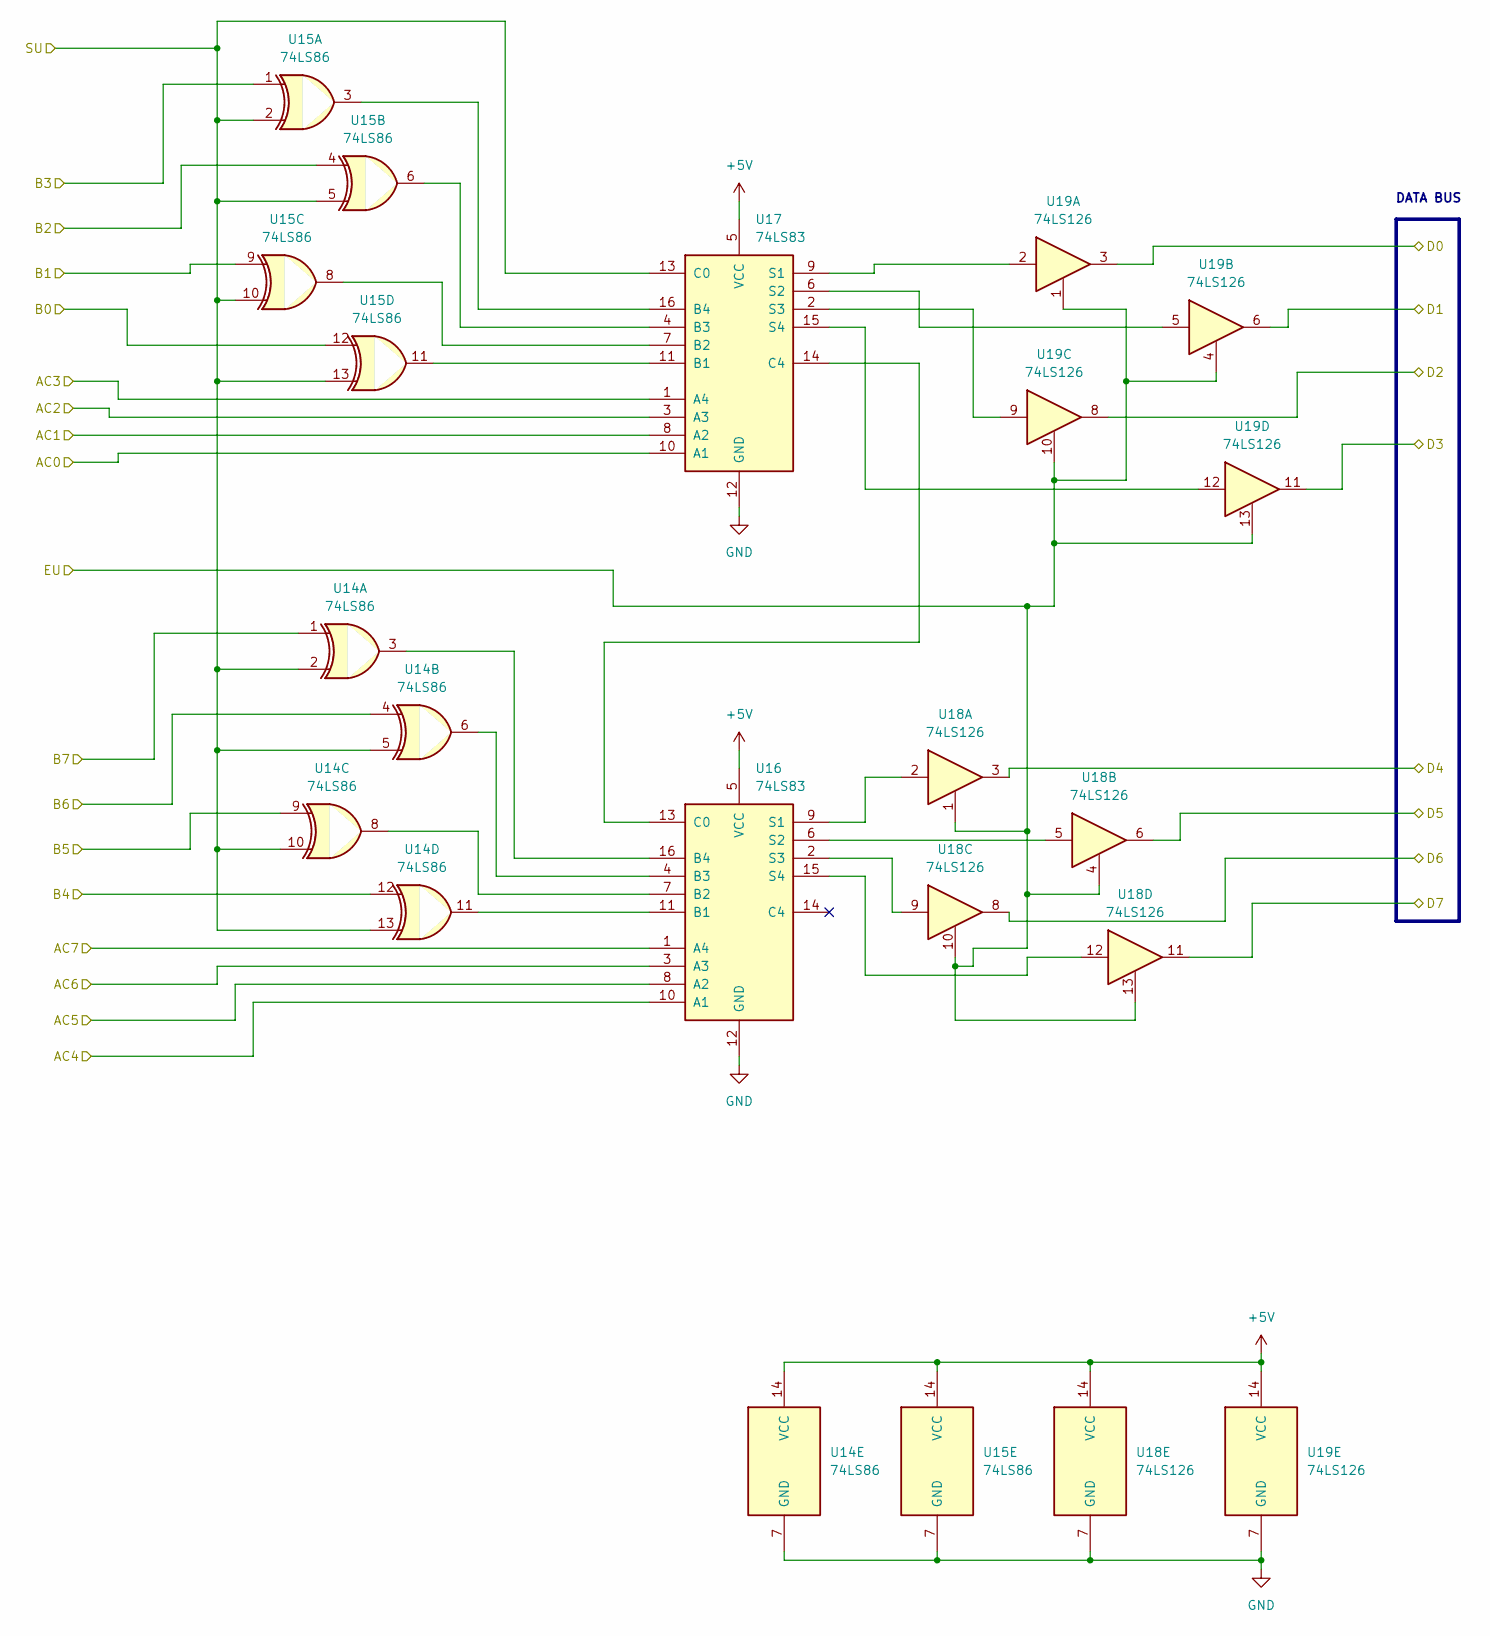
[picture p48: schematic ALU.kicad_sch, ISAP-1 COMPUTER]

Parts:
U14, U15: 74LS86; DIP-14_W7.62mm_LongPads
U16, U17: 74LS83; DIP-16_W7.62mm_LongPads
U18, U19: 74LS126; DIP-14_W7.62mm_LongPads

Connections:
+5V: U14.14 (VCC), U15.14 (VCC), U16.5 (VCC), U17.5 (VCC), U18.14 (VCC), U19.14 (VCC); also elsewhere on the board
/ALU/AC0: U17.10 (A1); also elsewhere on the board
/ALU/AC1: U17.8 (A2); also elsewhere on the board
/ALU/AC2: U17.3 (A3); also elsewhere on the board
/ALU/AC4: U16.10 (A1); also elsewhere on the board
/ALU/AC5: U16.8 (A2); also elsewhere on the board
/ALU/AC6: U16.3 (A3); also elsewhere on the board
/ALU/AC7: U16.1 (A4); also elsewhere on the board
/ALU/B0: U15.12; also elsewhere on the board
/ALU/B1: U15.9; also elsewhere on the board
/ALU/B2: U15.4; also elsewhere on the board
/ALU/B3: U15.1; also elsewhere on the board
/ALU/B4: U14.12; also elsewhere on the board
/ALU/B5: U14.9; also elsewhere on the board
/ALU/B6: U14.4; also elsewhere on the board
/ALU/B7: U14.1; also elsewhere on the board
/ALU/D0: U19.3; also elsewhere on the board
/ALU/D1: U19.6; also elsewhere on the board
/ALU/D2: U19.8; also elsewhere on the board
/ALU/D3: U19.11; also elsewhere on the board
/ALU/D4: U18.3; also elsewhere on the board
/ALU/D5: U18.6; also elsewhere on the board
/ALU/D6: U18.8; also elsewhere on the board
/ALU/D7: U18.11; also elsewhere on the board
/EA: U17.1 (A4); also elsewhere on the board
/EU: U18.1, U18.4, U18.10, U18.13, U19.1, U19.4, U19.10, U19.13; also elsewhere on the board
/SU: U14.2, U14.5, U14.10, U14.13, U15.2, U15.5, U15.10, U15.13, U17.13 (C0); also elsewhere on the board
GND: U14.7 (GND), U15.7 (GND), U16.12 (GND), U17.12 (GND), U18.7 (GND), U19.7 (GND); also elsewhere on the board
unnamed: U14.11, U16.11 (B1)
unnamed: U14.8, U16.7 (B2)
unnamed: U14.6, U16.4 (B3)
unnamed: U14.3, U16.16 (B4)
unnamed: U16.13 (C0), U17.14 (C4)
unnamed: U16.9 (S1), U18.2
unnamed: U16.6 (S2), U18.5
unnamed: U16.2 (S3), U18.9
unnamed: U16.15 (S4), U18.12
unnamed: U15.11, U17.11 (B1)
unnamed: U15.8, U17.7 (B2)
unnamed: U15.6, U17.4 (B3)
unnamed: U15.3, U17.16 (B4)
unnamed: U17.9 (S1), U19.2
unnamed: U17.6 (S2), U19.5
unnamed: U17.2 (S3), U19.9
unnamed: U17.15 (S4), U19.12

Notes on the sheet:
DATA BUS

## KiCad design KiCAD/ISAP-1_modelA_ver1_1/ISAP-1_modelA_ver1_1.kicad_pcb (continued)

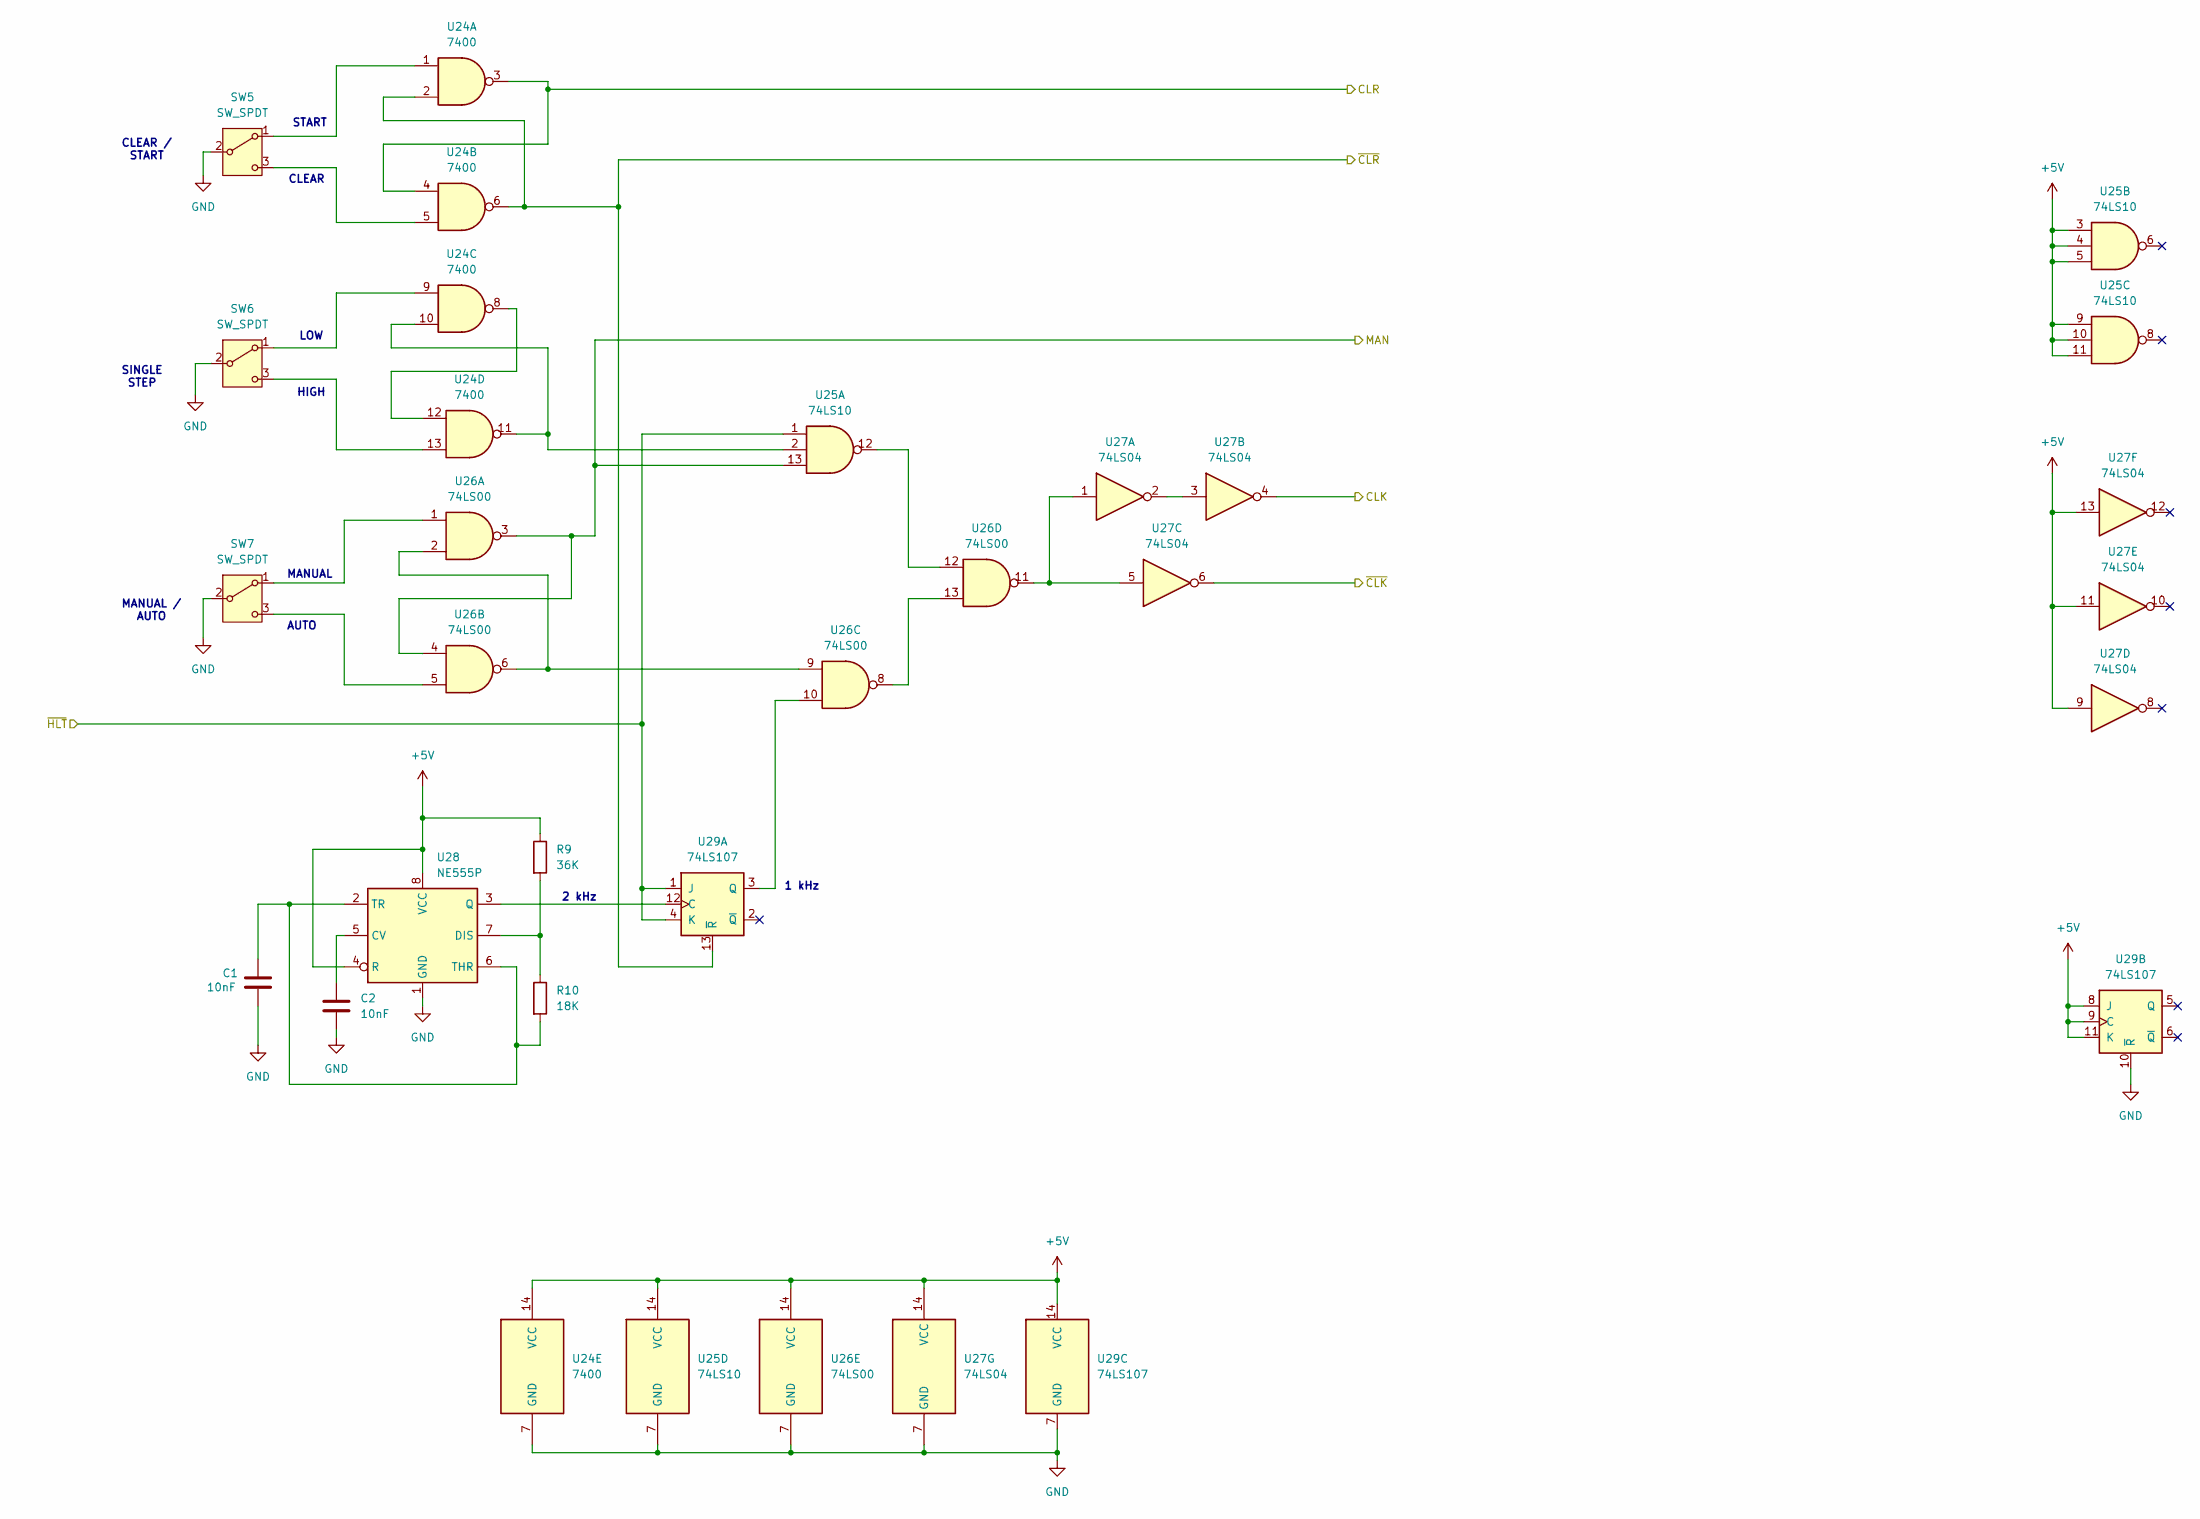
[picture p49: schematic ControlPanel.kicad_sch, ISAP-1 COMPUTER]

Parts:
C1, C2: 10nF; C_Disc_D5.0mm_W2.5mm_P5.00mm
R9: 36K; R_Axial_DIN0207_L6.3mm_D2.5mm_P7.62mm_Horizontal
R10: 18K; R_Axial_DIN0207_L6.3mm_D2.5mm_P7.62mm_Horizontal
SW5, SW6, SW7: SW_SPDT; SW_Slide_SPDT_Straight_CK_OS102011MS2Q
U24: 7400; DIP-14_W7.62mm_LongPads
U25: 74LS10; DIP-14_W7.62mm_LongPads
U26: 74LS00; DIP-14_W7.62mm_LongPads
U27: 74LS04; DIP-14_W7.62mm_LongPads
U28: NE555P; DIP-8_W7.62mm
U29: 74LS107; DIP-14_W7.62mm_LongPads

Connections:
+5V: R9.1, U24.14 (VCC), U25.3, U25.4, U25.5, U25.9, U25.10, U25.11, U25.14 (VCC), U26.14 (VCC), U27.9, U27.11, U27.13, U27.14 (VCC), U28.4 (R), U28.8 (VCC), U29.8 (J), U29.9 (C), U29.11 (K), U29.14 (VCC); also elsewhere on the board
/CLK: U27.4; also elsewhere on the board
/CLR: U24.3, U24.4; also elsewhere on the board
/HLT: U25.1, U29.1 (J), U29.4 (K); also elsewhere on the board
/MAN: U25.13, U26.3, U26.4
/~CLK: U27.6; also elsewhere on the board
/~CLR: U24.2, U24.6, U29.13 (~R); also elsewhere on the board
GND: C1.2, C2.2, SW5.2 (B), SW6.2 (B), SW7.2 (B), U24.7 (GND), U25.7 (GND), U26.7 (GND), U27.7 (GND), U28.1 (GND), U29.7 (GND), U29.10 (~R); also elsewhere on the board
unnamed: SW5.1 (A), U24.1
unnamed: SW5.3 (C), U24.5
unnamed: SW6.1 (A), U24.9
unnamed: SW6.3 (C), U24.13
unnamed: SW7.1 (A), U26.1
unnamed: SW7.3 (C), U26.5
unnamed: U24.10, U24.11, U25.2
unnamed: U24.8, U24.12
unnamed: U25.12, U26.12
unnamed: U26.2, U26.6, U26.9
unnamed: U26.11, U27.1, U27.5
unnamed: U26.8, U26.13
unnamed: U27.2, U27.3
unnamed: C2.1, U28.5 (CV)
unnamed: R9.2, R10.1, U28.7 (DIS)
unnamed: U28.3 (Q), U29.12 (C)
unnamed: C1.1, R10.2, U28.2 (TR), U28.6 (THR)
unnamed: U26.10, U29.3 (Q)

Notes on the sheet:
2 kHz
CLEAR
AUTO
MANUAL / AUTO
SINGLE STEP
LOW
MANUAL
1 kHz
HIGH
START
CLEAR / START

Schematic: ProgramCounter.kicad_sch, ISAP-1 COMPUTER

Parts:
U1, U2: 74LS107; DIP-14_W7.62mm_LongPads
U3: 74LS126; DIP-14_W7.62mm_LongPads

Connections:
+5V: U1.14 (VCC), U2.14 (VCC), U3.14 (VCC); also elsewhere on the board
/ALU/D0: U3.11; also elsewhere on the board
/ALU/D1: U3.8; also elsewhere on the board
/ALU/D2: U3.6; also elsewhere on the board
/ALU/D3: U3.3; also elsewhere on the board
/CP: U1.1 (J), U1.4 (K), U1.8 (J), U1.11 (K), U2.1 (J), U2.4 (K), U2.8 (J), U2.11 (K); also elsewhere on the board
/EP: U3.1, U3.4, U3.10, U3.13; also elsewhere on the board
/~CLK: U2.9 (C); also elsewhere on the board
/~CLR: U1.10 (~R), U1.13 (~R), U2.10 (~R), U2.13 (~R); also elsewhere on the board
GND: U1.7 (GND), U2.7 (GND), U3.7 (GND); also elsewhere on the board
unnamed: U1.5 (Q), U1.12 (C), U3.5
unnamed: U1.3 (Q), U3.2
unnamed: U1.9 (C), U2.3 (Q), U3.9
unnamed: U2.5 (Q), U2.12 (C), U3.12

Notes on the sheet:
DATA BUS

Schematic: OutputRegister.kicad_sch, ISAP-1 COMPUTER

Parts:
U22, U23: 74LS173; DIP-16_W7.62mm_LongPads

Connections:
+5V: U22.16 (VCC), U23.16 (VCC); also elsewhere on the board
/ALU/D0: U23.14 (D0); also elsewhere on the board
/ALU/D1: U23.13 (D1); also elsewhere on the board
/ALU/D2: U23.12 (D2); also elsewhere on the board
/ALU/D3: U23.11 (D3); also elsewhere on the board
/ALU/D4: U22.14 (D0); also elsewhere on the board
/ALU/D5: U22.13 (D1); also elsewhere on the board
/ALU/D6: U22.12 (D2); also elsewhere on the board
/ALU/D7: U22.11 (D3); also elsewhere on the board
/BinaryDisplay/DB0: U23.3 (Q0); also elsewhere on the board
/BinaryDisplay/DB1: U23.4 (Q1); also elsewhere on the board
/BinaryDisplay/DB2: U23.5 (Q2); also elsewhere on the board
/BinaryDisplay/DB3: U23.6 (Q3); also elsewhere on the board
/BinaryDisplay/DB4: U22.3 (Q0); also elsewhere on the board
/BinaryDisplay/DB5: U22.4 (Q1); also elsewhere on the board
/BinaryDisplay/DB6: U22.5 (Q2); also elsewhere on the board
/BinaryDisplay/DB7: U22.6 (Q3); also elsewhere on the board
/CLK: U22.7 (Cp), U23.7 (Cp); also elsewhere on the board
/~LO: U22.9 (E1), U22.10 (E2), U23.9 (E1), U23.10 (E2); also elsewhere on the board
GND: U22.1 (Oe1), U22.2 (Oe2), U22.8 (GND), U22.15 (Mr), U23.1 (Oe1), U23.2 (Oe2), U23.8 (GND), U23.15 (Mr); also elsewhere on the board

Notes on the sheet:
(I/O)

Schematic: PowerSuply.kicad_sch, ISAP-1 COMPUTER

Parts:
C3: 1000uF; CP_Radial_D10.0mm_P5.00mm
C4: 220uF; CP_Radial_D5.0mm_P2.00mm
D9, D10, D11, D12: 1N4001; D_DO-41_SOD81_P10.16mm_Horizontal
F1: 3/8A (0.4A); Fuseholder_Clip-5x20mm_Schurter_CQM_Inline_P20.60x5.00mm_D1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
HS1: Heatsink; Heatsink_AAVID_590302B03600G
P1: IEC_60320_C13_Plug; SolderWire-1.5sqmm_1x03_P6mm_D1.7mm_OD3mm
T1: F-25X 115V(240V) /12V 1.5A; Transformer_CHK_EI54-16VA_Neutral
U30: LM340T-5; TO-220-3_Vertical

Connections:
+5V: C4.1, U30.3 (VO); also elsewhere on the board
GND: C3.2, C4.2, D10.2 (A), D12.2 (A), U30.2 (GND); also elsewhere on the board
unnamed: D9.2 (A), D10.1 (K), T1.4 (SB)
unnamed: D11.2 (A), D12.1 (K), T1.3 (SA)
unnamed: C3.1, D9.1 (K), D11.1 (K), U30.1 (VI)
unnamed: F1.1, P1.2 (L)
unnamed: P1.1 (N), T1.2 (AB)
unnamed: F1.2, T1.1 (AA)

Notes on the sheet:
Transformer 18 VA
Max 1.5A
15.37V
MAIN 115 VAC or 240 VAC

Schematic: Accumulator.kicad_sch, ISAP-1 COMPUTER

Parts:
U10, U11: 74LS173; DIP-16_W7.62mm_LongPads
U12, U13: 74LS126; DIP-14_W7.62mm_LongPads

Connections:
+5V: U10.16 (VCC), U11.16 (VCC), U12.14 (VCC), U13.14 (VCC); also elsewhere on the board
/ALU/AC0: U11.3 (Q0), U12.2; also elsewhere on the board
/ALU/AC1: U11.4 (Q1), U12.5; also elsewhere on the board
/ALU/AC2: U11.5 (Q2), U12.9; also elsewhere on the board
/ALU/AC4: U10.3 (Q0), U13.2; also elsewhere on the board
/ALU/AC5: U10.4 (Q1), U13.5; also elsewhere on the board
/ALU/AC6: U10.5 (Q2), U13.9; also elsewhere on the board
/ALU/AC7: U10.6 (Q3), U13.12; also elsewhere on the board
/ALU/D0: U11.14 (D0), U12.3; also elsewhere on the board
/ALU/D1: U11.13 (D1), U12.6; also elsewhere on the board
/ALU/D2: U11.12 (D2), U12.8; also elsewhere on the board
/ALU/D3: U11.11 (D3), U12.11; also elsewhere on the board
/ALU/D4: U10.14 (D0), U13.3; also elsewhere on the board
/ALU/D5: U10.13 (D1), U13.6; also elsewhere on the board
/ALU/D6: U10.12 (D2), U13.8; also elsewhere on the board
/ALU/D7: U10.11 (D3), U13.11; also elsewhere on the board
/CLK: U10.7 (Cp), U11.7 (Cp); also elsewhere on the board
/EA: U11.6 (Q3), U12.1, U12.4, U12.10, U12.12, U12.13, U13.1, U13.4, U13.10, U13.13; also elsewhere on the board
/~LA: U10.9 (E1), U10.10 (E2), U11.9 (E1), U11.10 (E2); also elsewhere on the board
GND: U10.1 (Oe1), U10.2 (Oe2), U10.8 (GND), U10.15 (Mr), U11.1 (Oe1), U11.2 (Oe2), U11.8 (GND), U11.15 (Mr), U12.7 (GND), U13.7 (GND); also elsewhere on the board

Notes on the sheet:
DATA BUS

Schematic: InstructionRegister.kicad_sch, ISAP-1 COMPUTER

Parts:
U8, U9: 74LS173; DIP-16_W7.62mm_LongPads

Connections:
+5V: U8.16 (VCC), U9.16 (VCC); also elsewhere on the board
/ALU/D0: U9.3 (Q0), U9.14 (D0); also elsewhere on the board
/ALU/D1: U9.4 (Q1), U9.13 (D1); also elsewhere on the board
/ALU/D2: U9.5 (Q2), U9.12 (D2); also elsewhere on the board
/ALU/D3: U9.6 (Q3), U9.11 (D3); also elsewhere on the board
/ALU/D4: U8.14 (D0); also elsewhere on the board
/ALU/D5: U8.13 (D1); also elsewhere on the board
/ALU/D6: U8.12 (D2); also elsewhere on the board
/ALU/D7: U8.11 (D3); also elsewhere on the board
/CLK: U8.7 (Cp), U9.7 (Cp); also elsewhere on the board
/CLR: U8.15 (Mr); also elsewhere on the board
/ControlUnit/I4: U8.3 (Q0); also elsewhere on the board
/ControlUnit/I5: U8.4 (Q1); also elsewhere on the board
/ControlUnit/I6: U8.5 (Q2); also elsewhere on the board
/ControlUnit/I7: U8.6 (Q3); also elsewhere on the board
/~EI: U9.1 (Oe1), U9.2 (Oe2); also elsewhere on the board
/~LI: U8.9 (E1), U8.10 (E2), U9.9 (E1), U9.10 (E2); also elsewhere on the board
GND: U8.1 (Oe1), U8.2 (Oe2), U8.8 (GND), U9.8 (GND), U9.15 (Mr); also elsewhere on the board

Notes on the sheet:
DATA BUS

Board: 2 copper layers, 96 parts (0 on the bottom side), 191 nets, no tracks yet.

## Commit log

2024-11-30 new file: KiCAD/ISAP-1 ver1/ALU.kicad_sch
    [ALU.kicad_sch, Accumulator.kicad_sch, AddressRegister.kicad_sch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]
2024-12-05 deleted: KiCAD/ISAP-1 ver1/ALU.kicad_sch
    [ALU.kicad_sch, Accumulator.kicad_sch, AddressRegister.kicad_sch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]
2024-12-05 new file: KiCAD/ISAP-1_ver1/ALU.kicad_sch
    [ALU.kicad_sch, Accumulator.kicad_sch, AddressRegister.kicad_sch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]
2024-12-06 renamed: KiCAD/ISAP-1_ver1/ALU.kicad_sch -> KiCAD/ISAP-1_revA_ver1/ALU.kicad_sch
    [ALU.kicad_sch, Accumulator.kicad_sch, AddressRegister.kicad_sch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]
2024-12-06 new file: KiCAD/ISAP-1_revB_ver1/ALU.kicad_sch
    [ALU.kicad_sch, Accumulator.kicad_sch, AddressRegister.kicad_sch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]
2024-12-06 deleted: KiCAD/ISAP-1_revB_ver1/ISAP-1_revB_ver1-backups/ISAP-1_revB_ver1-2024-12-06_040022.zip
2025-01-19 new file: KiCAD/ISAP-1_modelA_ver1_1/ALU.kicad_sch
    [ALU.kicad_sch, Accumulator.kicad_sch, AddressRegister.kicad_sch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]
2025-01-22 new file: KiCAD/ISAP-1_modelA_ver1_0.zip
    [ALU.kicad_sch, Accumulator.kicad_sch, AddressRegister.kicad_sch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]
2025-01-22 new file: KiCAD/ISAP-1_modelA_ver1_1.zip
    [ALU.kicad_sch, Accumulator.kicad_sch, AddressRegister.kicad_sch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]
2025-01-23 modified: KiCAD/ISAP-1_modelA_ver1_0.zip
2025-01-23 modified: KiCAD/ISAP-1_modelA_ver1_1.zip
2025-01-24 new file: KiCAD/ISAP-1_modelB_ver1_0.zip new file: Pictures/Figure25.png
    [ALU.kicad_sch, Accumulator.kicad_sch, AddressRegister.kicad_sch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]
2025-01-25 new file: KiCAD/ISAP-1_modelB_ver1_1.zip
2025-01-31 new file: KiCAD/ISAP-1_modelB_ver1_2.zip
2025-04-21 new file: KiCAD/ISAP-1_TTL_ver1_0.zip
2025-06-21 new file: KiCAD/ISAP1_TTL_SBC_ver1_0.zip
2025-08-21 new file: KiCAD/ISAP-1_TTL_CPU_1_0.zip
